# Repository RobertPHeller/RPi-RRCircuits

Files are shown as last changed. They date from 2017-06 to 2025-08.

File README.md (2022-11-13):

# RPi-RRCircuits

This is a collection of Model Railroad open hardware and open source projects,
using LCC, OpenMRN, and OpenMRN-lite, for the following MCUs and SBCs:

Raspberry Pi, generally as HATs for the "B" flavors (RPi2B, RPi3B and RPi4B).
  (Directories with "HAT" at the end are for these boards.)

Beagle boards, including capes for BeagleBone Black and baseboards for
  PocketBeagles.
  (Directories with "CAPE" at the end are for BeagleBone Blacks,
   directories starting with "BBB" are also boards for the BeagleBone Black,
   directories starting with "PB" or "PocketBeagle" are for the PocketBeagles -
   these boards assume male header pins soldered to the bottom of the 
   PocketBeagle that insert into female header sockets on the base board.)

ESP32 (mostly meant for the Lilygo TTGO-T1 board)
  (Directories starting with "ESP32" are for this board.)

There are a few projects for other boards, including MetroMini (an Adafruit 
mini board that is a Arduino UNO clone), Tiva, and STM's Nucleo board.  The 
directory names will include the name of the board.

Directories ending in OpenMRN contain the Raspberry Pi and Beagle board
software for the various boards.  

These projects were created using Kicad 2013.06.11
(https://launchpad.net/kicad) under CentOS 6 and Kicad 4.0.7 under Ubuntu
18.04. Each subdirectory is one project, and contains a schematic and PCB
design or contains a program for one (or more) projects. There is also
software for the boards using OpenMRN (C++ library for OpenLCB/LCC) for these
projects.

There is a README in each project dir.

## Availble Projects:

1. [16DriverOutputCape](https://github.com/RobertPHeller/RPi-RRCircuits/tree/master/16DriverOutputCape)

    > This is a MCP23017 with two octal buffers meant to drive 16 LEDs (such as 
    > signal lamps). No PWM or special effects.  This board is a Cape for a 
    > BeagleBone Black or Green.  Has address jumpers for the MCP23017 and can be 
    > stacked -- up to 8 of these capes for up to 128 LEDS -- each board has power 
    > terminals for the LEDs.

1. [16DriverOutputHAT](https://github.com/RobertPHeller/RPi-RRCircuits/tree/master/16DriverOutputHAT)

    > This is a MCP23017 with two octal buffers meant to drive 16 LEDs (such as 
    > signal lamps). No PWM or special effects.  This board is a HAT for a 
    > Raspberry Pi 2, 3, or 4.  Has address jumpers for the MCP23017 and can be 
    > stacked -- up to 8 of these hats for up to 128 LEDS -- each board has power 
    > terminals for the LEDs.

1. [16DriverOutputOpenMRN](https://github.com/RobertPHeller/RPi-RRCircuits/tree/master/16DriverOutputOpenMRN)

    > The is the OpenMRN (OpenLCB/LCC) program code for the 16DriverOutput HAT or 
    > Cape boards. Can be build on either a BeagleBoard or a Raspberry Pi for 
    > either. 

1. [16LEDDriver23017SMD](https://github.com/RobertPHeller/RPi-RRCircuits/tree/master/16LEDDriver23017SMD)

    > This is a SMD variant of 16DriverOutputHAT.

1. [16PWMLedDriverCape](https://github.com/RobertPHeller/RPi-RRCircuits/tree/master/16PWMLedDriverCape)

    > This is a PCA9685 with two octal buffers meant to drive 16 LEDs (such as 
    > signal lamps).  This board is much like 16DriverOutputHat, but uses a PWM chip 
    > to allow for special effects and allows for brightness adjustment.  Has 
    > address jumpers for the PCA9685 and can be stacked -- up to 64 boards (WOW) 
    > for up to 1024 LEDs (WOW) -- each board has power terminals for the LEDs.

1. [16PWMLedDriverHat](https://github.com/RobertPHeller/RPi-RRCircuits/tree/master/16PWMLedDriverHat)

    > This is a PCA9685 with two octal buffers meant to drive 16 LEDs (such as 
    > signal lamps).  This board is much like 16DriverOutputHat, but uses a PWM chip 
    > to allow for special effects and allows for brightness adjustment.  Has 
    > address jumpers for the PCA9685 and can be stacked -- up to 64 boards (WOW) 
    > for up to 1024 LEDs (WOW) -- each board has power terminals for the LEDs.

1. [16PWMLedDriverOpenMRN](https://github.com/RobertPHeller/RPi-RRCircuits/tree/master/16PWMLedDriverOpenMRN)

    > This is the OpenMRN (OpenLCB/LCC) program for the 16PWMLedDriver* boards (RPi
    > Hat, BBB Cape, and PocketBeagle board). Can be build on either a BeagleBoard 
    > or a Raspberry Pi for either.

1. [16PWMLedDriverPocketBeagle](https://github.com/RobertPHeller/RPi-RRCircuits/tree/master/16PWMLedDriverPocketBeagle)

    > This is a PCA9685 with two octal buffers meant to drive 16 LEDs (such as
    > signal lamps). This board is much like 16DriverOutputCape, but uses a PWM chip
    > to allow for special effects and allows for brightness adjustment. Has address
    > jumpers for the PCA9685, includes a CAN transceiver with LCC network
    > connectors (RJ45s), 5V power supply for the PocketBeagle, and uses LCC power
    > for the LEDS. It uses female headers for the PocketBeagle (presumes male pin
    > headers soldered to the underside of the PocketBeagle).

1. [BBBCommandStation](https://github.com/RobertPHeller/RPi-RRCircuits/tree/master/BBBCommandStation)

    > Early BeagleBone Black LCC/DCC Command Station board set -- two boards, a cape 
    > and a power board.  Does not include RailComm support.

1. [BBBCommandStationOpenMRN](https://github.com/RobertPHeller/RPi-RRCircuits/tree/master/BBBCommandStationOpenMRN)

    > This is the program for the Beagle Board LCC/DCC/Railcom command 
    > station.  It uses OpenMRN to interface with tha LCC/OpenLCB network
    > to implement a LCC/OpenLCB aware command station node that can 
    > operate DCC/Railcom locomotives.  It should work with any of the
    > Beagle Board addon boards I have designed.  It uses the AM335X's
    > PRUs to generate the DCC signals.  It ises the OpenMRN Console
    > class to communicate over a Tcp/Ip channel with a Tcl/Tk coded
    > GUI program to provide a user friendly point-and-click high level
    > user interface.  

1. [BBBHalfSiding](https://github.com/RobertPHeller/RPi-RRCircuits/tree/master/BBBHalfSiding)

    > Early HalfSiding cape for the Beagle Bone Black. A somewhat all-in-one board
    > for the Beagle Bone Black to manage one half of a siding. This something of a
    > "kitchen sink" board and proably awkard in practice. Probably better off
    > stacking several separate special purpose capes.  I mostly did this as a 
    > "thought experiment" to see what this would look like.  Oh, if it used SMD 
    > parts it might be more compact and might be practical as a single board.

1. [ButtonHat](https://github.com/RobertPHeller/RPi-RRCircuits/tree/master/ButtonHat)

    > This is a RPi HAT board to interface up to 12 push buttons with hardware 
    > debouncing (using 74ahc14 Hex Schmitt-Trigger Inverters) to a RPi.  Jumpers 
    > are used to map the buttons to GPIO pins.  This was a simple "thought 
    > experiment" to see if this was possible.

1. [CANHat](https://github.com/RobertPHeller/RPi-RRCircuits/tree/master/CANHat)

    > This is the original CAN Hat, using the MCP2515 CAN IF Chip and a MCP2551 
    > transceiver chip.

1. [CANHat2](https://github.com/RobertPHeller/RPi-RRCircuits/tree/master/CANHat2)

    > This is the second incarnation of the CAN Hat, also using the MCP2515 and 
    > MCP2551 chips.

1. [CANHat3](https://github.com/RobertPHeller/RPi-RRCircuits/tree/master/CANHat3)

    > This is the third incarnation of the CAN Hat, also using the MCP2515 and 
    > MCP2551 chips.

1. [DCCOD_SMD](https://github.com/RobertPHeller/RPi-RRCircuits/tree/master/DCCOD_SMD)

    > Single current sensing occupancy detector, meant for ESP32-16xDCCOD or 
    > simular.  Meant as a thought experiment to see what this would cost, etc.

1. [DCCShield](https://github.com/RobertPHeller/RPi-RRCircuits/tree/master/DCCShield)

    > Simple DCC driver shield for Arduino.

1. [DCCTiva](https://github.com/RobertPHeller/RPi-RRCircuits/tree/master/DCCTiva)

    > Simple DCC Driver board for Tiva.

1. [DualUncouplerHAT](https://github.com/RobertPHeller/RPi-RRCircuits/tree/master/DualUncouplerHAT)

    > This a dual driver for a electromagnetic uncoupler coil.  It features a 
    > pair of 555 type timers (in the form of a 556 dual timer) driving a TIP120 
    > power darlington.  It uses GPIO pins 21 and 22 (BCM 5 and 6, physical pins 
    > 29 and 31).

1. [DualUncouplerHAT1](https://github.com/RobertPHeller/RPi-RRCircuits/tree/master/DualUncouplerHAT1)

    > This is the same as DualUncouplerHAT, except it uses GPIO pins 23 and 24 
    > (BCM 13 and 19, physical pins 33 and 35).

1. [ESP32-16LedDriver](https://github.com/RobertPHeller/RPi-RRCircuits/tree/master/ESP32-16LedDriver)

    > 16 on/off LED Driver board using a MCP23017.

1. [ESP32-16PWMLedDriver](https://github.com/RobertPHeller/RPi-RRCircuits/tree/master/ESP32-16PWMLedDriver)

    > 16 LED PWM driver board using a PCA9685.

1. [ESP32-16xDCCOD](https://github.com/RobertPHeller/RPi-RRCircuits/tree/master/ESP32-16xDCCOD)

    > Backplane for up to 16 DCCOD_SMD's using a ESP32 MCU.  Meant as a thought 
    > experiment to see what this would cost, etc.

1. [ESP32-C3-Booster](https://github.com/RobertPHeller/RPi-RRCircuits/tree/master/ESP32-C3-Booster)

    > ESP32 C3 based DCC Booster.

1. [ESP32-C3-BoosterOpenMRNIDF](https://github.com/RobertPHeller/RPi-RRCircuits/tree/master/ESP32-C3-BoosterOpenMRNIDF)

    > 

1. [ESP32-D0WD-V3-MultiFunctionOpenMRNIDF](https://github.com/RobertPHeller/RPi-RRCircuits/tree/master/ESP32-D0WD-V3-MultiFunctionOpenMRNIDF)

    > 

1. [ESP32-HalfSiding](https://github.com/RobertPHeller/RPi-RRCircuits/tree/master/ESP32-HalfSiding)

    > First draft of a ESP32 HalfSiding node using a MCP23017 on/off signal lamps.

1. [ESP32-MultiFunction](https://github.com/RobertPHeller/RPi-RRCircuits/tree/master/ESP32-MultiFunction)

    > This is a circuit board that supports an ESP32 Dev Kit board or TTGO-T1 board
    > to manage a range of possible interlocking plants or other model railroad
    > situations. It contains four stall motor drivers with point sense, four CT
    > Coil type occupancy detectors, four Schmitt-Trigger inputs (for push buttons),
    > four driver outputs, and 16 PWM LED drivers.

1. [ESP32-PWMHalfSiding](https://github.com/RobertPHeller/RPi-RRCircuits/tree/master/ESP32-PWMHalfSiding)

    > This is a circuit board that supports an ESP32 Dev Kit board or TTGO-T1 board 
    > to manage one half (one end) of a siding.  This board can also be used to 
    > manage two bi-directional single track ABS blocks or one bi-directional dual 
    > track ABS block.  There are other trackwork cases this board can handle as 
    > well.  

1. [ESP32-PWMHalfSidingSMD-T7](https://github.com/RobertPHeller/RPi-RRCircuits/tree/master/ESP32-PWMHalfSidingSMD-T7)

    > This is a circuit board that supports an ESP32 Dev Kit board or TTGO-T1 board 
    > to manage one half (one end) of a siding.  This board can also be used to 
    > manage two bi-directional single track ABS blocks or one bi-directional dual 
    > track ABS block.  There are other trackwork cases this board can handle as 
    > well.  

1. [ESP32-PWMHalfSidingSMD](https://github.com/RobertPHeller/RPi-RRCircuits/tree/master/ESP32-PWMHalfSidingSMD)

    > This is a circuit board that supports an ESP32 Dev Kit board or TTGO-T1 board 
    > to manage one half (one end) of a siding.  This board can also be used to 
    > manage two bi-directional single track ABS blocks or one bi-directional dual 
    > track ABS block.  There are other trackwork cases this board can handle as 
    > well.  

1. [ESP32-S3-MultiFunction](https://github.com/RobertPHeller/RPi-RRCircuits/tree/master/ESP32-S3-MultiFunction)

    > This is a LCC node circuit board that is based around an Espressif ESP32-S3FN8
    > MCU to manage and operate a collection of model railroad sensors and
    > actuators. 

1. [ESP32-S3-MultiFunctionOpenMRNIDF](https://github.com/RobertPHeller/RPi-RRCircuits/tree/master/ESP32-S3-MultiFunctionOpenMRNIDF)

    > 

1. [ESP32_mini_KiCad_Library](https://github.com/RobertPHeller/RPi-RRCircuits/tree/master/ESP32_mini_KiCad_Library)

    > KiCad symbol and footprint for the ESP32 Mini, the ESP32 clone of the Wemos D1 mini with more pins and more power!
    > There is some info on the boards [here](https://www.reddit.com/r/esp8266/comments/a93raj/wemos_ttgo_mini_d1_esp32/). It seems to be a Wemos clone, but is def. not made by them. I really like the boards for the small size and cheap price while giving me the power of an ESP32 and much more IO compared to the Wemos D1 mini.

1. [ESP32ABSBoard](https://github.com/RobertPHeller/RPi-RRCircuits/tree/master/ESP32ABSBoard)

    > ESP32 ABS (Automatic Block Signal) board.  Very simple board: one block 
    > detector, 8 LED drivers.

1. [ESP32BaseBoard](https://github.com/RobertPHeller/RPi-RRCircuits/tree/master/ESP32BaseBoard)

    > ESP32 Base board.  Base starting point for a ESP32 node.

1. [ESP32MRNSketches](https://github.com/RobertPHeller/RPi-RRCircuits/tree/master/ESP32MRNSketches)

    > ESP32 Arduino / OpenMRNLite sketches for the ESP32 boards.

1. [ESP32QuadOCDect](https://github.com/RobertPHeller/RPi-RRCircuits/tree/master/ESP32QuadOCDect)

    > ESP32 Quad Occupancy Detector node.

1. [ESP32QuadSMCSense](https://github.com/RobertPHeller/RPi-RRCircuits/tree/master/ESP32QuadSMCSense)

    > ESP32 Quad Stall Motor w/ sense node.

1. [LCCCANCape](https://github.com/RobertPHeller/RPi-RRCircuits/tree/master/LCCCANCape)

    > LCC/CAN Transceiver Cape for the Beagle Bone.

1. [LEDDriverHat](https://github.com/RobertPHeller/RPi-RRCircuits/tree/master/LEDDriverHat)

    > Eight LED drivers.  Jumpers to select GPIO pins.

1. [MCP23017Hat](https://github.com/RobertPHeller/RPi-RRCircuits/tree/master/MCP23017Hat)

    > This is a 16 pin I2C port expander using a MCP230017.

1. [OpenMRNIDF](https://github.com/RobertPHeller/RPi-RRCircuits/tree/master/OpenMRNIDF)

    > This is an exported version of the OpenMRN library for the ESP32 which is
    > usable as an ESP-IDF component.

1. [PBCommandStation](https://github.com/RobertPHeller/RPi-RRCircuits/tree/master/PBCommandStation)

    > Original through hole version of the Pocket Beagle LCC/DCC Command Station.
    > This design is depreciated -- see PocketBeagleCommandStation and 
    > PocketBeagleCommandStation_SMD for a current design.

1. [PocketBeagleCommandStation](https://github.com/RobertPHeller/RPi-RRCircuits/tree/master/PocketBeagleCommandStation)

    > Through hole version of the PocketBeagle LCC/DCC Command Station. This is a
    > DCC command station that is a LCC node. It implements the OpenLCB train
    > protocol node over LCC and converts that to DCC commands. It includes a
    > booster and puts the DCC signal on the LCC bus (pins 4 and 5). It implements a
    > programming track and implements Railcom. The Command Station uses a
    > PocketBeagle as the processing element and uses the PRUs (Programmable
    > Realtime Units) to generate the DCC signal. (See
    > [PocketBeagleCommandStation_SMD](https://github.com/RobertPHeller/RPi-RRCircuits/tree/master/PocketBeagleCommandStation_SMD)
    > for a SMD version.)

1. [PocketBeagleCommandStation_SMD](https://github.com/RobertPHeller/RPi-RRCircuits/tree/master/PocketBeagleCommandStation_SMD)

    > SMD version of the PocketBeagle LCC/DCC Command Station.  This is a
    > DCC command station that is a LCC node. It implements the OpenLCB train
    > protocol node over LCC and converts that to DCC commands. It includes a
    > booster and puts the DCC signal on the LCC bus (pins 4 and 5). It implements a
    > programming track and implements Railcom. The Command Station uses a
    > PocketBeagle as the processing element and uses the PRUs (Programmable
    > Realtime Units) to generate the DCC signal. (See
    > [PocketBeagleCommandStation](https://github.com/RobertPHeller/RPi-RRCircuits/tree/master/PocketBeagleCommandStation)
    > for a through hole version.)

1. [PocketBeagleMultifuntion](https://github.com/RobertPHeller/RPi-RRCircuits/tree/master/PocketBeagleMultifuntion)

    > This is a circuit board that supports a PocketBeagle board to manage a range
    > of possible interlocking plants or other model railroad situations. It
    > contains four stall motor drivers with point sense, four CT Coil type
    > occupancy detectors, four Schmitt-Trigger inputs (for push buttons), four
    > driver outputs, 8 GPIO pins in a 5x2 header, and 16 PWM LED drivers. 

1. [PocketBeagleMultifuntionOpenMRN](https://github.com/RobertPHeller/RPi-RRCircuits/tree/master/PocketBeagleMultifuntionOpenMRN)

    > OpenMRN program for the PocketBeagleMultifuntion board.

1. [PocketBeagleQuadOCDect](https://github.com/RobertPHeller/RPi-RRCircuits/tree/master/PocketBeagleQuadOCDect)

    > PocketBeagle Quad Occupancy Detector.

1. [PocketBeagleQuadSMCSense](https://github.com/RobertPHeller/RPi-RRCircuits/tree/master/PocketBeagleQuadSMCSense)

    > PocketBeagle Quad Stall Motor w/ Sense.

1. [QuadOCDectCape](https://github.com/RobertPHeller/RPi-RRCircuits/tree/master/QuadOCDectCape)

    > Quad Occupancy detector Cape (for a Beagle Bone).

1. [QuadOCDectHat](https://github.com/RobertPHeller/RPi-RRCircuits/tree/master/QuadOCDectHat)

    > Quad Occupancy detector Hat for Raspberry Pi.

1. [QuadOCDectOpenMRN](https://github.com/RobertPHeller/RPi-RRCircuits/tree/master/QuadOCDectOpenMRN)

    > OpenMRN (LCC / OpenLCB) program for Quad Occupancy Detector boards for Linux
    > SBCs.

1. [QuadSMC](https://github.com/RobertPHeller/RPi-RRCircuits/tree/master/QuadSMC)

    > This is a generic quad verison of SMCSenseHAT.

1. [QuadSMCSenseCape](https://github.com/RobertPHeller/RPi-RRCircuits/tree/master/QuadSMCSenseCape)

    > Quad Stall Motor w/ Sense Cape for a Beagle Bone.

1. [QuadSMCSenseHat](https://github.com/RobertPHeller/RPi-RRCircuits/tree/master/QuadSMCSenseHat)

    > Quad Stall Motor w/ Sense Hat for a Raspberry Pi.

1. [QuadSMCSenseOpenMRN](https://github.com/RobertPHeller/RPi-RRCircuits/tree/master/QuadSMCSenseOpenMRN)

    > OpenMRN (LCC / OpenLCB) program for Linux SBC with QuadSMCSense addon boards.

1. [QuadUncoupler](https://github.com/RobertPHeller/RPi-RRCircuits/tree/master/QuadUncoupler)

    > This is a generic qad version of DualUncouplerHAT.

1. [SignalHAT](https://github.com/RobertPHeller/RPi-RRCircuits/tree/master/SignalHAT)

    > This is a hat containing a MAX7221 driven off level shifted SPI.  It can 
    > drive up to 8 common-cathode signals of up to 8 LEDs each.

1. [SMCSenseHAT](https://github.com/RobertPHeller/RPi-RRCircuits/tree/master/SMCSenseHAT)

    > This is a dual stall motor driver and point sense circuit.  The stall 
    > motor driver uses a MPQ3725A transistor to allow driving either multiple 
    > Tortoises in parallel (eg for a crossover) or newer Switchmaster or 
    > Torquemaster which draw more current than the LM324 can handle.  Also 
    > included is a point sense circuit built from a RS Flip Flop made from 
    > 2-input NAND gates.  The point sense circuit expects to be connected to a 
    > single pole double throw switch, either a built in one in the Tortoise or 
    > an external one attached to the points themselves.  Uses GPIO 0, 1, 2, and 
    > 3.

1. [SMCSenseHAT1](https://github.com/RobertPHeller/RPi-RRCircuits/tree/master/SMCSenseHAT1)

    > This is the same as SMCSenseHAT, except uses GPIO 4, 5, 6, and 7.

1. [TivaMultiFunctionBoard](https://github.com/RobertPHeller/RPi-RRCircuits/tree/master/TivaMultiFunctionBoard)

    > This is a circuit board that supports a Tiva LaunchPad MCU to manage a range
    > of possible interlocking plants or other model railroad situations. It
    > contains four stall motor drivers with point sense, four CT Coil type
    > occupancy detectors, four Schmitt-Trigger inputs (for push buttons), four
    > driver outputs, 8 GPIO pins in a 5x2 header, and 16 PWM LED drivers. 

1. [UniversalLCCNodeBreakout](https://github.com/RobertPHeller/RPi-RRCircuits/tree/master/UniversalLCCNodeBreakout)

    > This is a "breakout board" for use in breadboarding LCC nodes, typically using breadboard friendly MCU Dev Boards.  This board contains a 5V power supply taking from the LCC network.  It also contains a CAN transceiver and contains a pair of RJ45 connectors.  There is CAN termination and a place for a socket to access pins 4 and 5 ("Alt" pins) on the LCC network bus.

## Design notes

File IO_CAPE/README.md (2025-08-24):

# Simple I/O cape.

Two 2x5 shrouded headers:

## Header J1: 

- Pin 1: GPIO 115 (yellow)
- Pin 2: GPIO 49  (green)
- Pin 3: GPIO 112 (grey)
- Pin 4: GPIO 117 (white)
- Pin 5: Ground (black)
- Pin 6: +3.3V  (pink)
- Pin 7: GPIO 47 (orange)
- Pin 8: GPIO 45 (ochre)
- Pin 9: GPIO 46 (cyan)
- Pin 10: GPIO 44 (brown)

## Header J2:

- Pin 1: GPIO 50 (EHRPWM1A) (yellow)
- Pin 2: GPIO 60 (green)
- Pin 3: GPIO 51 (EHRPWM1B) (grey)
- Pin 4: GPIO 48 (white)
- Pin 5: Ground (black)
- Pin 6: +3.3V  (pink)
- Pin 7: GPIO 69 (orange)
- Pin 8: GPIO 66 (ochre)
- Pin 9: GPIO 68 (cyan)
- Pin 10: GPIO 67 (brown)

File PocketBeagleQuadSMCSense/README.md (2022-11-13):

# PocketBeagleQuadSMCSense

PocketBeagle Quad Stall Motor w/ Sense.

* [Order this board from The Country Robot](https://www.thecountryrobot.com/product/quad-stall-motor-control-and-sense-for-pocket-beagle-bare-circuit-board-w-doc/)
* [Order this board from PCBWay](https://www.pcbway.com/project/shareproject/Pocket_Beagle_Quad_StallMotor_w_Sense_base_board__includes_LCC_CAN_and_power_supply.html)

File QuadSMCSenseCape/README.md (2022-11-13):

# QuadSMCSenseCape

Quad Stall Motor w/ Sense Cape for a Beagle Bone.

* [Order this board from The Country Robot](https://www.thecountryrobot.com/product/quad-stall-motor-control-and-sense-cape-for-beagle-bare-circuit-board-w-doc/)
* [Order this board from PCBWay](https://www.pcbway.com/project/shareproject/Quad_Stall_motor_with_point_sense_cape.html)

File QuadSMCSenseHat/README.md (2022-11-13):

# QuadSMCSenseHat

Quad Stall Motor w/ Sense Hat for a Raspberry Pi.

* [Order this board from The Country Robot](https://www.thecountryrobot.com/product/quad-stall-motor-control-and-sense-hat-for-rpi-bare-circuit-board-w-doc/)
* [Order this board from PCBWay](https://www.pcbway.com/project/shareproject/Quad_Stall_Motor_Controller_w__point_Sense__hat_.html)

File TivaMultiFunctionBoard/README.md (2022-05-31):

# TivaMultiFunctionBoard

This is a circuit board that supports a Tiva LaunchPad MCU to manage a range
of possible interlocking plants or other model railroad situations. It
contains four stall motor drivers with point sense, four CT Coil type
occupancy detectors, four Schmitt-Trigger inputs (for push buttons), four
driver outputs, 8 GPIO pins in a 5x2 header, and 16 PWM LED drivers. 
                                                  
The board contains these I/O sections:

- Four occupancy detectors.  These are current transformer based for DCC.
- Four stall-motor with point sense.
- Four Schmitt-Trigger inputs, typically for facia push buttons.
- Four driver outputs, typically for facia lamps (LEDs).
- Eight GPIO pins brought out to a 5x2 header.
- Sixteen PWM Led drivers.  These are meant to light lamps in signal heads. 

This board uses 24 GPIO pins and one I2C channel:

- **PD7** OD1
- **PF4** OD2
- **PA5** OD3
- **PB2** OD4
- **PC5** Motor1
- **PC6** Motor2
- **PC7** Motor3
- **PD6** Motor4
- **PF2** Points1
- **PF3** Points2
- **PB3** Points3
- **PC4** Points4
- **PD0** LED1
- **PD1** LED2
- **PD2** LED3
- **PD3** LED4
- **PE1** Button1
- **PE2** Button2
- **PE3** Button3
- **PF1** Button4
- **PE0** GPIO8
- **PF0** GPIO7
- **PB4** GPIO6
- **PB7** GPIO5
- **PB6** GPIO4
- **PA4** GPIO3
- **PA3** GPIO2
- **PA2** GPIO1
- **I2C1 Address 0x40** A PCA9685 16-channel, 12-bit PWM LED Controller

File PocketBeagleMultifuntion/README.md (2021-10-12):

# PocketBeagleMultifuntion

This is a circuit board that supports a PocketBeagle board to manage a range
of possible interlocking plants or other model railroad situations. It
contains four stall motor drivers with point sense, four CT Coil type
occupancy detectors, four Schmitt-Trigger inputs (for push buttons), four
driver outputs, 8 GPIO pins in a 5x2 header, and 16 PWM LED drivers. 
                                                  
The board contains these I/O sections:

- Four occupancy detectors.  These are current transformer based for DCC.
- Four stall-motor with point sense.
- Four Schmitt-Trigger inputs, typically for facia push buttons.
- Four driver outputs, typically for facia lamps (LEDs).
- Eight GPIO pins brought out to a 5x2 header.
- Sixteen PWM Led drivers.  These are meant to light lamps in signal heads. 

This board uses 24 GPIO pins and one I2C channel:

- **GPIO7** Occupancy Detector 1.
- **GPIO19** Occupancy Detector 2.
- **GPIO20** Occupancy Detector 3.
- **GPIO23** Occupancy Detector 4.
- **GPIO26** Motor Select 1: select the position of stall motor 1.
- **GPIO27** Motor Select 1: select the position of stall motor 2.
- **GPIO45** Motor Select 1: select the position of stall motor 3.
- **GPIO46** Motor Select 1: select the position of stall motor 4.
- **GPIO47** Point Sense 1: return the state of the points for stall motor 1.
- **GPIO48** Point Sense 1: return the state of the points for stall motor 2.
- **GPIO50** Point Sense 1: return the state of the points for stall motor 3.
- **GPIO52** Point Sense 1: return the state of the points for stall motor 4.
- **GPIO57** Schmitt trigger input 1.
- **GPIO58** Schmitt trigger input 2.
- **GPIO59** Schmitt trigger input 3.
- **GPIO60** Schmitt trigger input 4.
- **GPIO64** Driver (LED) 1.
- **GPIO65** Driver (LED) 2.
- **GPIO86** Driver (LED) 3.
- **GPIO87** Driver (LED) 4.
- **GPIO110** GPIO Line 1.
- **GPIO111** GPIO Line 2.
- **GPIO112** GPIO Line 3.
- **GPIO113** GPIO Line 4.
- **GPIO114** GPIO Line 5.
- **GPIO115** GPIO Line 6.
- **GPIO116** GPIO Line 7.
- **GPIO117** GPIO Line 8.
- **I2C1 Address 0x40** A PCA9685 16-channel, 12-bit PWM LED Controller

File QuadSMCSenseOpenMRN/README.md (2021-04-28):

# QuadSMCSenseOpenMRN

OpenMRN (LCC / OpenLCB) program for Linux SBC with QuadSMCSense addon boards.

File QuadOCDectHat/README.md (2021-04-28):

# QuadOCDectHat

Quad Occupancy detector Hat for Raspberry Pi.

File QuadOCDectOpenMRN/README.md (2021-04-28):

# QuadOCDectOpenMRN

OpenMRN (LCC / OpenLCB) program for Quad Occupancy Detector boards for Linux
SBCs.

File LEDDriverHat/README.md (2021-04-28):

# LEDDriverHat

Eight LED drivers.  Jumpers to select GPIO pins.

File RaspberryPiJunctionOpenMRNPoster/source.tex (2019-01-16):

%%%%%%%%%%%%%%%%%%%%%%%%%%%%%%%%%%%%%%%%%%%%%%%%%%%%%%%%%%%%%%%%%%%%%%%%%%%%%
%
%  System        : 
%  Module        : 
%  Object Name   : $RCSfile$
%  Revision      : $Revision$
%  Date          : $Date$
%  Author        : $Author$
%  Created By    : Robert Heller
%  Created       : Sat Jul 15 10:35:16 2017
%  Last Modified : <190116.1243>
%
%  Description 
%
%  Notes
%
%  History
% 
%%%%%%%%%%%%%%%%%%%%%%%%%%%%%%%%%%%%%%%%%%%%%%%%%%%%%%%%%%%%%%%%%%%%%%%%%%%%%
%
%    Copyright (C) 2017  Robert Heller D/B/A Deepwoods Software
%			51 Locke Hill Road
%			Wendell, MA 01379-9728
%
%    This program is free software; you can redistribute it and/or modify
%    it under the terms of the GNU General Public License as published by
%    the Free Software Foundation; either version 2 of the License, or
%    (at your option) any later version.
%
%    This program is distributed in the hope that it will be useful,
%    but WITHOUT ANY WARRANTY; without even the implied warranty of
%    MERCHANTABILITY or FITNESS FOR A PARTICULAR PURPOSE.  See the
%    GNU General Public License for more details.
%
%    You should have received a copy of the GNU General Public License
%    along with this program; if not, write to the Free Software
%    Foundation, Inc., 675 Mass Ave, Cambridge, MA 02139, USA.
%
% 
%
%%%%%%%%%%%%%%%%%%%%%%%%%%%%%%%%%%%%%%%%%%%%%%%%%%%%%%%%%%%%%%%%%%%%%%%%%%%%%

% $Header: /cvsroot/latex-beamer/latex-beamer/solutions/conference-talks/conference-ornate-20min.en.tex,v 1.6 2004/10/07 20:53:08 tantau Exp $

%\documentclass[ignorenonframetext]{beamer}
%\documentclass[letterpaper]{article} \usepackage{beamerarticle}

% This file is a solution template for:

% - Talk at a conference/colloquium.
% - Talk length is about 20min.
% - Style is ornate.

% Copyright 2004 by Till Tantau <tantau@users.sourceforge.net>.
%
% In principle, this file can be redistributed and/or modified under
% the terms of the GNU Public License, version 2.
%
% However, this file is supposed to be a template to be modified
% for your own needs. For this reason, if you use this file as a
% template and not specifically distribute it as part of a another
% package/program, I grant the extra permission to freely copy and
% modify this file as you see fit and even to delete this copyright
% notice. 

\mode<presentation>
{
  \usetheme{Warsaw}
  \pgfdeclareimage[height=0.5cm]{deepwoods-software}{largeHeader}
  \logo{\pgfuseimage{deepwoods-software}}
  
  % or ...
}

\mode<article>{
  \usepackage{fullpage}
}

\usepackage[english]{babel}
% or whatever

\usepackage[latin1]{inputenc}
% or whatever

\usepackage{times}
\usepackage[T1]{fontenc}
% Or whatever. Note that the encoding and the font should match. If T1
% does not look nice, try deleting the line with the fontenc.
\usepackage{graphicx}

\title{Raspberry Pi Junction}

%\subtitle
%{Include Only If Paper Has a Subtitle}

\author{Robert Heller \\ \texttt{heller@deepsoft.com}}

\institute{Deepwoods Software}

\date{Winter, 2019}

%\subject{LCC CTC Panels}
% This is only inserted into the PDF information catalog. Can be left
% out. 

% If you have a file called "university-logo-filename.xxx", where xxx
% is a graphic format that can be processed by latex or pdflatex,
% resp., then you can add a logo as follows:

% \pgfdeclareimage[height=0.5cm]{university-logo}{university-logo-filename}
% \logo{\pgfuseimage{university-logo}}

% Delete this, if you do not want the table of contents to pop up at
% the beginning of each subsection:
%\AtBeginSubsection[]
%{
%  \begin{frame}<beamer>
%    \frametitle{Outline}
%    \tableofcontents[pausesections]
%  \end{frame}
%}

% If you wish to uncover everything in a step-wise fashion, uncomment
% the following command: 

%\beamerdefaultoverlayspecification{<+->}

\begin{document}

\begin{frame}
  \titlepage
\end{frame}

%\begin{frame}
%  \frametitle{Outline}
%  \tableofcontents
%  % You might wish to add the option [pausesections]
%\end{frame}

% Structuring a talk is a difficult task and the following structure
% may not be suitable. Here are some rules that apply for this
% solution: 

% - Exactly two or three sections (other than the summary).
% - At *most* three subsections per section.
% - Talk about 30s to 2min per frame. So there should be between about
%   15 and 30 frames, all told.

% - A conference audience is likely to know very little of what you
%   are going to talk about. So *simplify*!
% - In a 20min talk, getting the main ideas across is hard
%   enough. Leave out details, even if it means being less precise than
%   you think necessary.
% - If you omit details that are vital to the proof/implementation,
%   just say so once. Everybody will be happy with that.

\section{What it is}

This is Raspberry Pi Junction, a simple interlocking off the main line at Mile 
Post 314 that goes past the Mad Hatter Pie Shop.

The junction itself and the adjacent blocks are controlled by a Raspberry Pi 
Model 3 B+ (sirtopemhat), which has five HAT (Hardware Attached on Top) boards.

The HAT boards interface to the layout control elements on the layout. The
layout control elements include one Circuitron Tortoise stall-motor switch
machine, a Circuits4Tracks Quad Occupancy Detector, and six color light
signals.  Also the lighting of the Mad Hatter Pie Shop can be controlled by 
the Raspberry Pi.

\begin{frame}
   \frametitle{What it is}
   \begin{itemize}
   \item Raspberry Pi Junction is a simple spur off the main line at Mile Post 
   314 that goes past the Mad Hatter Pie Shop. 
   \item It and the adjacent blocks are controlled by a Raspberry Pi Model 3 
   B+ (sirtopemhat), which has five HAT (Hardware Attached on Top) boards.
   \item The HAT boards interface to the layout control elements on the 
   layout.
   \end{itemize}
\end{frame} 

\section{The basic layout}

\begin{frame}
   \frametitle{The basic layout}
   
\end{frame}

\section{The HATs}

Each of the HATs provide the hardware to interface the Pi to the control
elements on the layout. This is done using the GPIO pins on the Pi's 40-pin
GPIO header.  

\begin{frame}
   \frametitle{The HAT boards}
   \begin{description}
   \item[RTC Hat] This is just a DS1307 Real Time Clock module, used to keep 
   time when the Pi is shutdown.
   \item[SMCSenseHAT] This HAT controls the Circuitron Tortoise stall-motor 
   switch machine and sense its position.
   \item[QuadSSSQuadIn] This HAT provides the inputs for the Circuits4Tracks 
   Quad Occupancy Detector and also controls the structure light for the Mad 
   Hatter Pie Shop.
   \item[MCP23017Hat] There are two of these boards and they control the 
   lighting of the signals.
   \end{description}
\end{frame}

\subsection{SMCSenseHAT}

The SMCSenseHAT board uses GPIO pins to control and sense two Circuitron
Tortoise (or similar) stall-motor switch machines. Two GPIO pins drive the
stall-motors (one for each stall-motor) and two GPIO pins return the point
state for the stall-motors (one for each stall-motor). 

\begin{frame}
    \frametitle{The SMCSenseHAT board}
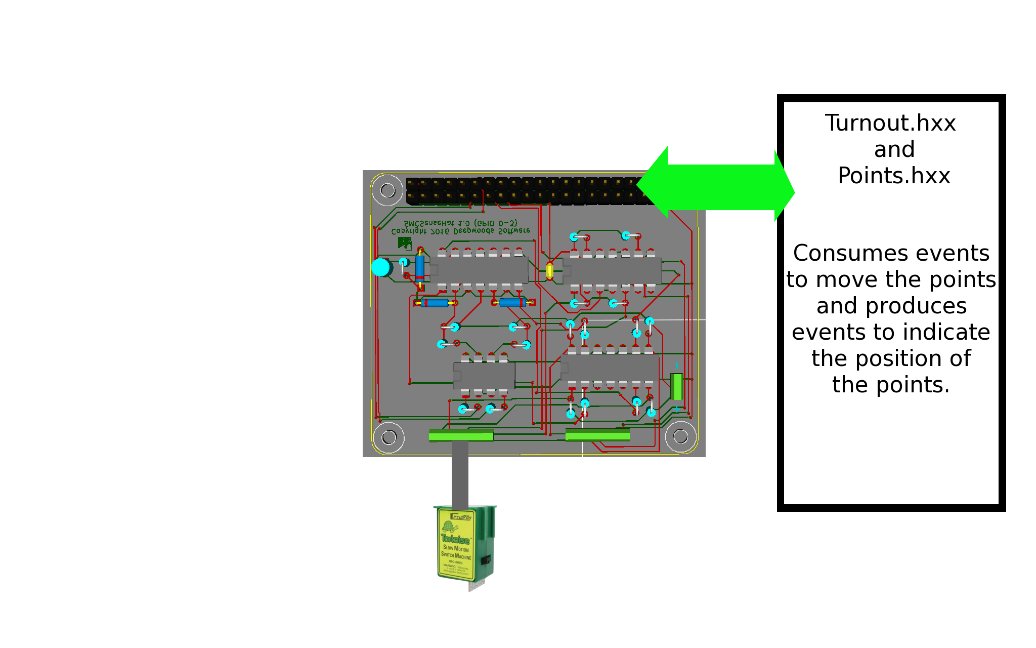
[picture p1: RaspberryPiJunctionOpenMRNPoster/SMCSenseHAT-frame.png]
    
\end{frame}

\subsection{QuadSSSQuadIn}

The QuadSSSQuadIn uses a MCP23008 I2C I/O expander chip to implement four 5V 
Logic inputs and four SSR (Solid State Relay) outputs.  The four inputs are 
connected to the Circuits4Tracks Quad Occupancy Detector's outputs and one of 
the SSR outputs controls the lighting of the Mad Hatter Pie Shop.

\begin{frame}
    \frametitle{The QuadSSSQuadIn board}
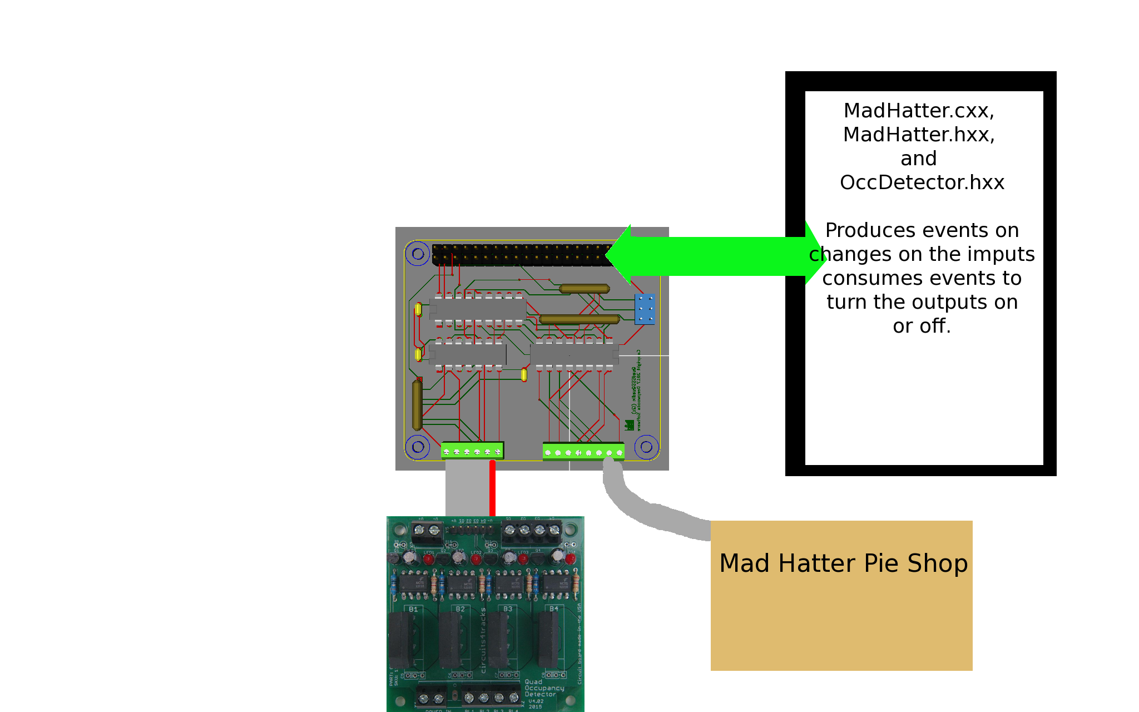
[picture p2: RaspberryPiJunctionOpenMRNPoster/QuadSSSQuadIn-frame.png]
    
\end{frame}

\subsection{MCP23017Hat}

The MCP23017Hat uses a MCP23017 I2C I/O expander chip to implement 16 3.3V 
GPIO pins, in two banks of 8.  There are two of these HATs and they are used 
to drive the 22 LEDs in the 6 signals.  There are three octal (8) LED driver 
boards to actually drive the LEDs.  

\begin{frame}
   \frametitle{The MCP23017Hat board}
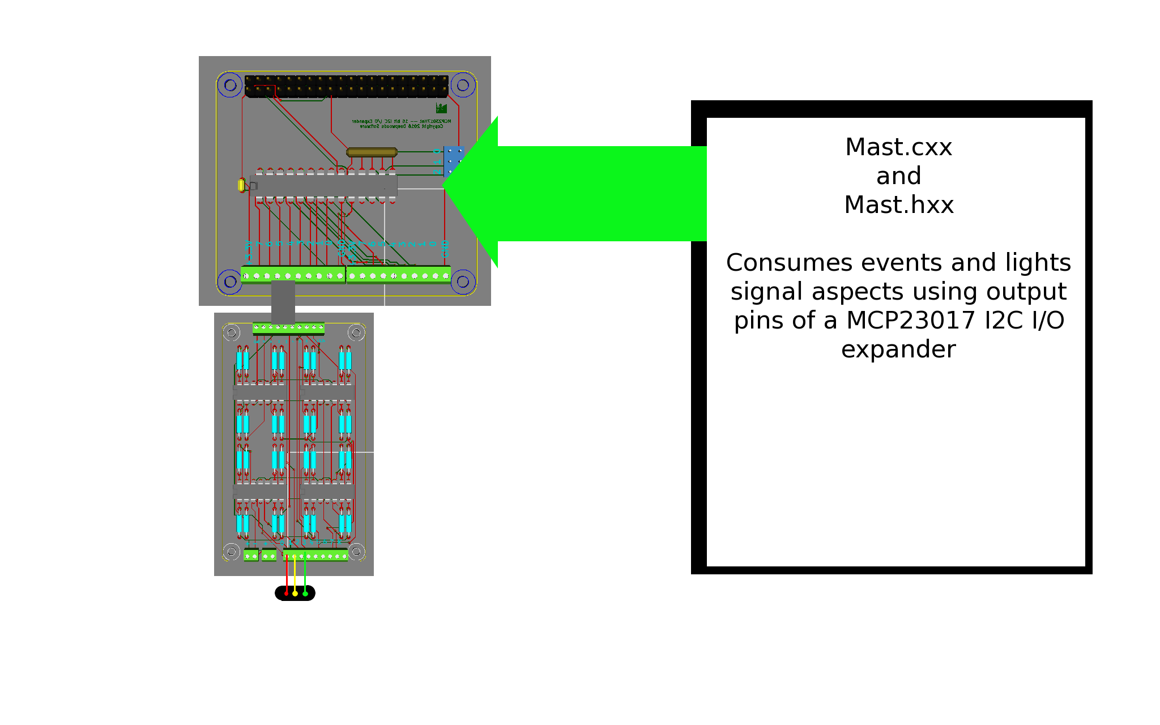
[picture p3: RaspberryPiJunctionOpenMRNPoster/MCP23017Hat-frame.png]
   
\end{frame}

\section{The LCC/OpenLCB network}

On the software side, the Raspberry Pi implements a ``virtual'' LCC/OpenLCB
``network''. The Model Railroad System from Deepwoods Software includes daemon
programs that interface to the HATs and to provide a virtual network for them
to communicate over. This includes a Tcp/Ip ``hub'' daemon and a program,
Dispatcher, that can be used to to create a CTC (Dispatcher) panel program.
The OpenMRN node daemon interfaces to the HATs and another program (that is
also a LCC node) that implements a CTC (Dispatcher) panel. Both of the nodes
communite with each other through the ``hub'' daemon by passing LCC Event
Report messages to each other. 

\begin{frame}
    \frametitle{The LCC/OpenLCB network}
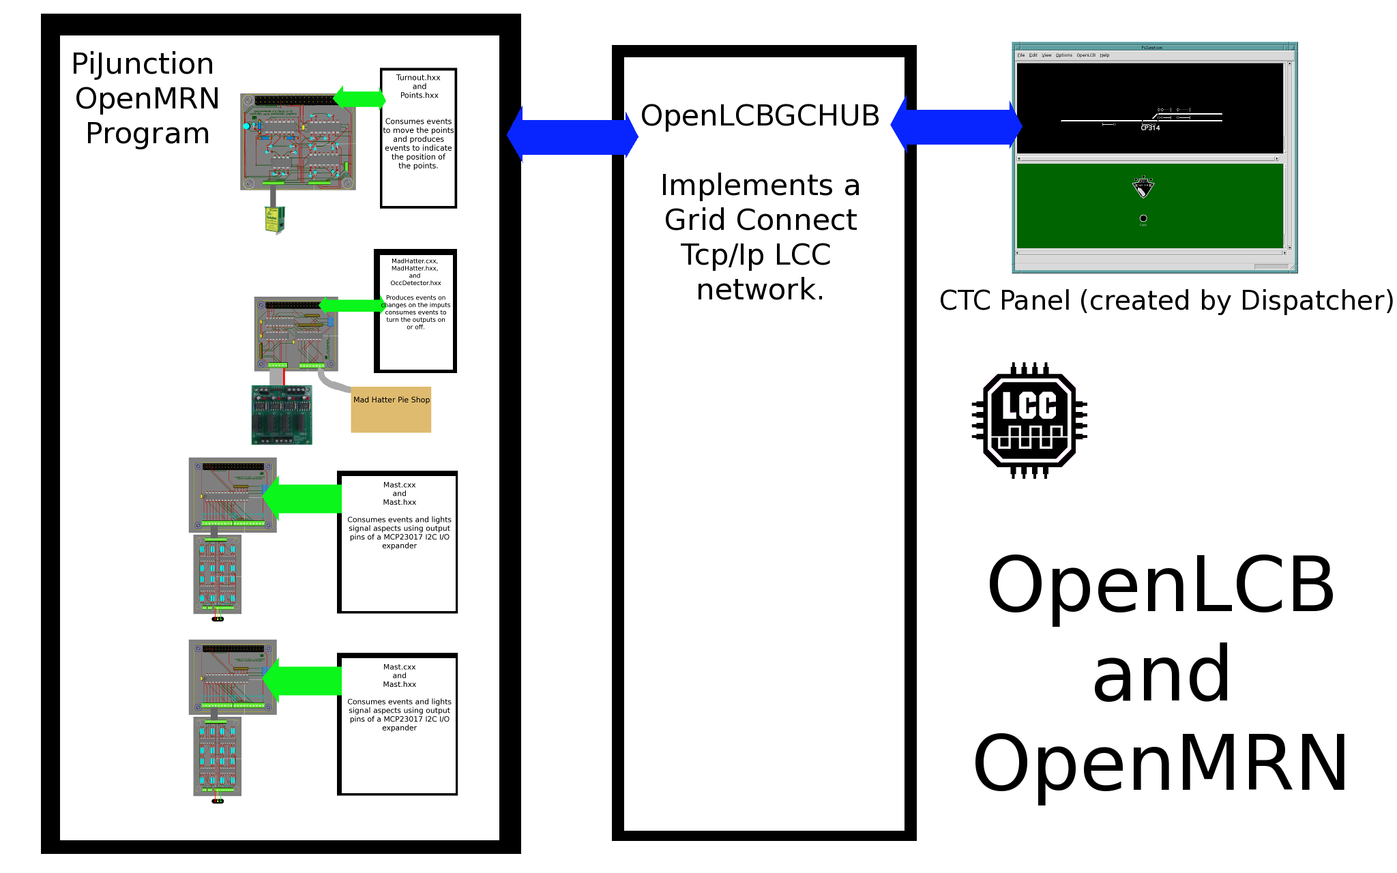
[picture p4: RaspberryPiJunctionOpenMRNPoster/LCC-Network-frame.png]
    
\end{frame}

\section{Traction control -- Driving the loco}

The locomotive is powered by DCC using a Lenz command station / booster.  I 
use a Pi Engineering Rail Driver in place of a DCC throtle.

The Rail Driver is a USB HID device and I use the Model Railrail System 
raildriverd daemon to drive it, using the Raildriver Support library and use 
the XPressNet library to talk to the Lenz command station / booster unit.

\begin{frame}
    \frametitle{Traction control}
    
\end{frame}

\end{document}

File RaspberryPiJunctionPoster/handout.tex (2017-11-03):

%%%%%%%%%%%%%%%%%%%%%%%%%%%%%%%%%%%%%%%%%%%%%%%%%%%%%%%%%%%%%%%%%%%%%%%%%%%%%
%
%  System        : 
%  Module        : 
%  Object Name   : $RCSfile$
%  Revision      : $Revision$
%  Date          : $Date$
%  Author        : $Author$
%  Created By    : Robert Heller
%  Created       : Sat Jul 15 10:35:16 2017
%  Last Modified : <170730.1748>
%
%  Description 
%
%  Notes
%
%  History
% 
%%%%%%%%%%%%%%%%%%%%%%%%%%%%%%%%%%%%%%%%%%%%%%%%%%%%%%%%%%%%%%%%%%%%%%%%%%%%%
%
%    Copyright (C) 2017  Robert Heller D/B/A Deepwoods Software
%			51 Locke Hill Road
%			Wendell, MA 01379-9728
%
%    This program is free software; you can redistribute it and/or modify
%    it under the terms of the GNU General Public License as published by
%    the Free Software Foundation; either version 2 of the License, or
%    (at your option) any later version.
%
%    This program is distributed in the hope that it will be useful,
%    but WITHOUT ANY WARRANTY; without even the implied warranty of
%    MERCHANTABILITY or FITNESS FOR A PARTICULAR PURPOSE.  See the
%    GNU General Public License for more details.
%
%    You should have received a copy of the GNU General Public License
%    along with this program; if not, write to the Free Software
%    Foundation, Inc., 675 Mass Ave, Cambridge, MA 02139, USA.
%
% 
%
%%%%%%%%%%%%%%%%%%%%%%%%%%%%%%%%%%%%%%%%%%%%%%%%%%%%%%%%%%%%%%%%%%%%%%%%%%%%%

% $Header: /cvsroot/latex-beamer/latex-beamer/solutions/conference-talks/conference-ornate-20min.en.tex,v 1.6 2004/10/07 20:53:08 tantau Exp $

%\documentclass[ignorenonframetext]{beamer}
\documentclass[letterpaper]{article} \usepackage{beamerarticle}

% This file is a solution template for:

% - Talk at a conference/colloquium.
% - Talk length is about 20min.
% - Style is ornate.

% Copyright 2004 by Till Tantau <tantau@users.sourceforge.net>.
%
% In principle, this file can be redistributed and/or modified under
% the terms of the GNU Public License, version 2.
%
% However, this file is supposed to be a template to be modified
% for your own needs. For this reason, if you use this file as a
% template and not specifically distribute it as part of a another
% package/program, I grant the extra permission to freely copy and
% modify this file as you see fit and even to delete this copyright
% notice. 

\mode<presentation>
{
  \usetheme{Warsaw}
  \pgfdeclareimage[height=0.5cm]{deepwoods-software}{largeHeader}
  \logo{\pgfuseimage{deepwoods-software}}
  
  % or ...
}

\mode<article>{
  \usepackage{fullpage}
}

\usepackage[english]{babel}
% or whatever

\usepackage[latin1]{inputenc}
% or whatever

\usepackage{times}
\usepackage[T1]{fontenc}
% Or whatever. Note that the encoding and the font should match. If T1
% does not look nice, try deleting the line with the fontenc.
\usepackage{graphicx}

\title{Raspberry Pi Junction}

%\subtitle
%{Include Only If Paper Has a Subtitle}

\author{Robert Heller \\ \texttt{heller@deepsoft.com}}

\institute{Deepwoods Software}

\date{Summer, 2017}

%\subject{LCC CTC Panels}
% This is only inserted into the PDF information catalog. Can be left
% out. 

% If you have a file called "university-logo-filename.xxx", where xxx
% is a graphic format that can be processed by latex or pdflatex,
% resp., then you can add a logo as follows:

% \pgfdeclareimage[height=0.5cm]{university-logo}{university-logo-filename}
% \logo{\pgfuseimage{university-logo}}

% Delete this, if you do not want the table of contents to pop up at
% the beginning of each subsection:
%\AtBeginSubsection[]
%{
%  \begin{frame}<beamer>
%    \frametitle{Outline}
%    \tableofcontents[pausesections]
%  \end{frame}
%}

% If you wish to uncover everything in a step-wise fashion, uncomment
% the following command: 

%\beamerdefaultoverlayspecification{<+->}

\begin{document}

\begin{frame}
  \titlepage
\end{frame}

%\begin{frame}
%  \frametitle{Outline}
%  \tableofcontents
%  % You might wish to add the option [pausesections]
%\end{frame}

% Structuring a talk is a difficult task and the following structure
% may not be suitable. Here are some rules that apply for this
% solution: 

% - Exactly two or three sections (other than the summary).
% - At *most* three subsections per section.
% - Talk about 30s to 2min per frame. So there should be between about
%   15 and 30 frames, all told.

% - A conference audience is likely to know very little of what you
%   are going to talk about. So *simplify*!
% - In a 20min talk, getting the main ideas across is hard
%   enough. Leave out details, even if it means being less precise than
%   you think necessary.
% - If you omit details that are vital to the proof/implementation,
%   just say so once. Everybody will be happy with that.

\section{What it is}

This is Raspberry Pi Junction, a simple interlocking off the main line at Mile 
Post 314 that goes past the Mad Hatter Pie Shop.

The junction itself and the adjacent blocks are controlled by a Raspberry Pi 
Model 3 B+ (sirtopemhat), which has five HAT (Hardware Attached on Top) boards.

The HAT boards interface to the layout control elements on the layout. The
layout control elements include one Circuitron Tortoise stall-motor switch
machine, a Circuits4Tracks Quad Occupancy Detector, and six color light
signals.  Also the lighting of the Mad Hatter Pie Shop can be controlled by 
the Raspberry Pi.

\begin{frame}
   \frametitle{What it is}
   \begin{itemize}
   \item Raspberry Pi Junction is a simple spur off the main line at Mile Post 
   314 that goes past the Mad Hatter Pie Shop. 
   \item It and the adjacent blocks are controlled by a Raspberry Pi Model 3 
   B+ (sirtopemhat), which has five HAT (Hardware Attached on Top) boards.
   \item The HAT boards interface to the layout control elements on the 
   layout.
   \end{itemize}
\end{frame} 

\section{The basic layout}

\begin{frame}
   \frametitle{The basic layout}
   
\end{frame}

\section{The HATs}

Each of the HATs provide the hardware to interface the Pi to the control
elements on the layout. This is done using the GPIO pins on the Pi's 40-pin
GPIO header.  

\begin{frame}
   \frametitle{The HAT boards}
   \begin{description}
   \item[RTC Hat] This is just a DS1307 Real Time Clock module, used to keep 
   time when the Pi is shutdown.
   \item[SMCSenseHAT] This HAT controls the Circuitron Tortoise stall-motor 
   switch machine and sense its position.
   \item[QuadSSSQuadIn] This HAT provides the inputs for the Circuits4Tracks 
   Quad Occupancy Detector and also controls the structure light for the Mad 
   Hatter Pie Shop.
   \item[MCP23017Hat] There are two of these boards and they control the 
   lighting of the signals.
   \end{description}
\end{frame}

\subsection{SMCSenseHAT}

The SMCSenseHAT board uses GPIO pins to control and sense two Circuitron
Tortoise (or similar) stall-motor switch machines. Two GPIO pins drive the
stall-motors (one for each stall-motor) and two GPIO pins return the point
state for the stall-motors (one for each stall-motor). The OpenLCB\_PiGPIO
program implements a LCC/OpenLCB node that interfaces this HAT to the
LCC/OpenLCB network, consuming events to activate the stall-motor(s), and
produce events to indicate the point position.

\begin{frame}
    \frametitle{The SMCSenseHAT board}
    
\end{frame}

\subsection{QuadSSSQuadIn}

The QuadSSSQuadIn uses a MCP23008 I2C I/O expander chip to implement four 5V 
Logic inputs and four SSR (Solid State Relay) outputs.  The four inputs are 
connected to the Circuits4Tracks Quad Occupancy Detector's outputs and one of 
the SSR outputs controls the lighting of the Mad Hatter Pie Shop.  The 
OpenLCB\_PiMCP23008 program implements a LCC/OpenLCB node that interfaces this 
HAT to the LCC/OpenLCB network, producing events for block occupancy and 
consuming events to turn the Mad Hatter Pie Shop's light on and off.

\begin{frame}
    \frametitle{The QuadSSSQuadIn board}
    
\end{frame}

\subsection{MCP23017Hat}

The MCP23017Hat uses a MCP23017 I2C I/O expander chip to implement 16 3.3V 
GPIO pins, in two banks of 8.  There are two of these HATs and they are used 
to drive the 22 LEDs in the 6 signals.  There are three octal (8) LED driver 
boards to actually drive the LEDs.  There are two processes running the 
OpenLCM\_PiMCP23017\_signal program, creating two LCC nodes to handle all of 
the signals.

\begin{frame}
   \frametitle{The MCP23017Hat board}
   
\end{frame}

\section{The LCC/OpenLCB network}

On the software side, the Raspberry Pi implements a ``virtual'' LCC/OpenLCB
``network''. The Model Railroad System from Deepwoods Software includes daemon
programs that interface to the HATs and to provide a virtual network for them
to communicate over. This includes a Tcp/Ip ``hub'' daemon, and a set of
OpenLCB ``node'' daemons, along with a program, Dispatcher, that can be used
to to create a CTC (Dispatcher) panel program. Each of the node daemons
interfaces to one HAT, plus a pair of additional node daemons, one to
implement the ``logic'' of the layout and one to implement a CTC (Dispatcher)
panel. All of the nodes communite with each other through the ``hub'' daemon
by passing LCC Event Report messages to each other. 

\begin{frame}
    \frametitle{The LCC/OpenLCB network}
    
\end{frame}

\section{Traction control -- Driving the loco}

The locomotive is powered by DCC using a Lenz command station / booster.  I 
use a Pi Engineering Rail Driver in place of a DCC throtle.

The Rail Driver is a USB HID device and I use the Model Railrail System 
raildriverd daemon to drive it, using the Raildriver Support library and use 
the XPressNet library to talk to the Lenz command station / booster unit.

\begin{frame}
    \frametitle{Traction control}
    
\end{frame}

\end{document}

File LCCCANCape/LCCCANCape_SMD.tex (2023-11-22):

%%%%%%%%%%%%%%%%%%%%%%%%%%%%%%%%%%%%%%%%%%%%%%%%%%%%%%%%%%%%%%%%%%%%%%%%%%%%%
%
%  System        : 
%  Module        : 
%  Object Name   : $RCSfile$
%  Revision      : $Revision$
%  Date          : $Date$
%  Author        : $Author$
%  Created By    : Robert Heller
%  Created       : Wed Nov 22 12:24:39 2023
%  Last Modified : <231122.1521>
%
%  Description 
%
%  Notes
%
%  History
% 
%%%%%%%%%%%%%%%%%%%%%%%%%%%%%%%%%%%%%%%%%%%%%%%%%%%%%%%%%%%%%%%%%%%%%%%%%%%%%
%
%    Copyright (C) 2023  Robert Heller D/B/A Deepwoods Software
%			51 Locke Hill Road
%			Wendell, MA 01379-9728
%
%    This program is free software; you can redistribute it and/or modify
%    it under the terms of the GNU General Public License as published by
%    the Free Software Foundation; either version 2 of the License, or
%    (at your option) any later version.
%
%    This program is distributed in the hope that it will be useful,
%    but WITHOUT ANY WARRANTY; without even the implied warranty of
%    MERCHANTABILITY or FITNESS FOR A PARTICULAR PURPOSE.  See the
%    GNU General Public License for more details.
%
%    You should have received a copy of the GNU General Public License
%    along with this program; if not, write to the Free Software
%    Foundation, Inc., 675 Mass Ave, Cambridge, MA 02139, USA.
%
% 
%
%%%%%%%%%%%%%%%%%%%%%%%%%%%%%%%%%%%%%%%%%%%%%%%%%%%%%%%%%%%%%%%%%%%%%%%%%%%%%

\documentclass[12pt,twoside]{article}
\usepackage{graphicx}
\usepackage{mathptm}
\usepackage{times}
\usepackage{makeidx}
\usepackage{ifpdf}
\ifpdf
\usepackage[pdftex,
            pagebackref=true,
            colorlinks=true,
            linkcolor=blue,
            unicode
           ]{hyperref}
\else
\usepackage[ps2pdf,
            pagebackref=true,
            colorlinks=true,
            linkcolor=blue,
            unicode
           ]{hyperref}
\usepackage{pspicture}
\fi
\usepackage{url}
\pagestyle{headings}
\makeindex
\emergencystretch=50pt
\setcounter{tocdepth}{3}
\setcounter{secnumdepth}{3}
\title{LCCCANCape: LCC CAN Tranceiver Cape (SMD version)}
\author{Robert Heller \\ The Country Robot \\ Wendell, MA, USA}
\date{\today}
\begin{document}
\maketitle

\section{GPIO Pins Used and stacking restrictions.}

This board uses two pins on header P9: 24 and 26 in pin mux mode2, which makes 
pin 24 Can1 RX, and pin 26 Can1 TX.  Only one of these capes can be on any 
Beagle Bone Black.

\section{Circuit Description}

\begin{figure}[hbpt]\begin{centering}%                                         
                               
\caption{Circuit Diagram of the LCCCANCape}                               
\end{centering}\end{figure}                                                    
This circuit contains two sections.  There is the transciever section, which 
includes the transciver itself, the termination block, the two RJ45 jacks, and 
two terminal blocks for injecting and tapping into the power carried in the 
CAT 5 cable.  Power is not used to power the Beagle Bone Black.  The other 
section is the Cape EErom circuit.  The Cape EEProm contains         
information about the cape and the name and version of the overlay that needs  
to be loaded by uBoot.  

\clearpage

\section{Assembly Notes}
\begin{figure}[hbpt]\begin{centering}%
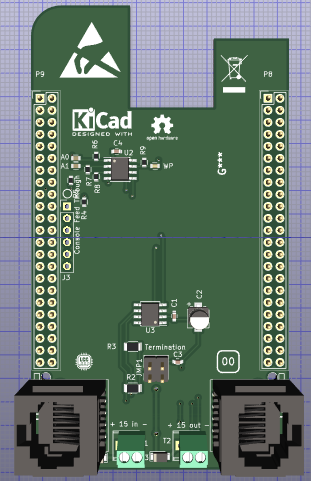
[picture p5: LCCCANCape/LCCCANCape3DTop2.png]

\caption{3D top view of the LCCCANCape}
\end{centering}\end{figure} 

All of the parts are included. The Beagle Bone Header pins are mounted on the
bottom of the board (soldered on the top). You might want to replace the
Beagle Bone Header pins with stacking versions if you plan on stacking
additional capes (but note: the RJ45 connectors will interfere with standard
capes). 

\subsection{Solder bridges}
\label{sec:SolderBridges}

\begin{figure}[hbpt]\begin{centering}%
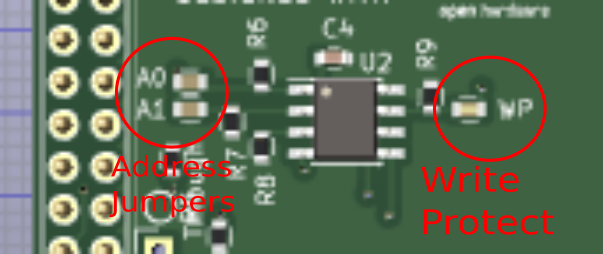
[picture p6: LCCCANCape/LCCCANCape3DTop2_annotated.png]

\caption{Solder bridge locations}
\end{centering}\end{figure}

There are three solder bridges, two for addressing the ID PROM and one to
write protect the PROM.

\subsubsection{ID PROM addressing}

\begin{table}[htp]
\begin{centering}\begin{tabular}{|l|l|p{2in}|}
\hline
A0&A1&ROM/Cape Address\\
\hline
Bridged&Bridged&0x54 (Cape 0)\\
\hline
Unbridged&Bridged&0x55 (Cape 1)\\
\hline
Bridged&Unbridged&0x56 (Cape 2)\\
\hline
Unbridged&Unbridged&0x57 (Cape 3) This is the default.\\
\hline
\hline
\end{tabular}
\caption{ID PROM/Cape addressing.}
\end{centering}\end{table}

There are two solder bridges to addess the ID ROM/Cape. By default the bridges 
are open and thus the ID PROM is at 0x57 (Cape 3).

There is also a PROM Write protect jumper.  This jumper is bridged by default, 
which allows writing to the ID PROM.  Once you have written the ID content to 
the PROM, you can use a small knife to cut the trace shorting the jumper to 
write protect the PROM.

\subsection{ID PROM programming}

The ID PROM  should be programmed for proper operation.  The ID PROM is read 
during booting and will cause and device tree overlay to be loaded.  The device 
tree overlay will set things up to use the CAN interface.  Download the EEPROM 
binary from 
\url{https://www.thecountryrobot.com/wp-content/uploads/2023/11/LCCCANCAPE_CapeROM.zip} \\
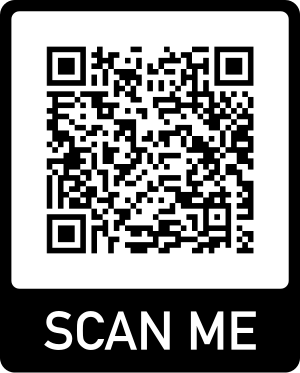
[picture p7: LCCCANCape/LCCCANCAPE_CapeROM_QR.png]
.\\
This zip file contains the file \texttt{CapeROMSpec.bin}, which can be copyied 
to the EEPROM with these commands:

\begin{verbatim}
# Assumes the default address of 0x57.  If you have bridged the address 
# jumpers, change the address to match.
dd if=CapeROMSpec.bin of=/sys/bus/i2c/devices/2-0057/eeprom
dd if=/sys/bus/i2c/devices/2-0057/eeprom of=/tmp/eeprom.bin
diff -q CapeROMSpec.bin /tmp/eeprom.bin
\end{verbatim}

If there are no differences reported by diff, you can go ahead and cut the 
write protect jumper.

\section{Setting up the CAN socket device}

Add this text to \texttt{/etc/network/interfaces}:

\begin{verbatim}
auto can1
iface can1 inet manual
    pre-up /sbin/ip link set can1 type can bitrate 125000
    up /sbin/ifconfig can1 up
    down /sbin/ifconfig can1 down
\end{verbatim}

Then reboot the Beagle bone.

You should then see CAN1:

\begin{verbatim}
% ifconfig can1
can1: flags=193<UP,RUNNING,NOARP>  mtu 16
        unspec 00-00-00-00-00-00-00-00-00-00-00-00-00-00-00-00  txqueuelen 10  
(UNSPEC)
        RX packets 0  bytes 0 (0.0 B)
        RX errors 0  dropped 0  overruns 0  frame 0
        TX packets 0  bytes 0 (0.0 B)
        TX errors 0  dropped 0 overruns 0  carrier 0  collisions 0
        device interrupt 43  
\end{verbatim}

\section{Usage}

Any OpenMRN program (\url{https://github.com/bakerstu/openmrn}) natively built
on your Beagle bone can now use the LCC CAN IF on your Beagle bone. This
includes the hub program under applications -- this program can route LCC
traffic between the LCC CAN network and the Tcp/Ip network using the Beagle
bone's Ethernet. It is also possible to create your own OpenMRN node programs
using the Beagle bone's GPIO lines.

\end{document}

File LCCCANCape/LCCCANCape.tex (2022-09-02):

%%%%%%%%%%%%%%%%%%%%%%%%%%%%%%%%%%%%%%%%%%%%%%%%%%%%%%%%%%%%%%%%%%%%%%%%%%%%%
%
%  System        : 
%  Module        : 
%  Object Name   : $RCSfile$
%  Revision      : $Revision$
%  Date          : $Date$
%  Author        : $Author$
%  Created By    : Robert Heller
%  Created       : Mon Jul 15 17:34:14 2019
%  Last Modified : <220902.0854>
%
%  Description 
%
%  Notes
%
%  History
% 
%%%%%%%%%%%%%%%%%%%%%%%%%%%%%%%%%%%%%%%%%%%%%%%%%%%%%%%%%%%%%%%%%%%%%%%%%%%%%
%
%    Copyright (C) 2019  Robert Heller D/B/A Deepwoods Software
%			51 Locke Hill Road
%			Wendell, MA 01379-9728
%
%    This program is free software; you can redistribute it and/or modify
%    it under the terms of the GNU General Public License as published by
%    the Free Software Foundation; either version 2 of the License, or
%    (at your option) any later version.
%
%    This program is distributed in the hope that it will be useful,
%    but WITHOUT ANY WARRANTY; without even the implied warranty of
%    MERCHANTABILITY or FITNESS FOR A PARTICULAR PURPOSE.  See the
%    GNU General Public License for more details.
%
%    You should have received a copy of the GNU General Public License
%    along with this program; if not, write to the Free Software
%    Foundation, Inc., 675 Mass Ave, Cambridge, MA 02139, USA.
%
% 
%
%%%%%%%%%%%%%%%%%%%%%%%%%%%%%%%%%%%%%%%%%%%%%%%%%%%%%%%%%%%%%%%%%%%%%%%%%%%%%

\chapter{LCCCANCape: LCC CAN Tranceiver Cape}

\section{GPIO Pins Used and stacking restrictions.}

This board uses two pins on header P9: 24 and 26 in pin mux mode2, which makes 
pin 24 Can1 RX, and pin 26 Can1 TX.  Only one of these capes can be on any 
Beagle Bone Black.

\section{Circuit Description}

\begin{figure}[hbpt]\begin{centering}%                                         
                               
\caption{Circuit Diagram of the LCCCANCape}                               
\end{centering}\end{figure}                                                    
This circuit contains two sectins.  There is the transciever section, which 
includes the transciver itself, the termination block, the two RJ45 jacks, and 
two terminal blocks for injecting and tapping into the power carried in the 
CAT 5 cable.  Power is not used to power the Beagle Bone Black.  The other 
section is the Cape EErom circuit.  The Cape EEProm contains         
information about the cape and the name and version of the overlay that needs  
to be loaded by uBoot.  

\clearpage

\section{Parts List}

\begin{table}[htp]
\begin{centering}\begin{tabular}{|l|l|p{1in}|l|}
\hline
Value&Quantity&References&Mouser Part Number \\
\hline
.1 uf&1&C8&581-SR201C104KARTR1 \\
\hline
WP 1 0&1&P2&649-67996-406HLF \\
\hline
5.6K Ohms&2&R3 R4&603-CFR-25JR-525K6 \\
\hline
4.75K Ohms&3&R5 R6 R7&603-CFR-25JR-524K7 \\
\hline
10K Ohms&1&R8&603-CFR-25JR-5210K \\
\hline
CAT24C256W&1&U9&698-CAT24C256WI-GT3 \\
\hline
.1 uf&1&C1&21RZ310-RC \\
\hline
15 uf 63V&1&C2&710-860080773002 \\
\hline
47 nf&1&C3&75-1C10Z5U473M050B \\
\hline
SB240E&2&D1 D2&625-SB240-E3 \\
\hline
RJ45&2&J1 J2&710-615008144221 \\
\hline
Termination&1&JP1&649-67997-404HLF \\
\hline
60 Ohms&2&R1 R2&71-RN60C60R0B/R \\
\hline
+ 15 in -;+ 15 out -&2&T1 T2&651-1725656 \\
\hline
TCAN332DR&1&U1&595-TCAN332DR \\
\hline
SN65HVD233-HT&1&U2&595-SN65HVD233SJD \\
\hline
BeagleBone\_Black\_Header&2&''P8 P9''&200-ESQ12314GD \\
\hline
\end{tabular}
\caption{Parts list for LCCCANCape board.}
\end{centering}\end{table}\footnote{Mouser Project links: 
\url{http://www.mouser.com/ProjectManager/ProjectDetail.aspx?AccessID=ae58a2d985},
\url{http://www.mouser.com/ProjectManager/ProjectDetail.aspx?AccessID=522a1259b2}.}

The only parts that might be substituted are P8 and P9 (the Beagle Bone Black
Headers). The parts listed are for the stacking headers for the Beagle Bone
Black Headers. Feel free to select a non-stacking header for the Beagle Bone
Black Headers.

\section{Circuit Board Layout}

\begin{figure}[hbpt]\begin{centering}%
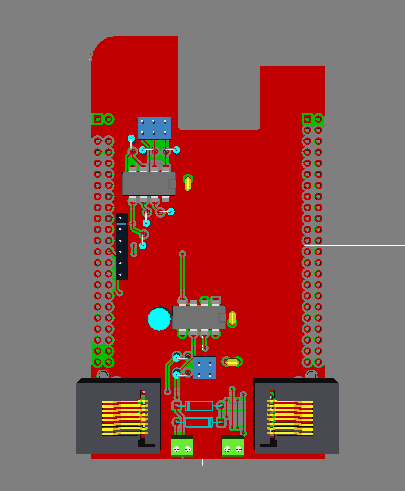
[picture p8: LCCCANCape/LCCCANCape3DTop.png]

\caption{3D rendering of the LCCCANCape board}
\end{centering}\end{figure}
\begin{figure}[hbpt]\begin{centering}%
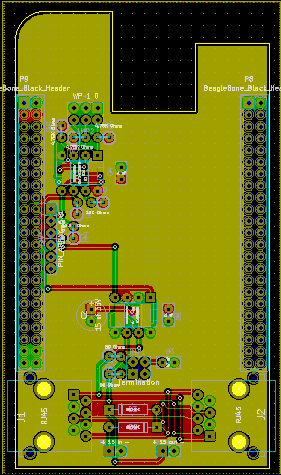
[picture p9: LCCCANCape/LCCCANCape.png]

\caption{Fabrication image of the LCCCANCape board}
\end{centering}\end{figure}
Board assembly is straight forward. You need to be careful orienting the ICs
and the electrolytic capacitor.

\section{Downloadables and Software Support}

Full design information is available on GitHub here:
\url{https://github.com/RobertPHeller/RPi-RRCircuits/tree/master/LCCCANCape}.

This board is supported by both the Model Railroad System 
(\url{https://github.com/RobertPHeller/ModelRRSystem}) and the OpenMRN 
(\url{https://github.com/bakerstu/openmrn}).

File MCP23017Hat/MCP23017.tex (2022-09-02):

%%%%%%%%%%%%%%%%%%%%%%%%%%%%%%%%%%%%%%%%%%%%%%%%%%%%%%%%%%%%%%%%%%%%%%%%%%%%%
%
%  System        : 
%  Module        : 
%  Object Name   : $RCSfile$
%  Revision      : $Revision$
%  Date          : $Date$
%  Author        : $Author$
%  Created By    : Robert Heller
%  Created       : Wed May 31 20:09:46 2017
%  Last Modified : <220902.0856>
%
%  Description 
%
%  Notes
%
%  History
% 
%%%%%%%%%%%%%%%%%%%%%%%%%%%%%%%%%%%%%%%%%%%%%%%%%%%%%%%%%%%%%%%%%%%%%%%%%%%%%
%
%    Copyright (C) 2017  Robert Heller D/B/A Deepwoods Software
%			51 Locke Hill Road
%			Wendell, MA 01379-9728
%
%    This program is free software; you can redistribute it and/or modify
%    it under the terms of the GNU General Public License as published by
%    the Free Software Foundation; either version 2 of the License, or
%    (at your option) any later version.
%
%    This program is distributed in the hope that it will be useful,
%    but WITHOUT ANY WARRANTY; without even the implied warranty of
%    MERCHANTABILITY or FITNESS FOR A PARTICULAR PURPOSE.  See the
%    GNU General Public License for more details.
%
%    You should have received a copy of the GNU General Public License
%    along with this program; if not, write to the Free Software
%    Foundation, Inc., 675 Mass Ave, Cambridge, MA 02139, USA.
%
% 
%
%%%%%%%%%%%%%%%%%%%%%%%%%%%%%%%%%%%%%%%%%%%%%%%%%%%%%%%%%%%%%%%%%%%%%%%%%%%%%

\chapter{MCP23017Hat: 16 bit GPIO expander HAT}

This is a circuit board to for an add-on board for a Raspberry Pi B+ that will 
add 16 3V GPIO pins, using a MCP23017 I2C I/O expander. There is a jumper 
header to set one of eight addresses for the MCP23017 chip.  This allows using 
more than one of this board or any other board featuring a MCP23008 or 
MCP23016 or MCP23017 chip (up to eight total). 

The circuit board uses a 40pin header socket to connect to the 40pin header on 
the  Raspberry Pi B+ and can use a  stack-through  header to allow  additional 
boards to be stacked on top of it.                                             
 
\section{Circuit Description}          

\begin{figure}[hbpt]\begin{centering}%

\caption{Circuit Diagram of the MCP23017}
\end{centering}\end{figure}
This circuit uses a MCP23017 to expand the Raspberry Pis I/O to 16 additional 
I/O pins. The 16 3V logic pins are simply brought out to screw terminals, 
along with the 3V and ground connections (useful for logic reference).

\section{Parts List}

\begin{table}[htp]
\begin{centering}\begin{tabular}{|l|l|p{1in}|l|p{.5in}|}
\hline
Value&Qty&Refs&Mouser Part Number&Adafruit Part Number\\
\hline
.1 uf&1&C1&21RZ310-RC&\\
\hline
RPi GPIO&1&J0&855-M20-6102045&2223\\
\hline
Address Jumper&1&J1&517-929836-02-03&\\
\hline
10K Ohms&1&RR1&652-4605X-1LF-10K&\\
\hline
GP0;GP1&2&T1 T2&651-1725737 or 2x 651-1725685&\\
\hline
MCP23017&1&U1&579-MCP23017-E/SP&\\
\hline
\end{tabular}
\caption{Parts list for MCP23017 boards.}
\end{centering}\end{table}\footnote{Mouser Project link: 
\url{http://www.mouser.com/ProjectManager/ProjectDetail.aspx?AccessID=25df06786a}.}

The only parts that might be substituted are J0 (the RPi GPIO Header), and T1
and T2 (the I/O terminals). The parts listed are for the stacking headers for 
the RPi GPIO Header, and screw terminals for the I/O terminals.  Feel free to 
select a non-stacking header for the RPi GPIO Header and to select either pin 
arrays or spring terminals for the T1 and T2.                   

\section{Circuit Board Layout}

\begin{figure}[hbpt]\begin{centering}%
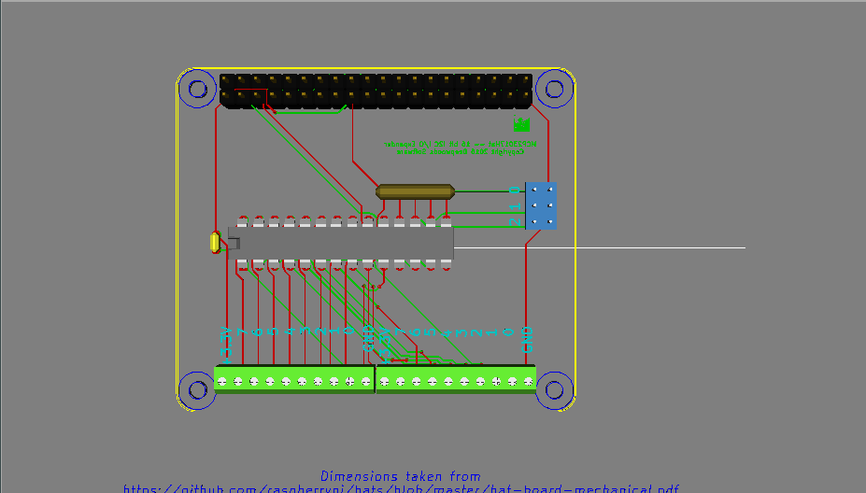
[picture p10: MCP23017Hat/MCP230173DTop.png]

\caption{3D rendering of the MCP23017 board}
\end{centering}\end{figure}
\begin{figure}[hbpt]\begin{centering}%
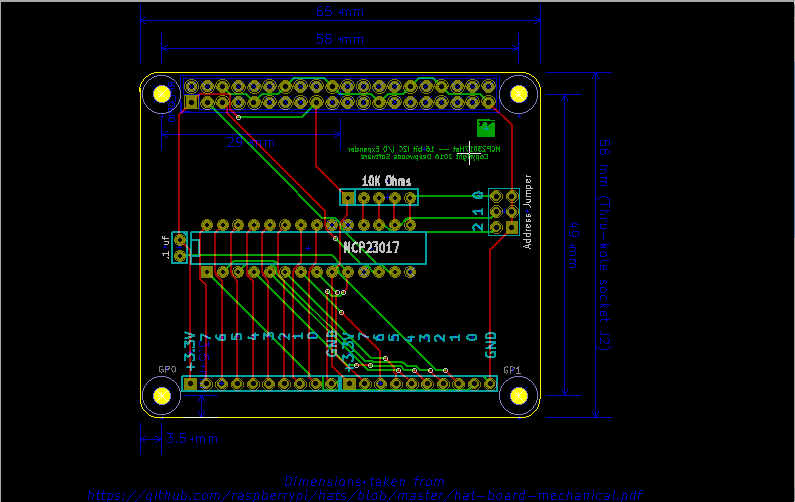
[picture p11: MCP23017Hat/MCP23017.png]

\caption{Fabrication image of the MCP23017 board}
\end{centering}\end{figure}
Board assembly is straight forward. You need to be careful orienting the IC.
Also the SIP resistor array needs to be carefully oriented -- the dot marks
pin 1, which is indicated on the board with a square pad. 

\section{Downloadables and Software Support}

Full design information is available on GitHub here:
\url{https://github.com/RobertPHeller/RPi-RRCircuits/tree/master/MCP23017Hat}.

This board is supported by the Model Railroad System\footnote{Available as a 
free download from Deepwoods Software at this web address: 
\url{http://www.deepsoft.com/home/products/modelrailroadsystem/}.}
\texttt{OpenLCB\_PiMCP23017} and \texttt{OpenLCB\_PiMCP23017\_signal} daemons.
A basic XML file for it is included in its GitHub folder.

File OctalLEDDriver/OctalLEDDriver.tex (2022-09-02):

%%%%%%%%%%%%%%%%%%%%%%%%%%%%%%%%%%%%%%%%%%%%%%%%%%%%%%%%%%%%%%%%%%%%%%%%%%%%%
%
%  System        : 
%  Module        : 
%  Object Name   : $RCSfile$
%  Revision      : $Revision$
%  Date          : $Date$
%  Author        : $Author$
%  Created By    : Robert Heller
%  Created       : Fri Nov 3 11:46:41 2017
%  Last Modified : <220902.0855>
%
%  Description 
%
%  Notes
%
%  History
% 
%%%%%%%%%%%%%%%%%%%%%%%%%%%%%%%%%%%%%%%%%%%%%%%%%%%%%%%%%%%%%%%%%%%%%%%%%%%%%
%
%    Copyright (C) 2017  Robert Heller D/B/A Deepwoods Software
%			51 Locke Hill Road
%			Wendell, MA 01379-9728
%
%    This program is free software; you can redistribute it and/or modify
%    it under the terms of the GNU General Public License as published by
%    the Free Software Foundation; either version 2 of the License, or
%    (at your option) any later version.
%
%    This program is distributed in the hope that it will be useful,
%    but WITHOUT ANY WARRANTY; without even the implied warranty of
%    MERCHANTABILITY or FITNESS FOR A PARTICULAR PURPOSE.  See the
%    GNU General Public License for more details.
%
%    You should have received a copy of the GNU General Public License
%    along with this program; if not, write to the Free Software
%    Foundation, Inc., 675 Mass Ave, Cambridge, MA 02139, USA.
%
% 
%
%%%%%%%%%%%%%%%%%%%%%%%%%%%%%%%%%%%%%%%%%%%%%%%%%%%%%%%%%%%%%%%%%%%%%%%%%%%%%

\chapter{OctalLEDDriver: Octal LED (Common Cathode) driver board.}

This is a standalone board that takes eight 3V GPIO pins (such as from a MCP23017 
or MCP23008 HAT board or just from eight of a Raspberry Pi's GPIO pins and buffers 
them to drive up to eight LEDs from a 5V supply.  It is specificly designed for 
common cathode signals.  It has a ten position screw terminal at one end, for 
GND, GPIO 0 through 7, and +3V (it does not actually use the +3V connection, 
but includes it to match the terminals on a MCP23017 or MCP23008 HAT board and 
thus can support the use of ten conductor cable or pin header connectors, 
etc.).  At the other end it is two sets of +5V and ground terminals (to allow 
for daisy chaining the +5V supply bus), and nine position screw terminal for 
LEDs 0 though 7 and the common cathode (K), which is ground.

\section{Circuit Description}

\begin{figure}[hbpt]\begin{centering}%

\caption{Circuit Diagram of the OctalLEDDriver}
\end{centering}\end{figure}
The circuit is just eight driver circuits, each featuring a NPN and a PNP
transistor, that level shift and buffer the 3V logic to 20 milliamp, 5V LED
drive circuits. The circuits include a current limiting series resistor, so
there is no need to include external resistors on your LEDs. The circuit
assumes 2V LEDs (typical of standard red, green, and yellow LEDs).

\section{Parts List}

\begin{table}[htp]
\begin{centering}\begin{tabular}{|l|l|p{1in}|l|}
\hline
Value&Quantity&References&Mouser Part Number\\
\hline
MPQ6002&4&Q1 Q2 Q3 Q4&610-MPQ6002\\
\hline
15K Ohms&8&R1 R5 R9 R13 R17 R21 R25 R29&603-CFR-25JR-5215K\\
\hline
10K Ohms&8&R2 R6 R10 R14 R18 R22 R26 R30&603-CFR-25JR-5210K\\
\hline
2K Ohms&8&R3 R7 R11 R15 R19 R23 R27 R31&603-CFR-25JR-522K\\
\hline
150 Ohms&8&R4 R8 R12 R16 R20 R24 R28 R32&588-OK1515E-R52\\
\hline
GPIO (3.3V)&1&T1&651-1725737 or 2x 651-1725685 \\
\hline
LED Power (5V)&2&T2 T4&651-1725656\\
\hline
LEDs (Common Cathode)&1&T3&651-1725724\\
\hline
\end{tabular}
\caption{Parts list for OctalLEDDriver boards.}
\end{centering}\end{table}\footnote{Mouser Project link: 
\url{http://www.mouser.com/ProjectManager/ProjectDetail.aspx?AccessID=f337ca3247}.}

The only parts that might be substituted are the screw terminal boards. Feel 
free to select either pin arrays or spring terminals for the terminals.

\section{Circuit Board Layout}

\begin{figure}[hbpt]\begin{centering}%
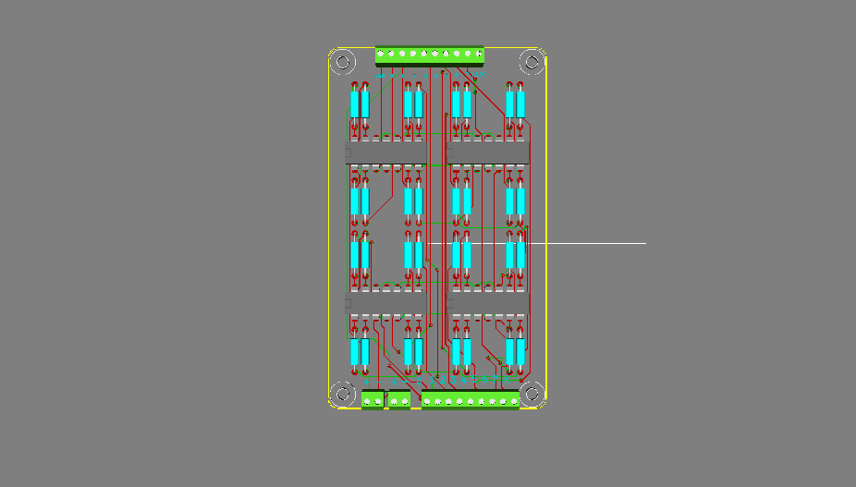
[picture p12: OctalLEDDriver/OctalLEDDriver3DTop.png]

\caption{3D rendering of the OctalLEDDriver board}
\end{centering}\end{figure}
\begin{figure}[hbpt]\begin{centering}%
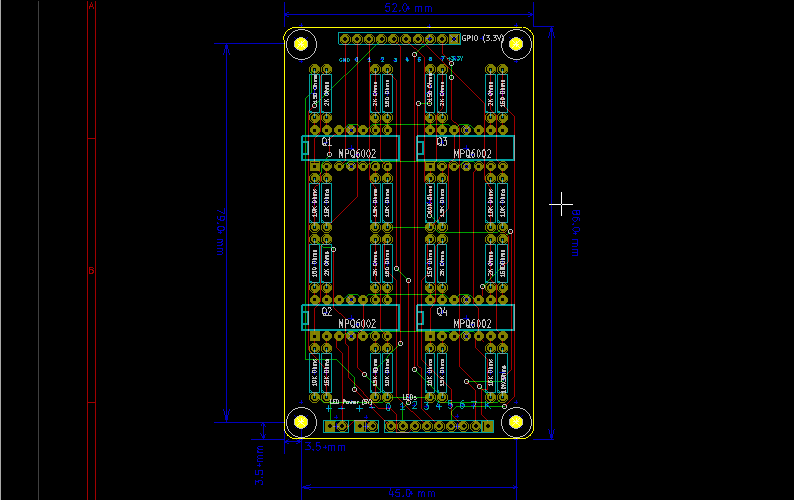
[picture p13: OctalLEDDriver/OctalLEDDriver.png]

\caption{Fabrication image of the OctalLEDDriver board}
\end{centering}\end{figure}
Board assembly is straight forward. You need to be careful orienting the quad 
transistors. 

\section{Downloadables}

Full design information is available on GitHub here:
\url{https://github.com/RobertPHeller/RPi-RRCircuits/tree/master/OctalLEDDriver}.

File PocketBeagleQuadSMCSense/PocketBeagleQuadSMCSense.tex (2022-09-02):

%%%%%%%%%%%%%%%%%%%%%%%%%%%%%%%%%%%%%%%%%%%%%%%%%%%%%%%%%%%%%%%%%%%%%%%%%%%%%
%
%  System        : 
%  Module        : 
%  Object Name   : $RCSfile$
%  Revision      : $Revision$
%  Date          : $Date$
%  Author        : $Author$
%  Created By    : Robert Heller
%  Created       : Mon Nov 25 10:01:47 2019
%  Last Modified : <220902.0856>
%
%  Description 
%
%  Notes
%
%  History
% 
%%%%%%%%%%%%%%%%%%%%%%%%%%%%%%%%%%%%%%%%%%%%%%%%%%%%%%%%%%%%%%%%%%%%%%%%%%%%%
%
%    Copyright (C) 2019  Robert Heller D/B/A Deepwoods Software
%			51 Locke Hill Road
%			Wendell, MA 01379-9728
%
%    This program is free software; you can redistribute it and/or modify
%    it under the terms of the GNU General Public License as published by
%    the Free Software Foundation; either version 2 of the License, or
%    (at your option) any later version.
%
%    This program is distributed in the hope that it will be useful,
%    but WITHOUT ANY WARRANTY; without even the implied warranty of
%    MERCHANTABILITY or FITNESS FOR A PARTICULAR PURPOSE.  See the
%    GNU General Public License for more details.
%
%    You should have received a copy of the GNU General Public License
%    along with this program; if not, write to the Free Software
%    Foundation, Inc., 675 Mass Ave, Cambridge, MA 02139, USA.
%
% 
%
%%%%%%%%%%%%%%%%%%%%%%%%%%%%%%%%%%%%%%%%%%%%%%%%%%%%%%%%%%%%%%%%%%%%%%%%%%%%%

\chapter{PocketBeagleQuadSMCSense: Quad Motor Control and Sense base board for the Pocket Beagle}

This is a circuit board that supports a Pocket Beagle controlling four 
stall-motor turnout motors for a model railroad. It also has sense logic to 
return the state of the turnouts, using one pole of the DPDT contacts in the 
stall-motor (typical of Tortoise stall-motors). This circuit board provides 
connections to a LCC CAN network via RJ45 connectors, the ability to inject 
and extract 12V power from the LCC CAN network, and a 5V power supply from the 
LCC CAN network 12V power bus.

\section{GPIO Pins Used.}

This board uses eight GPIO pins:

\begin{description}
\item[GPIO20: P1-20] Motor Select 1: select the position of stall motor 
1. 
\item[GPIO23: P2-3] Motor Select 2: select the position of stall motor 
2. 
\item[GPIO45: P2-33] Point Sense 1: return the state of the points for 
stall motor 1. 
\item[GPIO46: P2-22] Point Sense 2: return the state of the points for 
stall motor 2. 
\item[GPIO26: P1-34] Motor Select 3: select the position of stall motor 
3. 
\item[GPIO27: P2-19] Motor Select 4: select the position of stall motor 
4. 
\item[GPIO47: P2-18] Point Sense 3: return the state of the points for 
stall motor 3. 
\item[GPIO44: P2-24] Point Sense 4: return the state of the points for 
stall motor 4. 
\end{description}

Each of the motor drive circuits is through a TC4428, which can drive up to
1.5A, which is way more needed to drive typical stall motor. It is enough to
drive a pair of stall motors, wired in parallel as would be the case for a
cross over. 

\section{Circuit Description}

\begin{figure}[hbpt]\begin{centering}%

\caption{Circuit Diagram of the PocketBeagleQuadSMCSense, page 1 (Pocket 
Beagle and CAN Transceiver)}
\end{centering}\end{figure}
\begin{figure}[hbpt]\begin{centering}%

\caption{Circuit Diagram of the PocketBeagleQuadSMCSense, page 2 (Power Supply)}
\end{centering}\end{figure}
\begin{figure}[hbpt]\begin{centering}%

\caption{Circuit Diagram of the PocketBeagleQuadSMCSense, page 3 (Driver and Sense)}
\end{centering}\end{figure}
This circuit contains two sections.  There is an output section that contains 
four TC4428 chips.  Each chip has a non-inverting and an inverting driver. The 
inputs of both drivers are connected to one of the motor GPIO pins.  The 
output are wired to the terminal block for a one of the motors. For any given 
logic state of the motor control output, one of the drivers is ``on'' and the 
other is ``off'', thus one motor terminal is ground and one is raised to the 
12V supply.  This means alternative states of the logic line will drive the 
stall motor in alternative directions.

The other section is a quartet of flip-flop debounce circuits, one for each
of two SPDT switch contacts that report the position of the turnout points.
The output of these flip-flops goes to a quartet of GPIO input pins.

Also on the board is a CAN Transceiver and power supply for the Pocket Beagle.

\section{Parts List}

\begin{table}[htp]
\begin{centering}\begin{tabular}{|l|l|p{1in}|l|p{.5in}|}
\hline
Value&Quantity&References&Mouser Part Number \\
\hline
.1 uf&2&C1 C2&581-SR201C104KARTR1 \\
\hline
10 uf 35V&1&C3&667-ECA-1HM100I \\
\hline
RPi\_GPIO&1&J0&855-M20-6102045 \\
\hline
10K Ohms&1&RR1&652-4609X-1LF-10K \\
\hline
Motor 1;Motor 2;Motor 3;Motor 4&4&T1 T2 T3 T4&651-1725685 \\
\hline
+ 12V -&1&T5&651-1725656 \\
\hline
TC4428&4&U1 U2 U3 U4&579-TC4428VPA \\
\hline
74HCT00&2&U5 U6&595-SN74AHC00N \\
\hline
.1 uf&1&C1&21RZ310-RC\\
\hline
15 uf 63V&1&C2&710-860080773002\\
\hline
47 nf&1&C3&75-1C10Z5U473M050B\\
\hline
SB240E&2&D1 D2&625-SB240-E3\\
\hline
RJ45&2&J1 J2&710-615008144221\\
\hline
Termination&1&JP1&649-67997-404HLF\\
\hline
60 Ohms&2&R1 R2&71-RN60C60R0B/R\\
\hline
+ 15 in -;+ 15 out -&2&T1 T2&651-1725656\\
\hline
TCAN332DR&1&U1&595-TCAN332DR\\
\hline
SN65HVD233-HT&1&U2&595-SN65HVD233SJD\\
\hline
220 uf 25V&1&C4&140-REA221M1EBK0811P\\
\hline
22 uf 100V&1&C5&140-REA220M2ABK0811P\\
\hline
SB160-E3/54&1&D3&625-SB160-E3\\
\hline
330 uh&1&L1&PE-52627NL\\
\hline
LM2574N-5.0&1&U3&926-LM2574N-5.0/NOPB\\
\hline
\end{tabular}
\caption{Parts list for PocketBeagleQuadSMCSense board.}
\end{centering}\end{table}\footnote{Mouser Project link: 
\url{http://www.mouser.com/ProjectManager/ProjectDetail.aspx?AccessID=330542c522},
\url{http://www.mouser.com/ProjectManager/ProjectDetail.aspx?AccessID=82b1e6b259}, and
\url{http://www.mouser.com/ProjectManager/ProjectDetail.aspx?AccessID=ae58a2d985}.}

The only parts that might be substituted are T1 though T4 (the Motor
terminals) and T5 (the 12 to 16 Volts terminals). The parts listed are for
screw terminals for the Motor terminals and the motor power terminals. Feel
free to select either pin arrays or spring terminals for the T1, T2, T3, T4
and T5.  You only need one CAN transciever.  One of the parts is a through 
hole version (which is much more expensive) and the other is SMD.  The SMD 
part can be hand soldered.  I used male headers on the Pocket Beagle (on the 
bottom) and female headers on the base board.

\section{Circuit Board Layout}

\begin{figure}[hbpt]\begin{centering}%
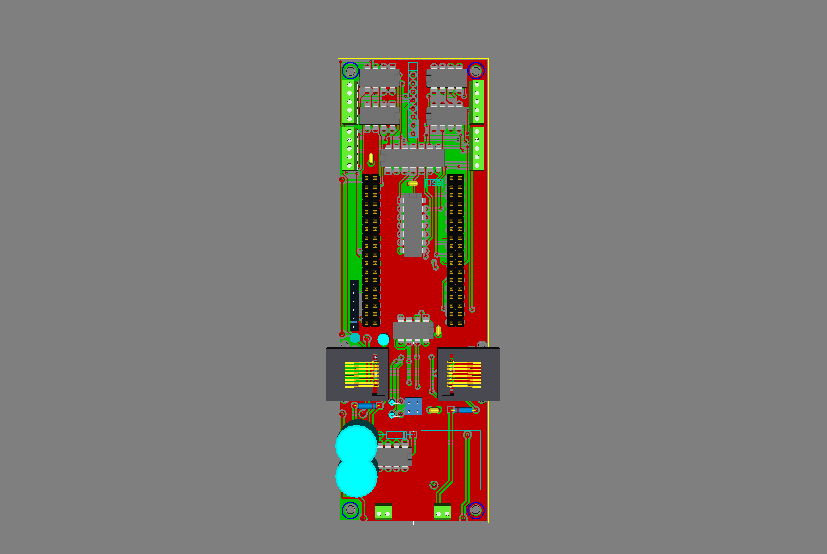
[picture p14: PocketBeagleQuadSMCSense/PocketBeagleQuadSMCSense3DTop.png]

\caption{3D rendering of the PocketBeagleQuadSMCSense board}
\end{centering}\end{figure}
\begin{figure}[hbpt]\begin{centering}%
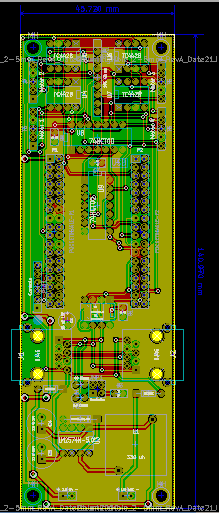
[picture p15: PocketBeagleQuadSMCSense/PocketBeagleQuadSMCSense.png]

\caption{Fabrication image of the PocketBeagleQuadSMCSense board}
\end{centering}\end{figure}
Board assembly is straight forward. You need to be careful orienting the ICs
and the electrolytic capacitor.

Bare circuit boards can be ordered from PCBWay here: 
\url{https://www.pcbway.com/project/shareproject/Pocket\_Beagle\_Quad\_StallMotor\_w\_Sense\_base\_board\_\_includes\_LCC\_CAN\_and\_power\_supply.html}.

\section{Downloadables and Software Support}

Full design information is available on GitHub here:
\url{https://github.com/RobertPHeller/RPi-RRCircuits/tree/master/PocketBeagleQuadSMCSense}.

An OpenMRN program that supports this board is available here:
\url{https://github.com/RobertPHeller/RPi-RRCircuits/tree/master/QuadSMCSenseOpenMRN}.

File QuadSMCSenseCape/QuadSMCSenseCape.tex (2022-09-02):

%%%%%%%%%%%%%%%%%%%%%%%%%%%%%%%%%%%%%%%%%%%%%%%%%%%%%%%%%%%%%%%%%%%%%%%%%%%%%
%
%  System        : 
%  Module        : 
%  Object Name   : $RCSfile$
%  Revision      : $Revision$
%  Date          : $Date$
%  Author        : $Author$
%  Created By    : Robert Heller
%  Created       : Mon Jul 15 17:33:37 2019
%  Last Modified : <220902.0857>
%
%  Description 
%
%  Notes
%
%  History
% 
%%%%%%%%%%%%%%%%%%%%%%%%%%%%%%%%%%%%%%%%%%%%%%%%%%%%%%%%%%%%%%%%%%%%%%%%%%%%%
%
%    Copyright (C) 2019  Robert Heller D/B/A Deepwoods Software
%			51 Locke Hill Road
%			Wendell, MA 01379-9728
%
%    This program is free software; you can redistribute it and/or modify
%    it under the terms of the GNU General Public License as published by
%    the Free Software Foundation; either version 2 of the License, or
%    (at your option) any later version.
%
%    This program is distributed in the hope that it will be useful,
%    but WITHOUT ANY WARRANTY; without even the implied warranty of
%    MERCHANTABILITY or FITNESS FOR A PARTICULAR PURPOSE.  See the
%    GNU General Public License for more details.
%
%    You should have received a copy of the GNU General Public License
%    along with this program; if not, write to the Free Software
%    Foundation, Inc., 675 Mass Ave, Cambridge, MA 02139, USA.
%
% 
%
%%%%%%%%%%%%%%%%%%%%%%%%%%%%%%%%%%%%%%%%%%%%%%%%%%%%%%%%%%%%%%%%%%%%%%%%%%%%%

\chapter{QuadSMCSenseCape: Quad Motor Control and Sense Cape}

This is a circuit board to for an add-on board for a Beagle Bone Black that
will control four stall-motor turnout motors for a model railroad. It also has
sense logic to return the state of the turnouts, using one pole of the DPDT
contacts in the stall-motor (typical of Tortoise stall-motors).

The circuit board uses a pair of 46 pin header sockets to connect to the 46pin
headers on the Beagle Bone Black and can use a stack-through header to allow
additional boards to be stacked on top of it.

\section{GPIO Pins Used and stacking restrictions.}

This board uses eight GPIO pins:

\begin{description}
\item[GPIO 0.07, P9-42] Motor Select 1: select the position of stall motor 
1. 
\item[GPIO 1.6, P8-3] Motor Select 2: select the position of stall motor 
2. 
\item[GPIO 1.28, P9-12] Point Sense 1: return the state of the points for 
stall motor 1. 
\item[GPIO 1.7, P8-4] Point Sense 2: return the state of the points for 
stall motor 2. 
\item[GPIO 1.16, P9-15] Motor Select 3: select the position of stall motor 
3. 
\item[GPIO 1.17, P9-23] Motor Select 4: select the position of stall motor 
4. 
\item[GPIO 3.21, P9-25] Point Sense 3: return the state of the points for 
stall motor 3. 
\item[GPIO 3.19, P9-27] Point Sense 4: return the state of the points for 
stall motor 4. 
\end{description}

Each of the motor drive circuits is through a TC4428, which can drive up to
1.5A, which is way more needed to drive typical stall motor. It is enough to
drive a pair of stall motors, wired in parallel as would be the case for a
cross over. 

Because this board is hardwired to use eight specific GPIO pins it is not 
possible to use two or more of these boards on given Raspberry Pi.

\section{Circuit Description}

\begin{figure}[hbpt]\begin{centering}%

\caption{Circuit Diagram of the QuadSMCSenseCape, Sheet 1}
\end{centering}\end{figure}
\begin{figure}[hbpt]\begin{centering}%

\caption{Circuit Diagram of the QuadSMCSenseCape, Sheet 2}
\end{centering}\end{figure}
This circuit contains three sections.  There is an output section that contains 
four TC4428 chips.  Each chip has a non-inverting and an inverting driver. The 
inputs of both drivers are connected to one of the motor GPIO pins.  The 
output are wired to the terminal block for a one of the motors. For any given 
logic state of the motor control output, one of the drivers is ``on'' and the 
other is ``off'', thus one motor terminal is ground and one is raised to the 
12V supply.  This means alternative states of the logic line will drive the 
stall motor in alternative directions.

The second section is a quartet of flip-flop debounce circuits, one for each
of two SPDT switch contacts that report the position of the turnout points.
The output of these flip-flops goes to a quartet of GPIO input pins.

The third section is the Cape EEProm circuit.  The Cape EEProm contains 
information about the cape and the name and version of the overlay that needs 
to be loaded by uBoot.

\section{Parts List}

\begin{table}[htp]
\begin{centering}\begin{tabular}{|l|l|p{1in}|l|}
\hline
Value&Quantity&References&Mouser Part Number \\
\hline
10 uf 35V&1&''C1''&667-ECA-1HM100I \\
\hline
.1 uf&3&''C2 C3 C8''&581-SR201C104KARTR1 \\
\hline
WP 1 0&1&''P2''&649-67996-406HLF \\
\hline
BeagleBone\_Black\_Header&2&''P8 P9''&200-ESQ12314GD \\
\hline
4.75K Ohms&3&''R5 R6 R7''&603-CFR-25JR-524K7 \\
\hline 
5.6K Ohms&2&''R3 R4''&603-CFR-25JR-525K6 \\
\hline
10K Ohms&1&''R8''&603-CFR-25JR-5210K \\
\hline
10K Ohms&1&''RR1''&652-4609X-1LF-10K \\
\hline
Motor 1;Motor 2;Motor 3;Motor 4&4&T1 T2 T3 T4&651-1725685 \\
\hline
+ 12V -&1&''T5''&651-1725656 \\
\hline
TC4428&4&''U1 U2 U3 U4''&579-TC4428VPA \\
\hline
74HCT00&2&''U5 U6''&595-SN74AHC00N \\
\hline
CAT24C256W&1&''U9''&698-CAT24C256WI-GT3 \\
\hline
\end{tabular}
\caption{Parts list for QuadSMCSenseCape board.}
\end{centering}\end{table}\footnote{Mouser Project links: 
\url{http://www.mouser.com/ProjectManager/ProjectDetail.aspx?AccessID=330542c522},
\url{http://www.mouser.com/ProjectManager/ProjectDetail.aspx?AccessID=522a1259b2}.}

The only parts that might be substituted are P8 and P9 (the Beagle Bone Black
Headers), and T1 though T4 (the Motor terminals) and T5 (the 12 to 16 Volts
terminals). The parts listed are for the stacking headers for the Beagle Bone
Black Headers, and screw terminals for the Motor terminals and the motor power
terminals. Feel free to select a non-stacking header for the Beagle Bone Black
Headers and to select either pin arrays or spring terminals for the T1, T2,
T3, T4 and T5.

\section{Circuit Board Layout}

\begin{figure}[hbpt]\begin{centering}%
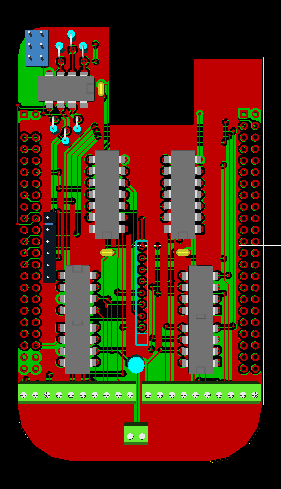
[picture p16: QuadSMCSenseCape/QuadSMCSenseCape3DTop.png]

\caption{3D rendering of the QuadSMCSenseCape board}
\end{centering}\end{figure}
\begin{figure}[hbpt]\begin{centering}%
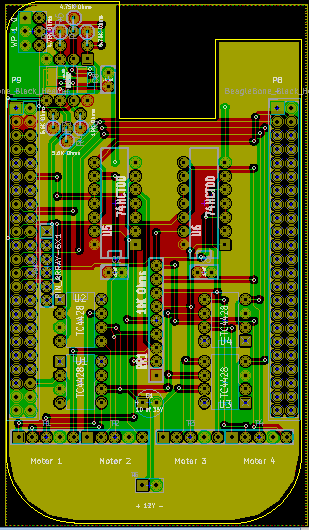
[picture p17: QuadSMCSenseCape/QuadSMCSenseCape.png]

\caption{Fabrication image of the QuadSMCSenseCape board}
\end{centering}\end{figure}
Board assembly is straight forward. You need to be careful orienting the ICs
and the electrolytic capacitor.

Bare circuit boards can be ordered from PCBWay here: 
\url{https://www.pcbway.com/project/shareproject/Quad_Stall_motor_with_point_sense_cape.html}.

\section{Downloadables and Software Support}

Full design information is available on GitHub here:
\url{https://github.com/RobertPHeller/RPi-RRCircuits/tree/master/QuadSMCSenseCape}.

An OpenMRN program that supports this board is available here:
\url{https://github.com/RobertPHeller/RPi-RRCircuits/tree/master/QuadSMCSenseOpenMRN}.

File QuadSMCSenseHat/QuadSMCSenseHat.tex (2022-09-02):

%%%%%%%%%%%%%%%%%%%%%%%%%%%%%%%%%%%%%%%%%%%%%%%%%%%%%%%%%%%%%%%%%%%%%%%%%%%%%
%
%  System        : 
%  Module        : 
%  Object Name   : $RCSfile$
%  Revision      : $Revision$
%  Date          : $Date$
%  Author        : $Author$
%  Created By    : Robert Heller
%  Created       : Mon Jul 15 17:33:37 2019
%  Last Modified : <220902.0858>
%
%  Description 
%
%  Notes
%
%  History
% 
%%%%%%%%%%%%%%%%%%%%%%%%%%%%%%%%%%%%%%%%%%%%%%%%%%%%%%%%%%%%%%%%%%%%%%%%%%%%%
%
%    Copyright (C) 2019  Robert Heller D/B/A Deepwoods Software
%			51 Locke Hill Road
%			Wendell, MA 01379-9728
%
%    This program is free software; you can redistribute it and/or modify
%    it under the terms of the GNU General Public License as published by
%    the Free Software Foundation; either version 2 of the License, or
%    (at your option) any later version.
%
%    This program is distributed in the hope that it will be useful,
%    but WITHOUT ANY WARRANTY; without even the implied warranty of
%    MERCHANTABILITY or FITNESS FOR A PARTICULAR PURPOSE.  See the
%    GNU General Public License for more details.
%
%    You should have received a copy of the GNU General Public License
%    along with this program; if not, write to the Free Software
%    Foundation, Inc., 675 Mass Ave, Cambridge, MA 02139, USA.
%
% 
%
%%%%%%%%%%%%%%%%%%%%%%%%%%%%%%%%%%%%%%%%%%%%%%%%%%%%%%%%%%%%%%%%%%%%%%%%%%%%%

\chapter{QuadSMCSenseHat: Quad Motor Control and Sense HAT}

This is a circuit board to for an add-on board for a Raspberry Pi B+ that will
control four stall-motor turnout motors for a model railroad. It also has
sense logic to return the state of the turnouts, using one pole of the DPDT
contacts in the stall-motor (typical of Tortoise stall-motors).

The circuit board uses a 40pin header socket to connect to the 40pin header on
the  Raspberry Pi B+ and can use a  stack-through  header to allow  additional
boards to be stacked on top of it.

\section{GPIO Pins Used and stacking restrictions.}

This board uses eight GPIO pins:

\begin{description}
\item[WiringPi 0, BCM 17] Motor Select 1: select the position of stall motor 
1. 
\item[WiringPi 1, BCM 18] Motor Select 2: select the position of stall motor 
2. 
\item[WiringPi 2, BCM 27] Point Sense 1: return the state of the points for 
stall motor 1. 
\item[WiringPi 3, BCM 22] Point Sense 2: return the state of the points for 
stall motor 2. 
\item[WiringPi 4, BCM 23] Motor Select 3: select the position of stall motor 
3. 
\item[WiringPi 5, BCM 24] Motor Select 4: select the position of stall motor 
4. 
\item[WiringPi 6, BCM 25] Point Sense 3: return the state of the points for 
stall motor 3. 
\item[WiringPi 7, BCM 4] Point Sense 4: return the state of the points for 
stall motor 4. 
\end{description}

Each of the motor drive circuits is through a TC4428, which can drive up to
1.5A, which is way more needed to drive typical stall motor. It is enough to
drive a pair of stall motors, wired in parallel as would be the case for a
cross over. 

Because this board is hardwired to use eight specific GPIO pins it is not 
possible to use two or more of these boards on given Raspberry Pi.

\section{Circuit Description}

\begin{figure}[hbpt]\begin{centering}%

\caption{Circuit Diagram of the QuadSMCSenseHat}
\end{centering}\end{figure}
This circuit contains two sections.  There is an output section that contains 
four TC4428 chips.  Each chip has a non-inverting and an inverting driver. The 
inputs of both drivers are connected to one of the motor GPIO pins.  The 
output are wired to the terminal block for a one of the motors. For any given 
logic state of the motor control output, one of the drivers is ``on'' and the 
other is ``off'', thus one motor terminal is ground and one is raised to the 
12V supply.  This means alternative states of the logic line will drive the 
stall motor in alternative directions.

The other section is a quartet of flip-flop debounce circuits, one for each
of two SPDT switch contacts that report the position of the turnout points.
The output of these flip-flops goes to a quartet of GPIO input pins.

\section{Parts List}

\begin{table}[htp]
\begin{centering}\begin{tabular}{|l|l|p{1in}|l|p{.5in}|}
\hline
Value&Quantity&References&Mouser Part Number&Adafruit Part Number \\
\hline
.1 uf&2&C1 C2&581-SR201C104KARTR1& \\
\hline
10 uf 35V&1&C3&667-ECA-1HM100I& \\
\hline
RPi\_GPIO&1&J0&855-M20-6102045& \\
\hline
10K Ohms&1&RR1&652-4609X-1LF-10K& \\
\hline
Motor 1;Motor 2;Motor 3;Motor 4&4&T1 T2 T3 T4&651-1725685& \\
\hline
+ 12V -&1&T5&651-1725656& \\
\hline
TC4428&4&U1 U2 U3 U4&579-TC4428VPA& \\
\hline
74HCT00&2&U5 U6&595-SN74AHC00N& \\
\hline
\end{tabular}
\caption{Parts list for QuadSMCSenseHat board.}
\end{centering}\end{table}\footnote{Mouser Project link: 
\url{http://www.mouser.com/ProjectManager/ProjectDetail.aspx?AccessID=330542c522}.}

The only parts that might be substituted are J0 (the RPi GPIO Header), and T1 
though T4 (the Motor terminals) and T5 (the 12 to 16 Volts terminals).  The parts 
listed are for the stacking headers for the RPi GPIO Header, and screw 
terminals for the Motor terminals and the motor power terminals.  Feel free to 
select a non-stacking header for the RPi GPIO Header and to select either pin 
arrays or spring terminals for the T1, T2, T3, T4 and T5.

\section{Circuit Board Layout}

\begin{figure}[hbpt]\begin{centering}%
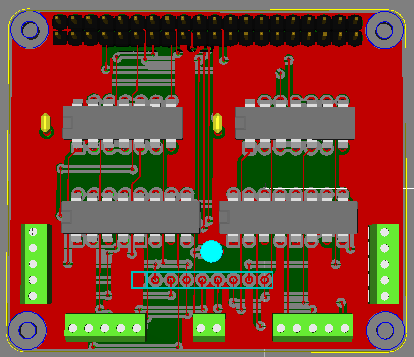
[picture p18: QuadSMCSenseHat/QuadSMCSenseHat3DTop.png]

\caption{3D rendering of the QuadSMCSenseHAT board}
\end{centering}\end{figure}
\begin{figure}[hbpt]\begin{centering}%
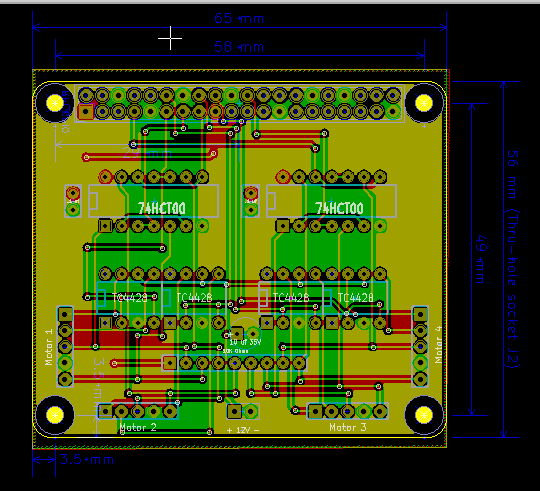
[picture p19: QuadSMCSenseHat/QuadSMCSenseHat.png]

\caption{Fabrication image of the QuadSMCSenseHAT board}
\end{centering}\end{figure}
Board assembly is straight forward. You need to be careful orienting the ICs
and the electrolytic capacitor.

Bare circuit boards can be ordered from PCBWay here: 
\url{https://www.pcbway.com/project/shareproject/Quad_Stall_Motor_Controller_w__point_Sense__hat_.html}.

\section{Downloadables and Software Support}

Full design information is available on GitHub here:
\url{https://github.com/RobertPHeller/RPi-RRCircuits/tree/master/QuadSMCSenseHat}.

An OpenMRN program that supports this board is available here:
\url{https://github.com/RobertPHeller/RPi-RRCircuits/tree/master/QuadSMCSenseOpenMRN}.
This board is also supported by the Model Railroad System\footnote{Available
as a free download from Deepwoods Software at this web address:
\url{http://www.deepsoft.com/home/products/modelrailroadsystem/}.}
\texttt{OpenLCB\_PiGPIO} daemon. A basic XML file for it is included in its
GitHub folder.

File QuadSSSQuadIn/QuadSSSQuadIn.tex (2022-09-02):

%%%%%%%%%%%%%%%%%%%%%%%%%%%%%%%%%%%%%%%%%%%%%%%%%%%%%%%%%%%%%%%%%%%%%%%%%%%%%
%
%  System        : 
%  Module        : 
%  Object Name   : $RCSfile$
%  Revision      : $Revision$
%  Date          : $Date$
%  Author        : $Author$
%  Created By    : Robert Heller
%  Created       : Wed May 31 20:07:09 2017
%  Last Modified : <220902.0852>
%
%  Description 
%
%  Notes
%
%  History
% 
%%%%%%%%%%%%%%%%%%%%%%%%%%%%%%%%%%%%%%%%%%%%%%%%%%%%%%%%%%%%%%%%%%%%%%%%%%%%%
%
%    Copyright (C) 2017  Robert Heller D/B/A Deepwoods Software
%			51 Locke Hill Road
%			Wendell, MA 01379-9728
%
%    This program is free software; you can redistribute it and/or modify
%    it under the terms of the GNU General Public License as published by
%    the Free Software Foundation; either version 2 of the License, or
%    (at your option) any later version.
%
%    This program is distributed in the hope that it will be useful,
%    but WITHOUT ANY WARRANTY; without even the implied warranty of
%    MERCHANTABILITY or FITNESS FOR A PARTICULAR PURPOSE.  See the
%    GNU General Public License for more details.
%
%    You should have received a copy of the GNU General Public License
%    along with this program; if not, write to the Free Software
%    Foundation, Inc., 675 Mass Ave, Cambridge, MA 02139, USA.
%
% 
%
%%%%%%%%%%%%%%%%%%%%%%%%%%%%%%%%%%%%%%%%%%%%%%%%%%%%%%%%%%%%%%%%%%%%%%%%%%%%%

\chapter{QuadSSSQuadIn: Quad SSR and Quad 5V Input HAT}

This is a circuit board to for an add-on board for a Raspberry Pi B+ that will
add four 5V logic inputs and four Solid State Relays, using a MCP23008 I2C I/O 
expander.  There is a jumper header to set one of eight addresses for the 
MCP23008 chip.  This allows using more than one of this board or any other 
board featuring a MCP23008 or MCP23016 or MCP23017 chip (up to eight total).

The circuit board uses a 40pin header socket to connect to the 40pin header on
the  Raspberry Pi B+ and can use a  stack-through  header to allow  additional
boards to be stacked on top of it.

\section{Circuit Description}                                                  
 
\begin{figure}[hbpt]\begin{centering}%

\caption{Circuit Diagram of the QuadSSSQuadIn}
\end{centering}\end{figure}
This circuit uses a MCP23008 to expand the Raspberry Pis I/O to 8 additional 
I/O pins.  Four of these pins (0-3) are used to drive a pair of dual 
opto-isolated SSR chip and the remaining 4 (4-7) are driven by a input buffer 
chip that can be driven with 5V logic.  The SSRs can be used to switch 
arbitrary trackside devices, since the output side of the SSRs are rated upto 
+/- 400 volts at up to 0.1 Amp (100ma).  The 5V logic inputs are compatible 
with many sensor boards available (particularly occupancy detector circuits).

\section{Parts List}

\begin{table}[htp]
\begin{centering}\begin{tabular}{|l|l|p{1in}|l|p{.5in}|}
\hline
Value&Qty&Refs&Mouser Part Number&Adafruit Part Number\\
\hline
.1 uf&3&C1 C2 C3&21RZ310-RC&\\
\hline
ASSR-4128&2&IC1 IC2&630-ASSR-4128-002E&\\
\hline
RPi GPIO&1&J0&855-M20-6102045&2223\\
\hline
CONN 3X2&1&J1&517-929836-02-03&\\
\hline
330 Ohms&1&RP1&652-4608X-AP2-331LF&\\
\hline
10K Ohms&2&RR1 RR2&652-4605X-1LF-10K&\\
\hline
CONN 8&1&T1&651-1725711&\\
\hline
CONN 6&1&T2&651-1725698&\\
\hline
MCP23008&1&U1&579-MCP23008-E/P&\\
\hline
74LV125AN&1&U2&595-SN74LV125AN&\\
\hline
\end{tabular}
\caption{Parts list for QuadSSSQuadIn boards.}
\end{centering}\end{table}\footnote{Mouser Project link: 
\url{http://www.mouser.com/ProjectManager/ProjectDetail.aspx?AccessID=97fe7b85dc}.}

The only parts that might be substituted are J0 (the RPi GPIO Header), and T1
and T2 (the I/O terminals). The parts listed are for the stacking headers for 
the RPi GPIO Header, and screw terminals for the I/O terminals.  Feel free to 
select a non-stacking header for the RPi GPIO Header and to select either pin 
arrays or spring terminals for the T1 and T2.                   

\section{Circuit Board Layout}

\begin{figure}[hbpt]\begin{centering}%
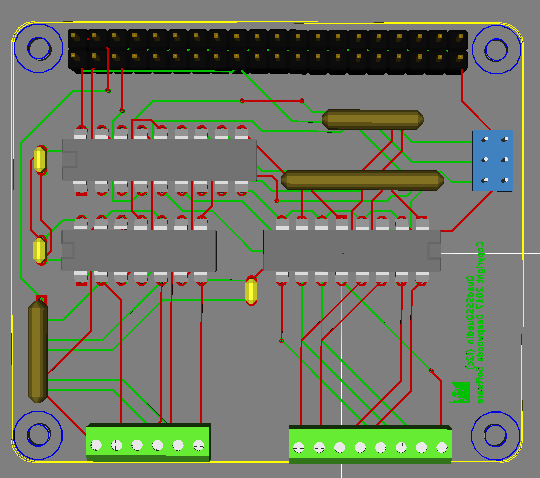
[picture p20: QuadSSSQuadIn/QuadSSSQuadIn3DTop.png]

\caption{3D rendering of the QuadSSSQuadIn board}
\end{centering}\end{figure}
\begin{figure}[hbpt]\begin{centering}%
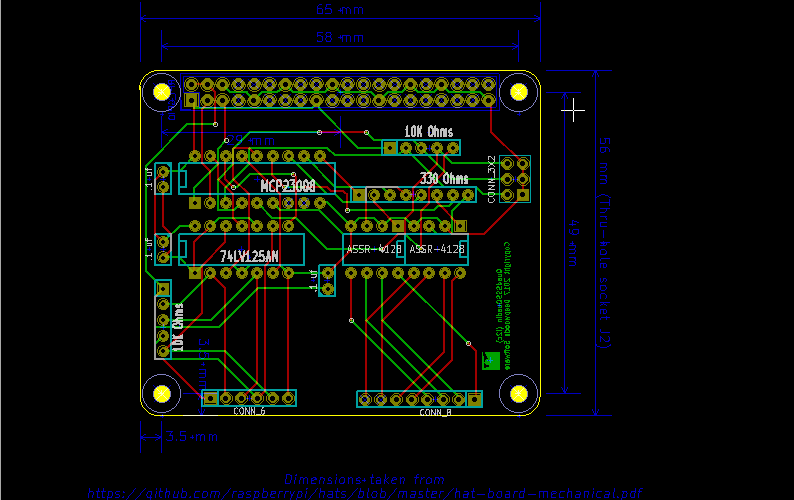
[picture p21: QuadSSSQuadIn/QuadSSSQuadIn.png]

\caption{Fabrication image of the QuadSSSQuadIn board}
\end{centering}\end{figure}
Board assembly is straight forward.  You need to be careful orienting the ICs, 
noting that the SSRs are oppositely oriented from the other ICs.  Also the 
SIP resistor arrays need to be carefully oriented -- the dot marks pin 1, 
which is indicated on the board with a square pad\footnote{The first batch of 
the boards I ordered used the wrong PCB modules for the terminals and the 
holes are too small for the screw terminal pins to go all the way in.  They 
can be ``jammed'' in enough to be soldered. Pin arrays fit a little better, 
but still need some effort to seat.  The next batch I order will not have this 
problem.}. 

\section{Downloadables and Software Support}

Full design information is available on GitHub here:
\url{https://github.com/RobertPHeller/RPi-RRCircuits/tree/master/QuadSSSQuadIn}.

This board is supported by the Model Railroad System\footnote{Available as a 
free download from Deepwoods Software at this web address: 
\url{http://www.deepsoft.com/home/products/modelrailroadsystem/}.}
\texttt{OpenLCB\_PiMCP23008} daemon. A basic XML file for it is included in 
its GitHub folder.

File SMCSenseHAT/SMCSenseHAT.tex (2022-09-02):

%%%%%%%%%%%%%%%%%%%%%%%%%%%%%%%%%%%%%%%%%%%%%%%%%%%%%%%%%%%%%%%%%%%%%%%%%%%%%
%
%  System        : 
%  Module        : 
%  Object Name   : $RCSfile$
%  Revision      : $Revision$
%  Date          : $Date$
%  Author        : $Author$
%  Created By    : Robert Heller
%  Created       : Wed May 31 20:05:00 2017
%  Last Modified : <220902.0851>
%
%  Description 
%
%  Notes
%
%  History
% 
%%%%%%%%%%%%%%%%%%%%%%%%%%%%%%%%%%%%%%%%%%%%%%%%%%%%%%%%%%%%%%%%%%%%%%%%%%%%%
%
%    Copyright (C) 2017  Robert Heller D/B/A Deepwoods Software
%			51 Locke Hill Road
%			Wendell, MA 01379-9728
%
%    This program is free software; you can redistribute it and/or modify
%    it under the terms of the GNU General Public License as published by
%    the Free Software Foundation; either version 2 of the License, or
%    (at your option) any later version.
%
%    This program is distributed in the hope that it will be useful,
%    but WITHOUT ANY WARRANTY; without even the implied warranty of
%    MERCHANTABILITY or FITNESS FOR A PARTICULAR PURPOSE.  See the
%    GNU General Public License for more details.
%
%    You should have received a copy of the GNU General Public License
%    along with this program; if not, write to the Free Software
%    Foundation, Inc., 675 Mass Ave, Cambridge, MA 02139, USA.
%
% 
%
%%%%%%%%%%%%%%%%%%%%%%%%%%%%%%%%%%%%%%%%%%%%%%%%%%%%%%%%%%%%%%%%%%%%%%%%%%%%%

\chapter{SMCSenseHAT: Stall Motor Control and Sense HAT}

This is a circuit board to for an add-on board for a Raspberry Pi B+ that will
control  two  stall-motor  turnout  motors for a model  railroad.  It also has
sense  logic to return the state of the  turnouts,  using one pole of the DPDT
contacts in the stall-motor (typical of Tortoise stall-motors).

The circuit board uses a 40pin header socket to connect to the 40pin header on
the  Raspberry Pi B+ and can use a  stack-through  header to allow  additional
boards to be stacked on top of it.

The circuit board presented in the SMCSenseHAT1 directory is nearly identical 
to this one.  The only difference is the use of a different set of four GPIO 
pins.

\section{GPIO Pins Used and stacking restrictions.}

This board uses four GPIO pins:

\begin{description}
\item[WiringPi 0, BCM 17] Motor Select 1: select the position of stall motor 
1. 
\item[WiringPi 1, BCM 18] Motor Select 2: select the position of stall motor 
2. 
\item[WiringPi 2, BCM 27] Point Sense 1: return the state of the points for 
stall motor 1. 
\item[WiringPi 3, BCM 22] Point Sense 2: return the state of the points for 
stall motor 2. 
\end{description}

Each of the motor drive circuits is through a transistor that can handle 1 amp 
continuous collector current, which is way more needed to drive typical stall 
motor.  It is enough to drive a pair of stall motors, wired in parallel as 
would be the case for a cross over.

Because this board is hardwired to use four specific GPIO pins it is not 
possible to use two or more of these boards on given Raspberry Pi.  But in the 
SMCSenseHAT1 directory is a nearly identical board, that uses a different set 
of four GPIO pins:

\begin{description}
\item[WiringPi 4, BCM 23] Motor Select 1: select the position of stall motor 
1. 
\item[WiringPi 5, BCM 24] Motor Select 2: select the position of stall motor 
2. 
\item[WiringPi 6, BCM 25] Point Sense 1: return the state of the points for 
stall motor 1. 
\item[WiringPi 7, BCM 4] Point Sense 2: return the state of the points for 
stall motor 2. 
\end{description}

It is possible use one each of the SMCSenseHAT and SMCSenseHAT1 boards to 
handle four separate turnouts.  You should only connect at most one of each of 
these boards on a single Raspberry Pi.

\section{Circuit Description}

\begin{figure}[hbpt]\begin{centering}%

\caption{Circuit Diagram of the SMCSenseHAT}
\end{centering}\end{figure}
This circuit contains two sections.  There is an output section that contains 
a dual opto-isolator, a quad op-amp, and a quad driver (NPN) transistor.  An 
opto-isolated GPIO output pin drives one pair of op-amps, which in turn drive 
a pair of driver transistors.  Each GPIO output pin drives its pair of op-amps 
on their opposite plus and minus inputs, thus driving only one or the other of 
this pair of op-amps at a time.  That is the GPIO output pin drives one op-amp 
on when the GPIO output pin is high and drives the other op-amp on when the 
GPIO output pin is low.  On the output side only one of the pair of driver 
transistors is on at a time.  This results in only one or the other of the 
motor drive connections at ground (-) and the other pulled up to 12-16 Volts 
(+).  This causes the stall motor to rotate in one or the other direction, 
moving the turnout points one way or the other.

The other section is a pair of flip-flop debounce circuits, one for each of 
two SPDT switch contacts that report the position of the turnout points.  The 
output of these flip-flops goes to a pair of GPIO input pins.

\section{Parts List}

\begin{table}[htp]
\begin{centering}\begin{tabular}{|l|l|p{1in}|l|p{.5in}|}
\hline
Value&Qty&Refs&Mouser Part Number&Adafruit Part Number \\
\hline
1uf 35V&1&C1&74-199D105X9035A1VE3& \\
\hline
.1 uf&1&C2&21RZ310-RC& \\
\hline
1N4002&2&D1 D2&833-1N4002-TP& \\
\hline
MCT6H&1&IC1&782-MCT6H& \\
\hline
RPi GPIO Header&1&J0&855-M20-6102045&2223 \\
\hline
MPQ3725A&1&Q1&610-MPQ3725A& \\
\hline
100 Ohms&2&R1 R2&603-CFR-25JR-52100R& \\
\hline
470 Ohms&4&R13 R15 R17 R19&279-CFR50J470R& \\
\hline
1K Ohms&7&R3 R4 R5 R12 R14 R16 R18&279-2-1623927-3& \\
\hline
270 Ohms&2&R6 R7&603-CFR-25JR-52-270R& \\
\hline
10K Ohms&4&R8 R9 R10 R11&603-CFR-25JR-5210K& \\
\hline
Motor terminals&2&T1 T2&571-282834-5& \\
\hline
12 to 16 Volts terminals&1&T3&571-282834-2& \\
\hline
74AHCT00&1&U1&595-SN74AHC00N& \\
\hline
LM324N&1&U2&512-LM324N& \\
\hline
1N5229B&1&Z1&512-1N5229BTR& \\
\hline
\end{tabular}
\caption{Parts list for SMCSenseHAT or SMCSenseHAT1 boards.}
\end{centering}\end{table}\footnote{Mouser Project link: 
\url{http://www.mouser.com/ProjectManager/ProjectDetail.aspx?AccessID=259711af97}.}

The only parts that might be substituted are J0 (the RPi GPIO Header), and T1 
and T2 (the Motor terminals) and T3 (the 12 to 16 Volts terminals).  The parts 
listed are for the stacking headers for the RPi GPIO Header, and screw 
terminals for the Motor terminals and the motor power terminals.  Feel free to 
select a non-stacking header for the RPi GPIO Header and to select either pin 
arrays or spring terminals for the T1, T2, and T3.

\section{Circuit Board Layout}

\begin{figure}[hbpt]\begin{centering}%
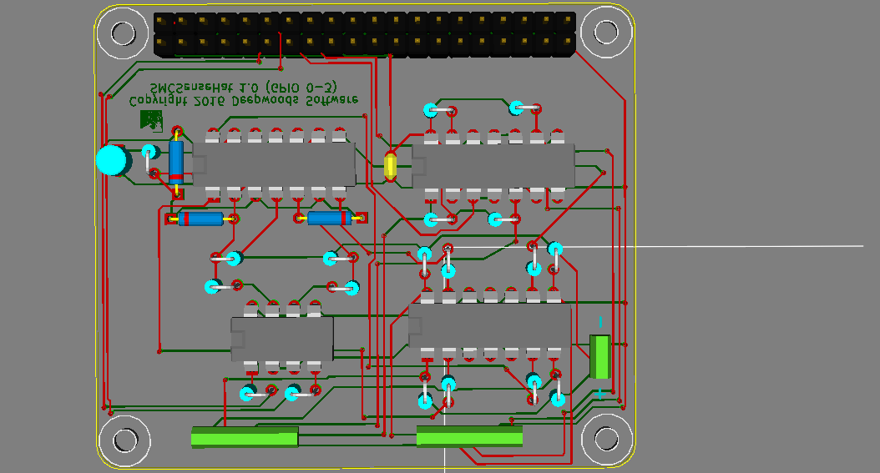
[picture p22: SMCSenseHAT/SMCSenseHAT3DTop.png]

\caption{3D rendering of the SMCSenseHAT board}
\end{centering}\end{figure}
\begin{figure}[hbpt]\begin{centering}%
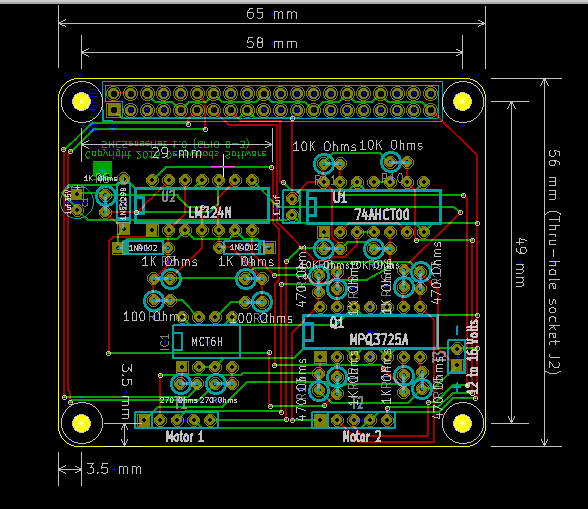
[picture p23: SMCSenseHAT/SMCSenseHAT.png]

\caption{Fabrication image of the SMCSenseHAT board}
\end{centering}\end{figure}
Board assembly is straight forward.  You need to be careful orienting the ICs, 
diodes, and the electrolytic capacitor\footnote{The first batch of the boards 
I ordered used the wrong PCB modules for the terminals and the holes are too 
small for the screw terminal pins to go all the way in.  They can be 
``jammed'' in enough to be soldered. Pin arrays fit a little better, but still 
need some effort to seat.  The next batch I order will not have this 
problem.}. 

\section{Downloadables and Software Support}

Full design information is available on GitHub here: 
\url{https://github.com/RobertPHeller/RPi-RRCircuits/tree/master/SMCSenseHAT} 
and here:
\url{https://github.com/RobertPHeller/RPi-RRCircuits/tree/master/SMCSenseHAT1}.

This board is supported by the Model Railroad System\footnote{Available as a 
free download from Deepwoods Software at this web address: 
\url{http://www.deepsoft.com/home/products/modelrailroadsystem/}.}
\texttt{OpenLCB\_PiGPIO} daemon. A basic XML file for it is included in its
GitHub folder.

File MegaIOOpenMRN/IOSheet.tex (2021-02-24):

%%%%%%%%%%%%%%%%%%%%%%%%%%%%%%%%%%%%%%%%%%%%%%%%%%%%%%%%%%%%%%%%%%%%%%%%%%%%%
%
%  System        : 
%  Module        : 
%  Object Name   : $RCSfile$
%  Revision      : $Revision$
%  Date          : $Date$
%  Author        : $Author$
%  Created By    : Robert Heller
%  Created       : Mon Jan 25 15:28:51 2021
%  Last Modified : <210125.1619>
%
%  Description 
%
%  Notes
%
%  History
% 
%%%%%%%%%%%%%%%%%%%%%%%%%%%%%%%%%%%%%%%%%%%%%%%%%%%%%%%%%%%%%%%%%%%%%%%%%%%%%
%
%    Copyright (C) 2021  Robert Heller D/B/A Deepwoods Software
%			51 Locke Hill Road
%			Wendell, MA 01379-9728
%
%    This program is free software; you can redistribute it and/or modify
%    it under the terms of the GNU General Public License as published by
%    the Free Software Foundation; either version 2 of the License, or
%    (at your option) any later version.
%
%    This program is distributed in the hope that it will be useful,
%    but WITHOUT ANY WARRANTY; without even the implied warranty of
%    MERCHANTABILITY or FITNESS FOR A PARTICULAR PURPOSE.  See the
%    GNU General Public License for more details.
%
%    You should have received a copy of the GNU General Public License
%    along with this program; if not, write to the Free Software
%    Foundation, Inc., 675 Mass Ave, Cambridge, MA 02139, USA.
%
% 
%
%%%%%%%%%%%%%%%%%%%%%%%%%%%%%%%%%%%%%%%%%%%%%%%%%%%%%%%%%%%%%%%%%%%%%%%%%%%%%

\documentclass[12pt,twoside]{article}
\title{Mega I/O -- BufferBoard-2 I/O Sheet}
\author{Robert Heller \\ The Country Robot \\ Wendell, MA, USA}
\date{\today}
\newcommand{\ledgrouptopcommon}[1]{%
\begin{tabular}{|l|p{1in}|p{2in}|}
\hline
\multicolumn{3}{|c|}{#1}\\
\hline
TL&Cable/Color&Function\\
\hline
C&~~~~~~~~~~~&~~~~~~~~~~~~~~~~~\\
\hline
8&~~~~~~~~~~~&~~~~~~~~~~~~~~~~~\\
\hline
7&~~~~~~~~~~~&~~~~~~~~~~~~~~~~~\\
\hline
6&~~~~~~~~~~~&~~~~~~~~~~~~~~~~~\\
\hline
5&~~~~~~~~~~~&~~~~~~~~~~~~~~~~~\\
\hline
4&~~~~~~~~~~~&~~~~~~~~~~~~~~~~~\\
\hline
3&~~~~~~~~~~~&~~~~~~~~~~~~~~~~~\\
\hline
2&~~~~~~~~~~~&~~~~~~~~~~~~~~~~~\\
\hline
1&~~~~~~~~~~~&~~~~~~~~~~~~~~~~~\\
\hline
\end{tabular}}
\newcommand{\ledgroupbottomcommon}[1]{%
\begin{tabular}{|l|p{1in}|p{2in}|}
\hline
\multicolumn{3}{|c|}{#1}\\
\hline
TL&Cable/Color&Function\\
\hline
1&~~~~~~~~~~~&~~~~~~~~~~~~~~~~~\\
\hline
2&~~~~~~~~~~~&~~~~~~~~~~~~~~~~~\\
\hline
3&~~~~~~~~~~~&~~~~~~~~~~~~~~~~~\\
\hline
4&~~~~~~~~~~~&~~~~~~~~~~~~~~~~~\\
\hline
5&~~~~~~~~~~~&~~~~~~~~~~~~~~~~~\\
\hline
6&~~~~~~~~~~~&~~~~~~~~~~~~~~~~~\\
\hline
7&~~~~~~~~~~~&~~~~~~~~~~~~~~~~~\\
\hline
8&~~~~~~~~~~~&~~~~~~~~~~~~~~~~~\\
\hline
C&~~~~~~~~~~~&~~~~~~~~~~~~~~~~~\\
\hline
\end{tabular}}
\newcommand{\inputterms}[1]{%
\begin{tabular}{|l|p{1in}|p{2in}|}
\hline
\multicolumn{3}{|c|}{#1}\\
\hline
TL&Cable/Color&Function\\
\hline                                                                 
8A&~~~~~~~~~~~&~~~~~~~~~~~~~~~~~\\
\hline
8B&~~~~~~~~~~~&~~~~~~~~~~~~~~~~~\\
\hline
7A&~~~~~~~~~~~&~~~~~~~~~~~~~~~~~\\
\hline
7B&~~~~~~~~~~~&~~~~~~~~~~~~~~~~~\\
\hline
6&~~~~~~~~~~~&~~~~~~~~~~~~~~~~~\\
\hline
5&~~~~~~~~~~~&~~~~~~~~~~~~~~~~~\\
\hline
GND&~~~~~~~~~~~&~~~~~~~~~~~~~~~~~\\
\hline
\end{tabular}}
\parskip=15pt
\parindent=0pt
\begin{document}
%\maketitle

\section{Left side, top to bottom}

\ledgrouptopcommon{J3: GPIO 2}

\ledgrouptopcommon{J2: GPIO 1}

\ledgrouptopcommon{J4: GPIO 4}

\ledgrouptopcommon{J5: GPIO 3}

%\clearpage
\section{Right side, top to bottom}

\ledgroupbottomcommon{J8: GPIO 6}

\ledgroupbottomcommon{J7: GPIO 5}

\inputterms{J9: GPIO 7}

\end{document}

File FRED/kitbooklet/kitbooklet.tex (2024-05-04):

%%%%%%%%%%%%%%%%%%%%%%%%%%%%%%%%%%%%%%%%%%%%%%%%%%%%%%%%%%%%%%%%%%%%%%%%%%%%%
%
%  System        : 
%  Module        : 
%  Object Name   : $RCSfile$
%  Revision      : $Revision$
%  Date          : $Date$
%  Author        : $Author$
%  Created By    : Robert Heller
%  Created       : Fri May 3 11:25:06 2024
%  Last Modified : <240503.2324>
%
%  Description 
%
%  Notes
%
%  History
% 
%%%%%%%%%%%%%%%%%%%%%%%%%%%%%%%%%%%%%%%%%%%%%%%%%%%%%%%%%%%%%%%%%%%%%%%%%%%%%
%
%    Copyright (C) 2024  Robert Heller D/B/A Deepwoods Software
%			51 Locke Hill Road
%			Wendell, MA 01379-9728
%
%    This program is free software; you can redistribute it and/or modify
%    it under the terms of the GNU General Public License as published by
%    the Free Software Foundation; either version 2 of the License, or
%    (at your option) any later version.
%
%    This program is distributed in the hope that it will be useful,
%    but WITHOUT ANY WARRANTY; without even the implied warranty of
%    MERCHANTABILITY or FITNESS FOR A PARTICULAR PURPOSE.  See the
%    GNU General Public License for more details.
%
%    You should have received a copy of the GNU General Public License
%    along with this program; if not, write to the Free Software
%    Foundation, Inc., 675 Mass Ave, Cambridge, MA 02139, USA.
%
% 
%
%%%%%%%%%%%%%%%%%%%%%%%%%%%%%%%%%%%%%%%%%%%%%%%%%%%%%%%%%%%%%%%%%%%%%%%%%%%%%

\documentclass[12pt,twoside,letterpaper]{article}
\usepackage{graphicx}
\usepackage{mathptm}
\usepackage{times}
\usepackage{makeidx}
\usepackage{ifpdf}
\usepackage{footmisc}
\ifpdf
\usepackage[pdftex,
            pagebackref=true,
            colorlinks=true,
            linkcolor=blue,
            unicode
           ]{hyperref}
\else
\usepackage[ps2pdf,
            pagebackref=true,
            colorlinks=true,
            linkcolor=blue,
            unicode
           ]{hyperref}
\usepackage{pspicture}
\fi
\usepackage{url}
\pagestyle{headings}
\emergencystretch=50pt
\setcounter{tocdepth}{3}
\setcounter{secnumdepth}{3}
\title{FRED (EOT) flashing board.}
\author{Robert Heller \\ The Country Robot \\ Wendell, MA, USA}
\date{\today}
\begin{document}
\maketitle

This is a circuit board that implements a FRED (Flashing Rear End 
Device)\footnote{Also know as an EOT (End Of Train) device.}. This little 
circuit board rides in the trailing truck of the last freight car of a train 
and flashes a LED mounted on a FRED riding in the trailing coupler of that 
freight car.

\section{Assembly}

\section{Separating the two boards}
\begin{figure}[hbpt]\begin{centering}%
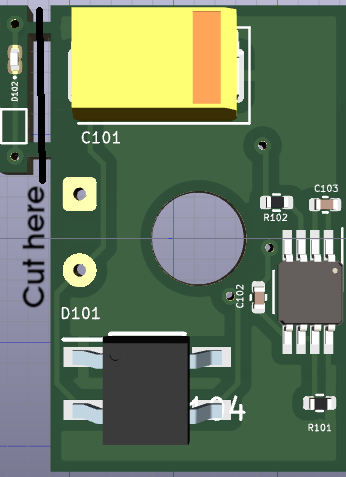
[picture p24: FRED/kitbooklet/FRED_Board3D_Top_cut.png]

\caption{Cutting the boards apart}
\label{fig:boardcut}
\end{centering}\end{figure}
The circuit board is mostly assembled.  It is necessary to solder on two small 
pieces of phosphor bronze that will be the wiper contacts to pick up power 
from the track. The two small pieces of phosphor bronze are soldered onto the 
labeled pad on the back side of the board and then bent into ``V'' shapes. It 
is also necessary to cut the board into two pieces, as shown in 
Figure~\ref{fig:boardcut}. After cutting the boards apart, carefully sand the 
cuts flush.

\section{Installing the power pickup wipers on the main board}

\begin{figure}[hbpt]\begin{centering}%

\caption{Wiper strips soldered on}
\label{fig:FRED_with_wipers_not_bent}
\end{centering}\end{figure}
\begin{figure}[hbpt]\begin{centering}%

\caption{Wiper strips bent}
\label{fig:FRED_with_wipers_bent}
\end{centering}\end{figure}
Next cut two pieces of phosphor bronze sheet, 13.5mm x 16mm and solder them to
the pads on the bottom at the ends of the nain board, with 12.5mm extending
beyond the ends of the board, as shown in
Figure~\ref{fig:FRED_with_wipers_not_bent}. Once soldered, bend the pieces up
(under the board) as shown in Figure~\ref{fig:FRED_with_wipers_bent}.

\section{Installing the LED board on the EOT}

If you model EOT does not have a LED in it you can use the little LED board. 
You can sand down the back of the EOT and drill a hole for the LED on the LED 
board.  Then glue the LED board on the back of the EOT, with the LED in the 
hole.

\section{Wiring}

Solder two fine gauge hookup wires (typically red on plus(+) and black on 
negative(-)) between the EOT's LED (or LED board) and the back side of the 
main board.  The wires need to be long enough to reach from the coupler and 
the truck, with a little extra to allow for truck movement.

\section{Installing on a car}

You need a car with metal wheels and metal axles (which have an insulator on 
one wheel).  Pop one wheelset out and hook one of the wipers on the remaining 
wheelset axle.  Fit the removed wheelset in the other wiper, taking care that 
the insulator is at the opposite side from the wheelset.  Pop the wheelset in 
place.  The board should now be suspended from the wipers hanging on the 
axles. 

\end{document}

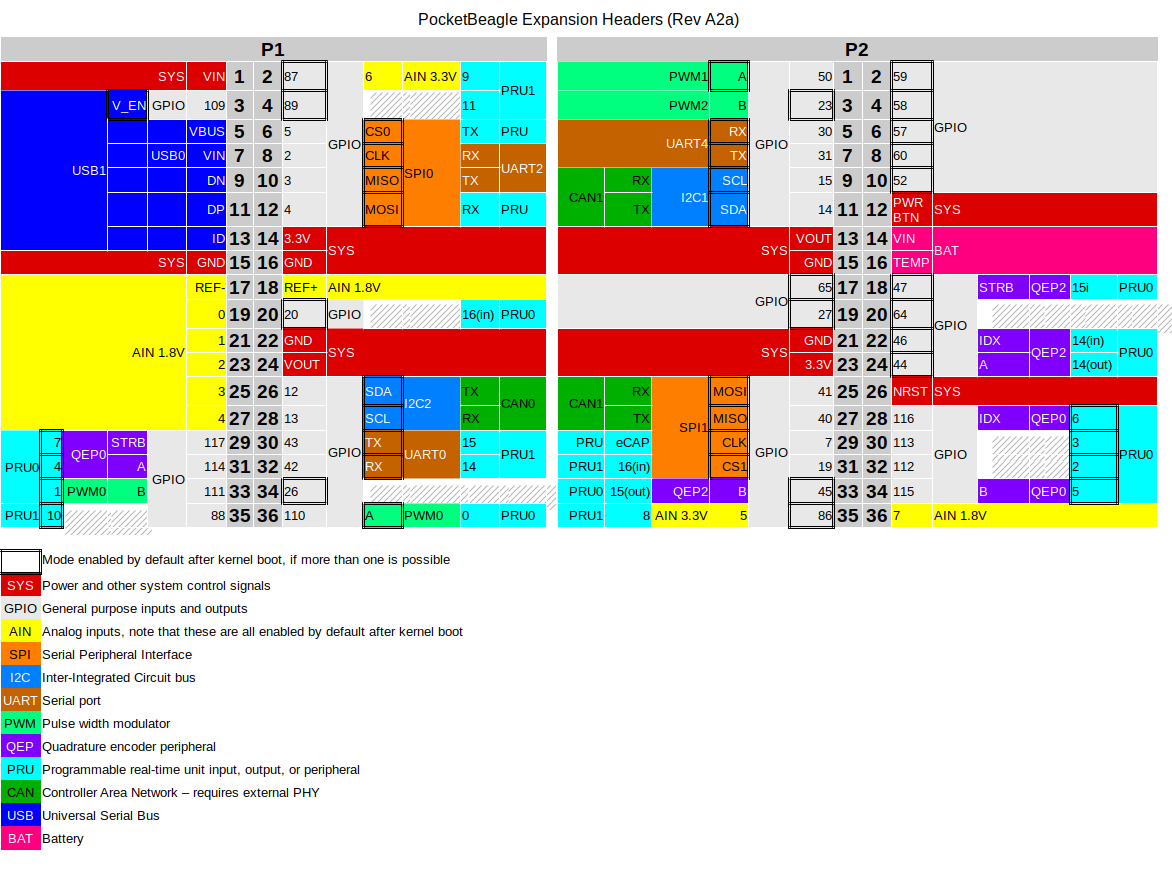
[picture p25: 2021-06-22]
PocketBeagleMultifuntion/PocketBeagle_pinout.png

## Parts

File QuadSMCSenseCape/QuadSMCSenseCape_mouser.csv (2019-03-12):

Value | Quantity | References | Mouser Part Number | Adafruit Part Number
10 uf 35V | 1 | C1 | 667-ECA-1HM100I
.1 uf | 3 | C2 C3 C8 | 581-SR201C104KARTR1
WP 1 0 | 1 | P2 | 649-67996-406HLF
BeagleBone_Black_Header | 2 | P8 P9 | 200-ESQ12314GD
5.6K Ohms | 2 | R3 R4 | 603-CFR-25JR-525K6
4.75K Ohms | 3 | R5 R6 R7 | 603-CFR-25JR-524K7
10K Ohms | 1 | R8 | 603-CFR-25JR-5210K
10K Ohms | 1 | RR1 | 652-4609X-1LF-10K
Motor 1;Motor 2;Motor 3;Motor 4 | 4 | T1 T2 T3 T4 | 651-1725685
+ 12V - | 1 | T5 | 651-1725656
TC4428 | 4 | U1 U2 U3 U4 | 579-TC4428VPA
74HCT00 | 2 | U5 U6 | 595-SN74AHC00N
CAT24C256W | 1 | U9 | 698-CAT24C256WI-GT3

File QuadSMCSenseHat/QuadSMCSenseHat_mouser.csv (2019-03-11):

Value | Quantity | References | Mouser Part Number | Adafruit Part Number
.1 uf | 2 | C1 C2 | 581-SR201C104KARTR1
10 uf 35V | 1 | C3 | 667-ECA-1HM100I
RPi_GPIO | 1 | J0 | 855-M20-6102045
10K Ohms | 1 | RR1 | 652-4609X-1LF-10K
Motor 1;Motor 2;Motor 3;Motor 4 | 4 | T1 T2 T3 T4 | 651-1725685
+ 12V - | 1 | T5 | 651-1725656
TC4428 | 4 | U1 U2 U3 U4 | 579-TC4428VPA
74HCT00 | 2 | U5 U6 | 595-SN74AHC00N

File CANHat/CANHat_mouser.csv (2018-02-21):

Value | Quantity | References | Mouser Part Number | Adafruit Part Number
10 uf | 1 | C1 | 667-ECA-1HM100I
22 pf | 2 | C2 C4 | 594-K220J10C0GF5UH5
.1 uf | 2 | C3 C6 | 21RZ310-RC
15 uf | 1 | C5 | 667-EEA-GA1H150
1N4001 | 1 | D1 | 833-1N4001-TP
RPi_GPIO | 1 | J0 | 855-M20-6102045 | 2223
SPI Select | 1 | J1 | 538-22-28-8034
RJ45 | 2 | J2 J3 | 592-RJ45-8N-S
10K Ohms | 1 | R1 | 603-CFR-25JR-5210K
12V supply | 1 | T1 | 571-1776118-2
MCP2515 | 1 | U1 | 579-MCP2515-I/P
MCP2551 | 1 | U2 | 579-MCP2551-I/P
16 MHz | 1 | X1 | 449-LFXTAL027945BULK

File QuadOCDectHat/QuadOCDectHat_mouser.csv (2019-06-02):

Value | Quantity | References | Mouser Part Number | Adafruit Part Number
BRIDGEX | 4 | D1 D2 D3 D4 | 750-KBL401-G
MCT6H | 4 | IC1 IC2 IC3 IC4 | 782-MCT6H
RPi_GPIO | 1 | J0
10 Ohms | 4 | R1 R3 R5 R7 | CFR-25JR-52-10R
10K Ohms | 4 | R2 R4 R6 R8 | 603-CFR-25JB-52-10K
In Track1 Out;In Track2 Out;In Track3 Out;In Track4 Out | 4 | T1 T2 T3 T4 | 649-220316-H021B01LF

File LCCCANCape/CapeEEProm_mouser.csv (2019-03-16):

Value | Quantity | References | Mouser Part Number | Adafruit Part Number
.1 uf | 1 | C8 | 581-SR201C104KARTR1
WP 1 0 | 1 | P2 | 649-67996-406HLF
5.6K Ohms | 2 | R3 R4 | 603-CFR-25JR-525K6
4.75K Ohms | 3 | R5 R6 R7 | 603-CFR-25JR-524K7
10K Ohms | 1 | R8 | 603-CFR-25JR-5210K
CAT24C256W | 1 | U9 | 698-CAT24C256WI-GT3

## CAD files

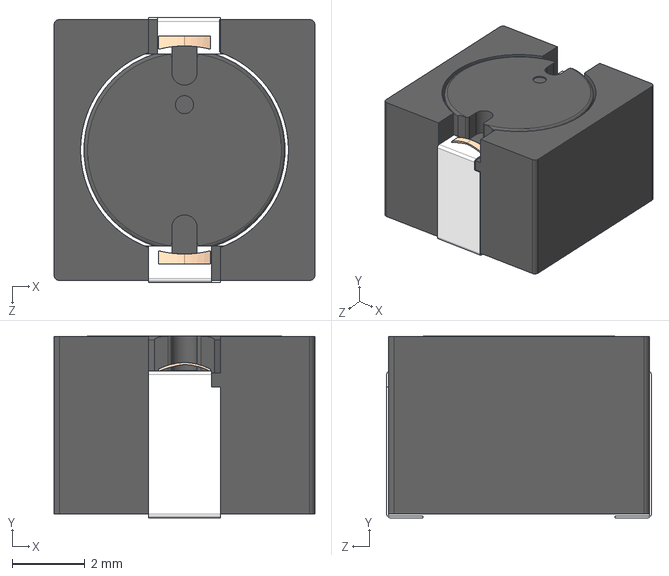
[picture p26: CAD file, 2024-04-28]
STM32F767ZI_LCC_PNET_Router/B1047AS-4R7N=P3.stp
7.20 x 5.01 x 7.30 mm

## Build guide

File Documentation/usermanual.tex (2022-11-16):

%%%%%%%%%%%%%%%%%%%%%%%%%%%%%%%%%%%%%%%%%%%%%%%%%%%%%%%%%%%%%%%%%%%%%%%%%%%%%
%
%  System        : 
%  Module        : 
%  Object Name   : $RCSfile$
%  Revision      : $Revision$
%  Date          : $Date$
%  Author        : $Author$
%  Created By    : Robert Heller
%  Created       : Wed May 31 19:37:01 2017
%  Last Modified : <221116.0903>
%
%  Description 
%
%  Notes
%
%  History
% 
%%%%%%%%%%%%%%%%%%%%%%%%%%%%%%%%%%%%%%%%%%%%%%%%%%%%%%%%%%%%%%%%%%%%%%%%%%%%%
%
%    Copyright (C) 2017  Robert Heller D/B/A Deepwoods Software
%			51 Locke Hill Road
%			Wendell, MA 01379-9728
%
%    This program is free software; you can redistribute it and/or modify
%    it under the terms of the GNU General Public License as published by
%    the Free Software Foundation; either version 2 of the License, or
%    (at your option) any later version.
%
%    This program is distributed in the hope that it will be useful,
%    but WITHOUT ANY WARRANTY; without even the implied warranty of
%    MERCHANTABILITY or FITNESS FOR A PARTICULAR PURPOSE.  See the
%    GNU General Public License for more details.
%
%    You should have received a copy of the GNU General Public License
%    along with this program; if not, write to the Free Software
%    Foundation, Inc., 675 Mass Ave, Cambridge, MA 02139, USA.
%
% 
%
%%%%%%%%%%%%%%%%%%%%%%%%%%%%%%%%%%%%%%%%%%%%%%%%%%%%%%%%%%%%%%%%%%%%%%%%%%%%%

\documentclass[12pt,notitlepage,twoside]{book}
\usepackage{graphicx}
\usepackage{mathptm}
\usepackage{times}
\usepackage{makeidx}
\usepackage{ifpdf}
\usepackage{footmisc}                                                           
\ifpdf
\usepackage[pdftex,
            pagebackref=true,
            colorlinks=true,
            linkcolor=blue,
            unicode
           ]{hyperref}
\else
\usepackage[ps2pdf,
            pagebackref=true,
            colorlinks=true,
            linkcolor=blue,
            unicode
           ]{hyperref}
\usepackage{pspicture}
\fi
\usepackage{url}
\pagestyle{headings}
\makeindex
\emergencystretch=50pt
\setcounter{tocdepth}{3}
\setcounter{secnumdepth}{3}
\includeonly{LCCCANCape,ESP32-PWMHalfSidingSMD,ESP32-S3-MultiFunction,PocketBeagleCommandStation}
\begin{document}
\title{Railroad Circuits for the Raspberry Pi, Beagle Bone Black, Pocket Beagle, and ESP32}
\author{Robert Heller \\ The Country Robot \\ Wendell, MA, USA}
\date{\today}
\begin{titlepage}

\maketitle

\clearpage

This documentation was prepared with \LaTeX.

\vspace{.25in}

{\small Copyright \copyright 2017-2019 by Robert Heller D/B/A The Country Robot}
\vspace{.25in}

All rights reserved.  Permission is granted to copy this document in
electronic form only, so long as it is with the software it
documents. 

\vspace{.125in}

The author, Robert Heller, may be contacted electronically (E-Mail) via
\url{mailto:heller@thecountryrobot.com}.

\vspace{.25in}

The Country Robot's web site URL: \url{http://www.thecountryrobot.com/}.

\thispagestyle{empty}
\setcounter{page}{0}
\clearpage

\end{titlepage}

\pagenumbering{roman}
\tableofcontents
\listoffigures
\listoftables
\cleardoublepage
\chapter*{Preface}
\addcontentsline{toc}{chapter}{Preface}

This booklet describes a collection of circuit boards I designed to make use 
of Raspberry Pi GPIO pins to be used in the control of a model railroad 
layout.  I am not formally trained as an electronics engineer, but these 
circuits are fairly simple and are readily cribbed from the data sheets of the 
various microchips used.  If someone who is a trained electronics engineer 
finds something wrong, I would of course like to hear about it.

\cleardoublepage
\pagenumbering{arabic}
\chapter{General Information}

Many of these boards are add on boards for a Raspberry Pi ``B'' model, 
one with a 40-pin header and have the mechanical form factor of a Raspberry Pi 
``HAT''.  Since none of them have an eeprom on them, they are technically not 
actual ``HATs''.  These boards can be ``stacked'', with some limitations, as 
indicated in their respective chapters, mainly because some of these boards 
are hard wired to use specific GPIO pins.  It is therefore possible to use 
``stacking'' (or ``stack through'') headers, headers that are both female 
sockets and male pins.  The end user has a choice of headers to use: standard 
female only headers, long female only headers, standard ``stacking'' headers 
or long/tall ``stacking'' headers.  In the chapters for each board in the 
parts list section, I list the various header options, with part numbers and 
suppliers.  Other boards are stackable ``Capes'' for the Beagle Bone Black. 
Again, since many of these boards are stackable, ``stacking'' (or ``stack 
through'') headers can be used.  Still other boards are for the Pocket Beagle 
and the ESP32 devkit board.  These latter are not meant to be stackable and 
for these, the add on board goes \textit{under} the processor board.  Unlike 
the Raspberry Pi and Beagle Bone Black, these smaller boards have no mounting 
holes, but the ``add on'' boards do.  Also for these smaller boards the add 
on boards provide power to the processor board.

Another place where the end user has choices is in the terminal blocks.  With 
some exceptions (mostly for higher power cases), all of the terminal blocks 
are specified as .1'' (2.54mm) pitch screw terminals.  It is possible to 
substitute other .1'' (2.54mm) pitch connections, including vertical or right 
angle pin arrays or even spring terminals.  This will depend on what sort of 
interconnection technology the end user would prefer.  In the parts list will 
be the various alternative options.

All of the boards use mostly through-hole parts and should be fairly easy to
hand solder with a basic good quality soldering iron. All of the components
are standard and readily available from various suppliers (like Mouser or
Digi-Key).

Most of the boards have mounting holes.  The mounting holes on the HAT-like 
boards align over the mounting holes in the Raspberry Pi.  Using standard 
height headers allows about 3/8'' between boards and using tall headers allows 
1/2'' between boards.  It is probably a good idea to use spacer hardware to 
secure the boards.  Male/female 4-40 threaded hex spacers work quite well, 
although the boards are designed to use M2.5 hardware (Adafruit sells M2.5 
male/female threaded hex spacers in pairs).

\include{SMCSenseHAT}
\include{QuadSSSQuadIn}
\include{MCP23017}
\include{OctalLEDDriver}
\include{LCCCANCape}
\include{QuadSMCSenseHat}
\include{QuadSMCSenseCape}
\include{PocketBeagleQuadSMCSense}
\include{ESP32QuadSMCSense}
\include{ESP32-PWMHalfSiding}
\include{ESP32-PWMHalfSidingSMD}
\include{ESP32-S3-MultiFunction}
\include{PocketBeagleCommandStation}
\cleardoublepage
%\bibliography{MRR}
%\bibliographystyle{plain}
\cleardoublepage
\printindex
\end{document}

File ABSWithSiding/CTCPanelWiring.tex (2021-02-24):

%%%%%%%%%%%%%%%%%%%%%%%%%%%%%%%%%%%%%%%%%%%%%%%%%%%%%%%%%%%%%%%%%%%%%%%%%%%%%
%
%  System        : 
%  Module        : 
%  Object Name   : $RCSfile$
%  Revision      : $Revision$
%  Date          : $Date$
%  Author        : $Author$
%  Created By    : Robert Heller
%  Created       : Mon Jan 25 15:28:51 2021
%  Last Modified : <210224.0945>
%
%  Description 
%
%  Notes
%
%  History
% 
%%%%%%%%%%%%%%%%%%%%%%%%%%%%%%%%%%%%%%%%%%%%%%%%%%%%%%%%%%%%%%%%%%%%%%%%%%%%%
%
%    Copyright (C) 2021  Robert Heller D/B/A Deepwoods Software
%			51 Locke Hill Road
%			Wendell, MA 01379-9728
%
%    This program is free software; you can redistribute it and/or modify
%    it under the terms of the GNU General Public License as published by
%    the Free Software Foundation; either version 2 of the License, or
%    (at your option) any later version.
%
%    This program is distributed in the hope that it will be useful,
%    but WITHOUT ANY WARRANTY; without even the implied warranty of
%    MERCHANTABILITY or FITNESS FOR A PARTICULAR PURPOSE.  See the
%    GNU General Public License for more details.
%
%    You should have received a copy of the GNU General Public License
%    along with this program; if not, write to the Free Software
%    Foundation, Inc., 675 Mass Ave, Cambridge, MA 02139, USA.
%
% 
%
%%%%%%%%%%%%%%%%%%%%%%%%%%%%%%%%%%%%%%%%%%%%%%%%%%%%%%%%%%%%%%%%%%%%%%%%%%%%%

\documentclass[12pt,twoside]{article}
\title{Mega I/O -- BufferBoard-2 I/O Sheet}
\author{Robert Heller \\ The Country Robot \\ Wendell, MA, USA}
\date{\today}
\newcommand{\ledgrouptopcommon}[1]{%
\begin{tabular}{|l|p{1in}|p{2in}|}
\hline
\multicolumn{3}{|c|}{#1}\\
\hline
TL&Cable/Color&Function\\
\hline
C&~~~~~~~~~~~&~~~~~~~~~~~~~~~~~\\
\hline
8&~~~~~~~~~~~&~~~~~~~~~~~~~~~~~\\
\hline
7&~~~~~~~~~~~&~~~~~~~~~~~~~~~~~\\
\hline
6&~~~~~~~~~~~&~~~~~~~~~~~~~~~~~\\
\hline
5&~~~~~~~~~~~&~~~~~~~~~~~~~~~~~\\
\hline
4&~~~~~~~~~~~&~~~~~~~~~~~~~~~~~\\
\hline
3&~~~~~~~~~~~&~~~~~~~~~~~~~~~~~\\
\hline
2&~~~~~~~~~~~&~~~~~~~~~~~~~~~~~\\
\hline
1&~~~~~~~~~~~&~~~~~~~~~~~~~~~~~\\
\hline
\end{tabular}}
\newcommand{\ledgroupbottomcommon}[1]{%
\begin{tabular}{|l|p{1in}|p{2in}|}
\hline
\multicolumn{3}{|c|}{#1}\\
\hline
TL&Cable/Color&Function\\
\hline
1&~~~~~~~~~~~&~~~~~~~~~~~~~~~~~\\
\hline
2&~~~~~~~~~~~&~~~~~~~~~~~~~~~~~\\
\hline
3&~~~~~~~~~~~&~~~~~~~~~~~~~~~~~\\
\hline
4&~~~~~~~~~~~&~~~~~~~~~~~~~~~~~\\
\hline
5&~~~~~~~~~~~&~~~~~~~~~~~~~~~~~\\
\hline
6&~~~~~~~~~~~&~~~~~~~~~~~~~~~~~\\
\hline
7&~~~~~~~~~~~&~~~~~~~~~~~~~~~~~\\
\hline
8&~~~~~~~~~~~&~~~~~~~~~~~~~~~~~\\
\hline
C&~~~~~~~~~~~&~~~~~~~~~~~~~~~~~\\
\hline
\end{tabular}}
\newcommand{\inputterms}[1]{%
\begin{tabular}{|l|p{1in}|p{2in}|}
\hline
\multicolumn{3}{|c|}{#1}\\
\hline
TL&Cable/Color&Function\\
\hline                                                                 
8A&~~~~~~~~~~~&~~~~~~~~~~~~~~~~~\\
\hline
8B&~~~~~~~~~~~&~~~~~~~~~~~~~~~~~\\
\hline
7A&~~~~~~~~~~~&~~~~~~~~~~~~~~~~~\\
\hline
7B&~~~~~~~~~~~&~~~~~~~~~~~~~~~~~\\
\hline
6&~~~~~~~~~~~&~~~~~~~~~~~~~~~~~\\
\hline
5&~~~~~~~~~~~&~~~~~~~~~~~~~~~~~\\
\hline
GND&~~~~~~~~~~~&~~~~~~~~~~~~~~~~~\\
\hline
\end{tabular}}
\parskip=15pt
\parindent=0pt
\begin{document}
%\maketitle

\section{Left side, top to bottom}

%%\ledgrouptopcommon{J3: GPIO 2}
\begin{tabular}{|l|p{1in}|p{2in}|}
\hline
\multicolumn{3}{|c|}{J3: GPIO 2: OCC, blue lanterns}\\
\hline
TL&Cable/Color&Function\\
\hline
C&Red&--------------\\
\hline
8&Orange&Blue Lanterns\\
\hline
7&Yellow&CP2 OS OCC\\
\hline
6&Green&Block3 OCC\\
\hline
5&Blue&Block 2 OCC\\
\hline
4&Violet&Block 1 OCC\\
\hline
3&Gray&CP1 OS OCC\\
\hline
2&White&Main OCC\\
\hline
1&Black&Siding OCC\\
\hline
\end{tabular}

%%\ledgrouptopcommon{J2: GPIO 1}
\begin{tabular}{|l|p{1in}|p{2in}|}
\hline
\multicolumn{3}{|c|}{J2: GPIO 1: CP2MW (Points), CP2EM (Frog Main)}\\
\hline
TL&Cable/Color&Function\\
\hline
C&Brown/Brown&-------------\\
\hline
8&Red&Lower Red (CP2MW)\\
\hline
7&Orange&Lower Yellow\\
\hline
6&Yellow&Upper Red\\
\hline
5&Green&Upper Yellow\\
\hline
4&Blue&Upper Green\\
\hline
3&Red&Red (CP2EM)\\
\hline
2&Orange&Yellow\\
\hline
1&Yellow&Green\\
\hline
\end{tabular}

%%\ledgrouptopcommon{J4: GPIO 4}
\begin{tabular}{|l|p{1in}|p{2in}|}
\hline
\multicolumn{3}{|c|}{J4: GPIO 4: CP1ME (Points), CP1MW (Frog Main)}\\
\hline
TL&Cable/Color&Function\\
\hline
C&Brown / Brown&-------------\\
\hline
8&Red&Lower Red (CP1ME)\\
\hline
7&Orange&Lower Yellow\\
\hline
6&Yellow&Upper Red\\
\hline
5&Green&Upper Yellow\\
\hline
4&Blue&Upper Green\\
\hline
3&Red&Red (CP1MW)\\
\hline
2&Orange&Yellow\\
\hline
1&Yellow&Green\\
\hline
\end{tabular}

%%\ledgrouptopcommon{J5: GPIO 3}
\begin{tabular}{|l|p{1in}|p{2in}|}
\hline
\multicolumn{3}{|c|}{J5: GPIO 3: CP1SW, CP2SE, CP1 Switch Plate}\\
\hline
TL&Cable/Color&Function\\
\hline
C&Brown / Blue / Green&------------\\
\hline
8&Red&Red CP1SW (Frog Siding)\\
\hline
7&Orange&Yellow\\
\hline
6&Yellow&Green\\
\hline
5&Green&Red CP2SE (Frog Siding)\\
\hline
4&Yellow&Yellow\\
\hline
3&Orange&Green\\
\hline
2&Violet&Green (Normal) CP1 SWP\\
\hline
1&Blue&Yellow (Reverse)\\
\hline
\end{tabular}

%\clearpage
\section{Right side, top to bottom}

%%\ledgroupbottomcommon{J8: GPIO 6}
\begin{tabular}{|l|p{1in}|p{2in}|}
\hline
\multicolumn{3}{|c|}{J8: GPIO 6: CP2 SWP, 2W, 3E}\\
\hline
TL&Cable/Color&Function\\
\hline
1&Yellow&Yellow (Reverse) CP2 SWP\\
\hline
2&Green&Green (Normal)\\
\hline
3&Green&Green 2W\\
\hline
4&Blue&Yellow\\
\hline
5&Violet&Red\\
\hline
6&Yellow&Green 3E\\
\hline
7&Orange&Yellow\\
\hline
8&Red&Red\\
\hline
C&Brown / Gray / Blue&------------\\
\hline
\end{tabular}

%%\ledgroupbottomcommon{J7: GPIO 5}
\begin{tabular}{|l|p{1in}|p{2in}|}
\hline
\multicolumn{3}{|c|}{J7: GPIO 5: 1W, 2E}\\
\hline
TL&Cable/Color&Function\\
\hline
1&White&Green 1W\\
\hline
2&Black&Yellow\\
\hline
3&Brown&Red\\
\hline
4&Blue&Green 2E\\
\hline
5&Green&Yellow\\
\hline
6&Yellow&Red\\
\hline
7&NC&~~~~~~~~~~~~~~~~~\\
\hline
8&NC&~~~~~~~~~~~~~~~~~\\
\hline
C&Orange / Red&------------\\
\hline
\end{tabular}

%%\inputterms{J9: GPIO 7}
\begin{tabular}{|l|p{1in}|p{2in}|}
\hline
\multicolumn{3}{|c|}{J9: GPIO 7: CP1 SWP, CP2 SWP, CP1 Code, CP2 Code}\\
\hline
TL&Cable/Color&Function\\
\hline                                                                 
8A&Orange&Normal CP1 SWP\\
\hline
8B&Red&Reverse\\
\hline
7A&Brown&Normal CP2 SWP\\
\hline
7B&Red&Reverse\\
\hline
6&Yellow&Code CP1\\
\hline
5&Orange&Code CP2\\
\hline
GND&Brown / Black&-----------\\
\hline
\end{tabular}

\end{document}

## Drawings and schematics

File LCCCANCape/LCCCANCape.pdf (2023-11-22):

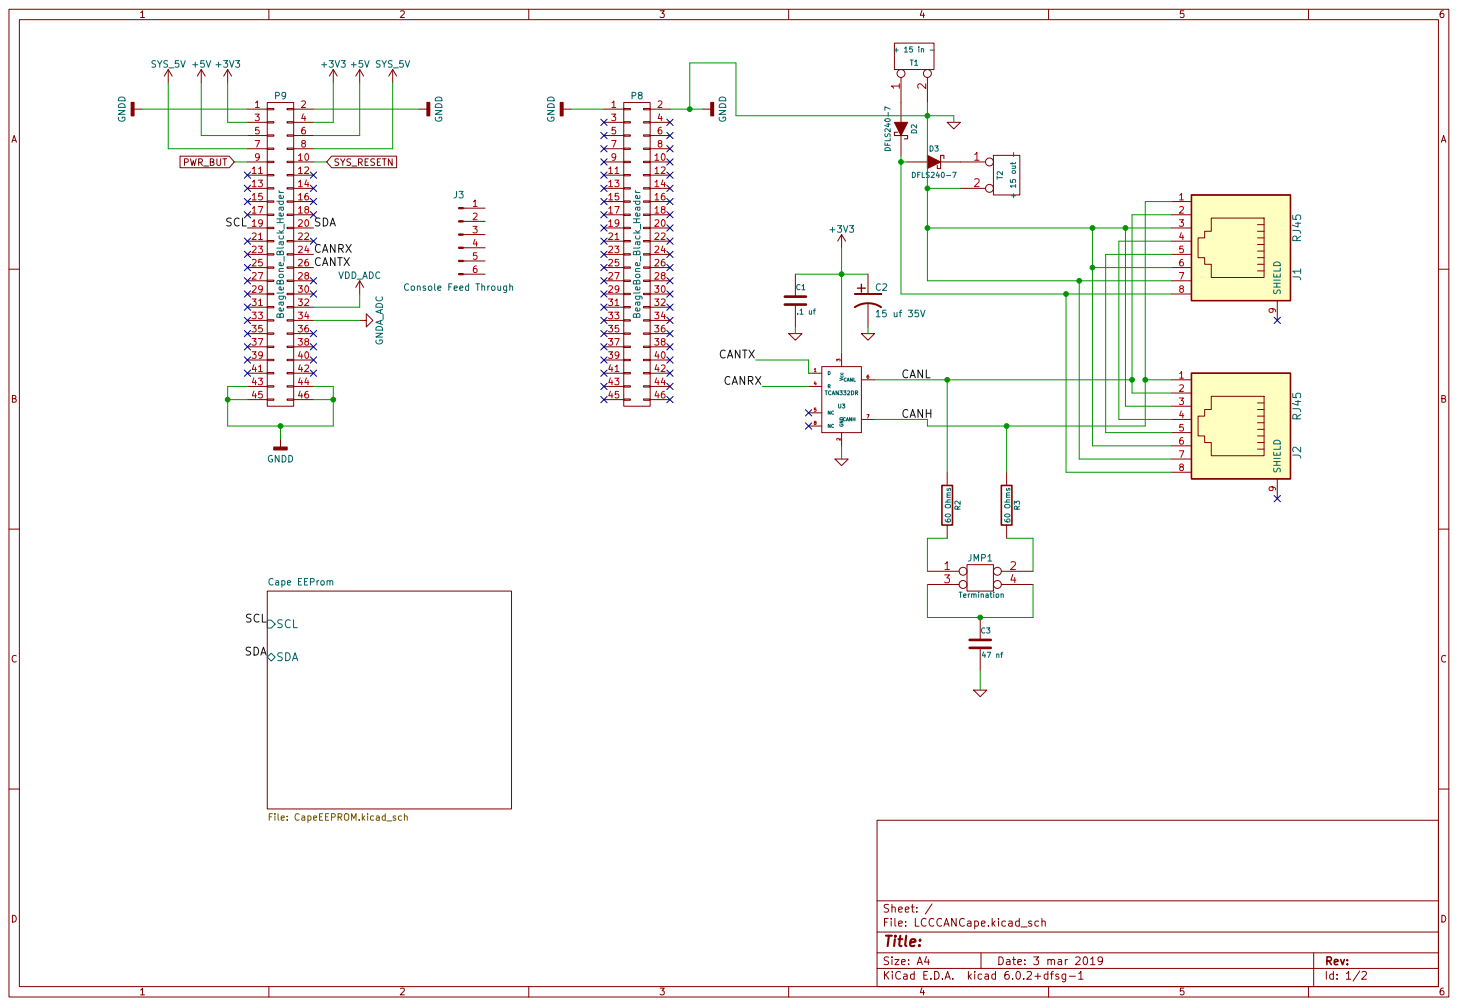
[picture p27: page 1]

SCL
File: LCCCANCape.kicad_sch Sheet: / SCL

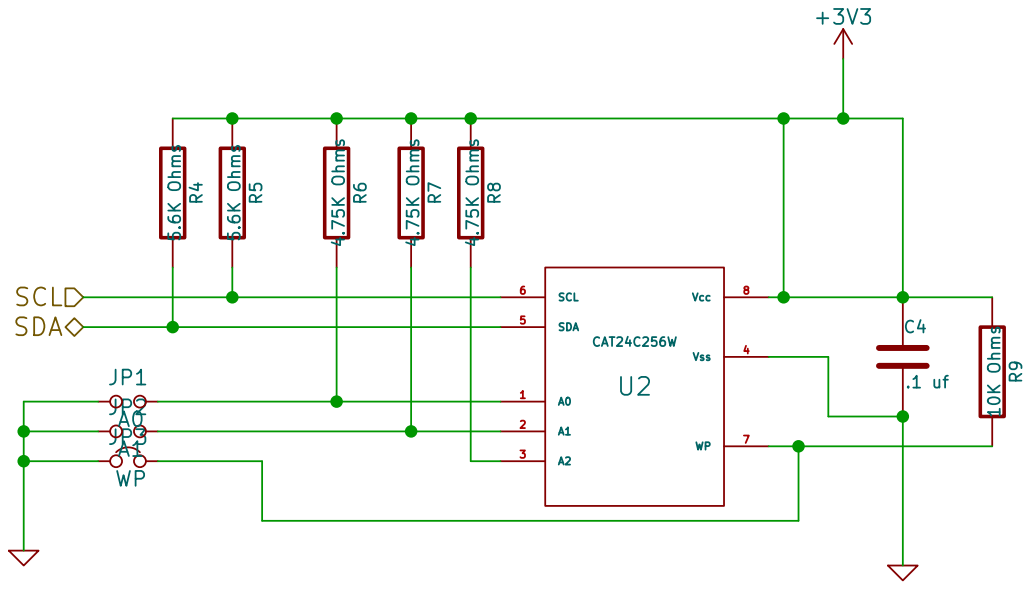
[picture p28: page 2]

Sheet: /Cape EEProm/ R4 5.6K Ohms

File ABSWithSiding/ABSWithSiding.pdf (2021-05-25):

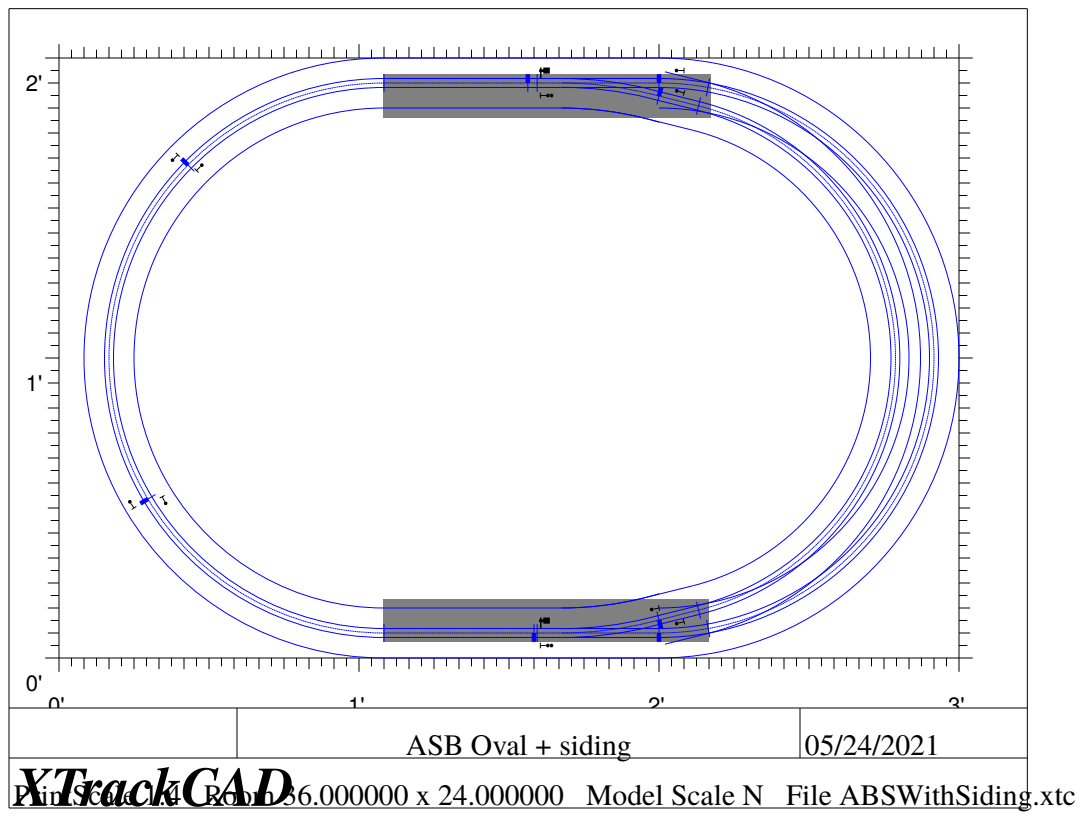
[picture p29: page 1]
ASB Oval + siding

XTrackCAD
PrintScale 1:4 Room 36.000000 x 24.000000 Model Scale N File ABSWithSiding.xtc

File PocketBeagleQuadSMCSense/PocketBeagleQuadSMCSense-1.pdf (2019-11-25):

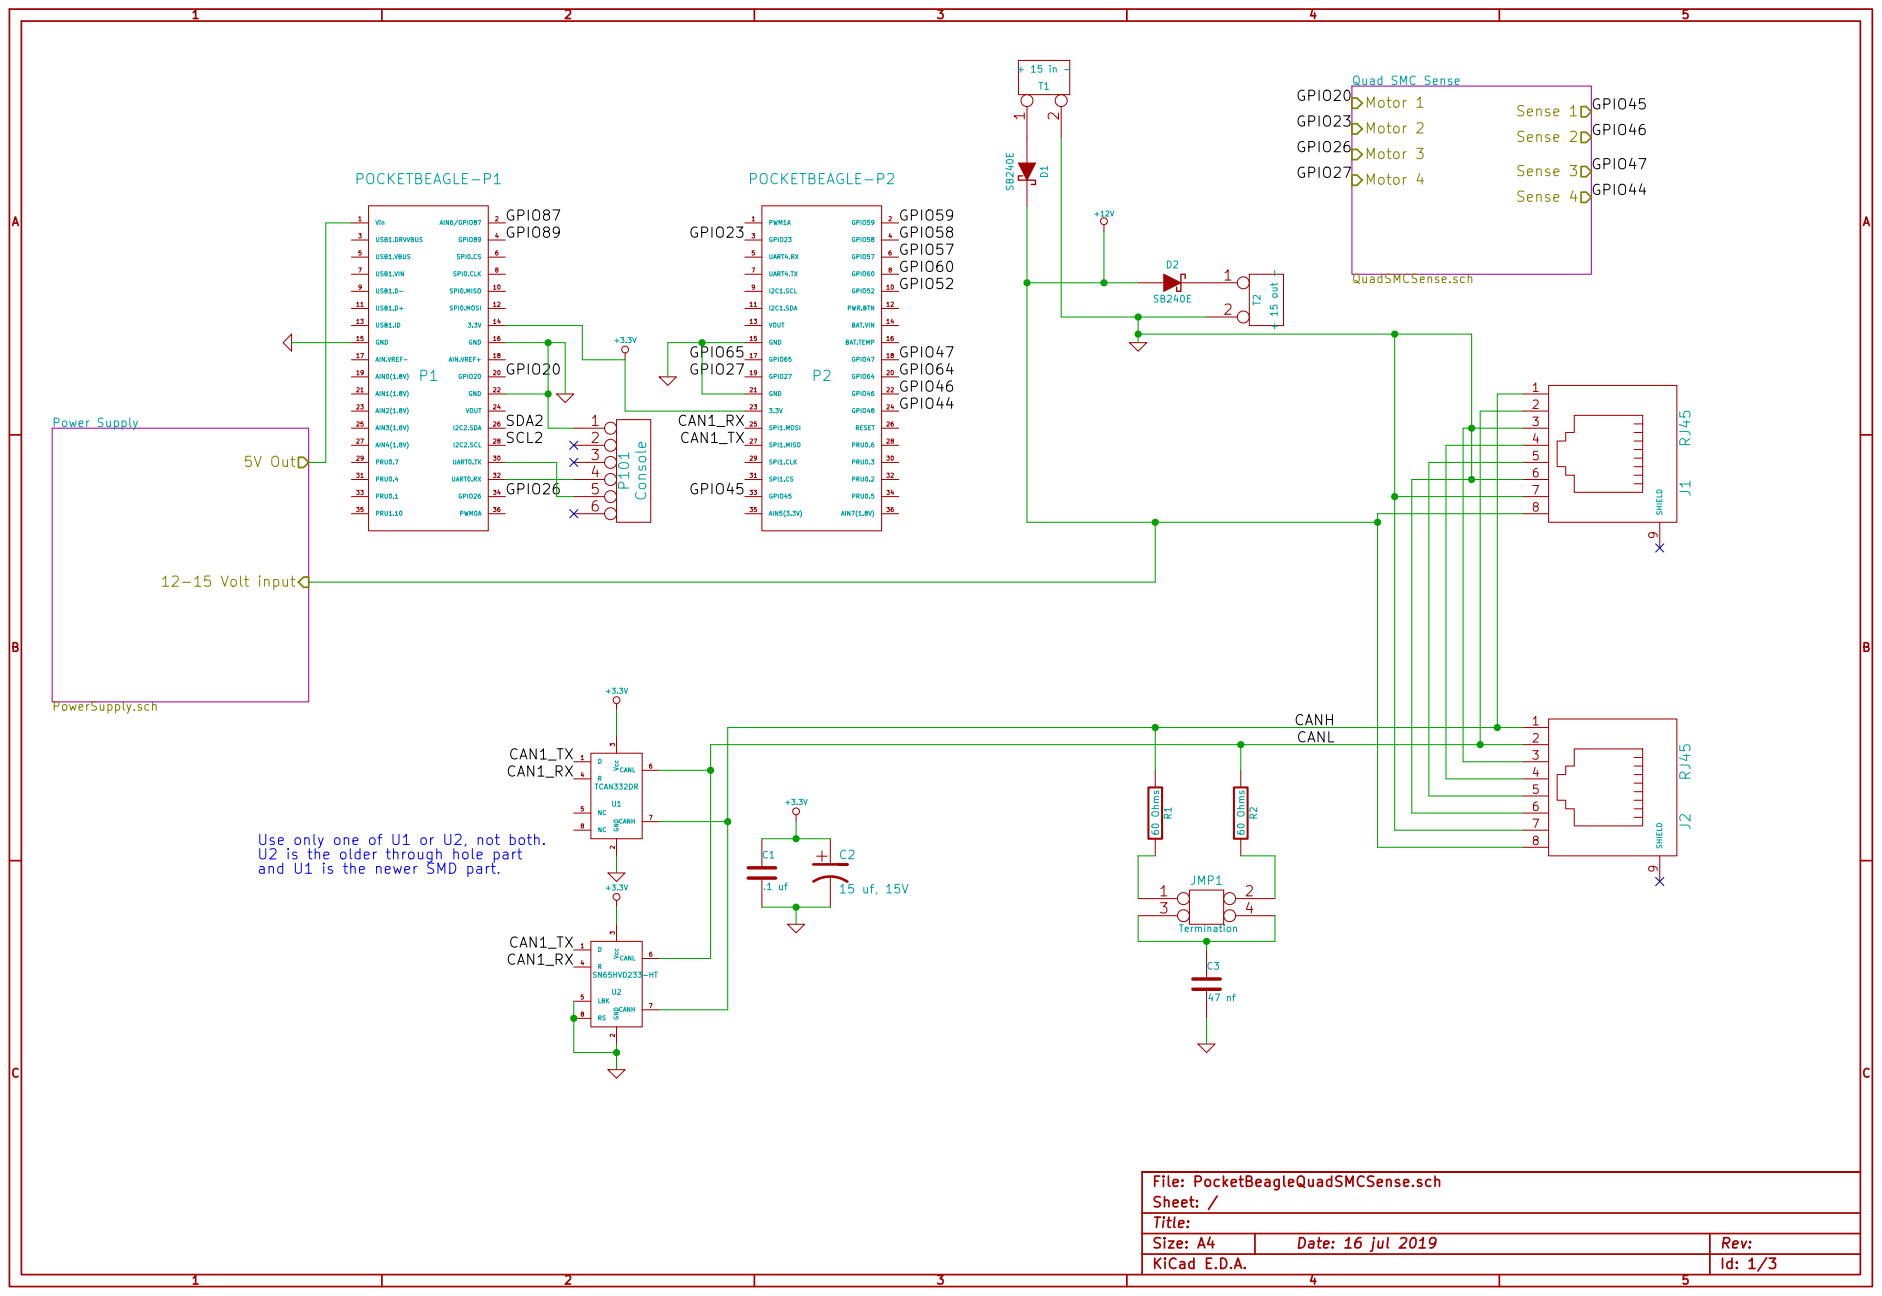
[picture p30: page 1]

CANL | 2

47 nf Use only one of U1 or U2, not both.
U2 is the older through hole part
and U1 is the newer SMD part.

Id: 1/3 Title: File: PocketBeagleQuadSMCSense.sch
Sheet: /

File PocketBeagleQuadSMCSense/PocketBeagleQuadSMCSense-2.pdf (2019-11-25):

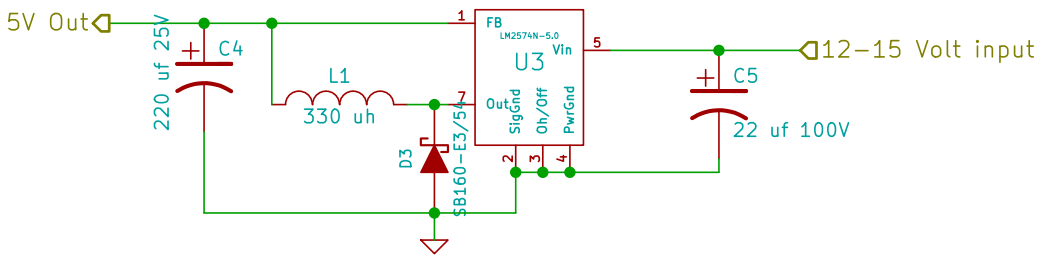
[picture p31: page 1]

Id: 2/3 Title: File: PowerSupply.sch
Sheet: /Power Supply/

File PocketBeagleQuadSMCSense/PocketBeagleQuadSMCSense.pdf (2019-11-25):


CANL | 2

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

Id: 1/3 Title: File: PocketBeagleQuadSMCSense.sch
Sheet: /


Id: 2/3 Title: File: PowerSupply.sch
Sheet: /Power Supply/

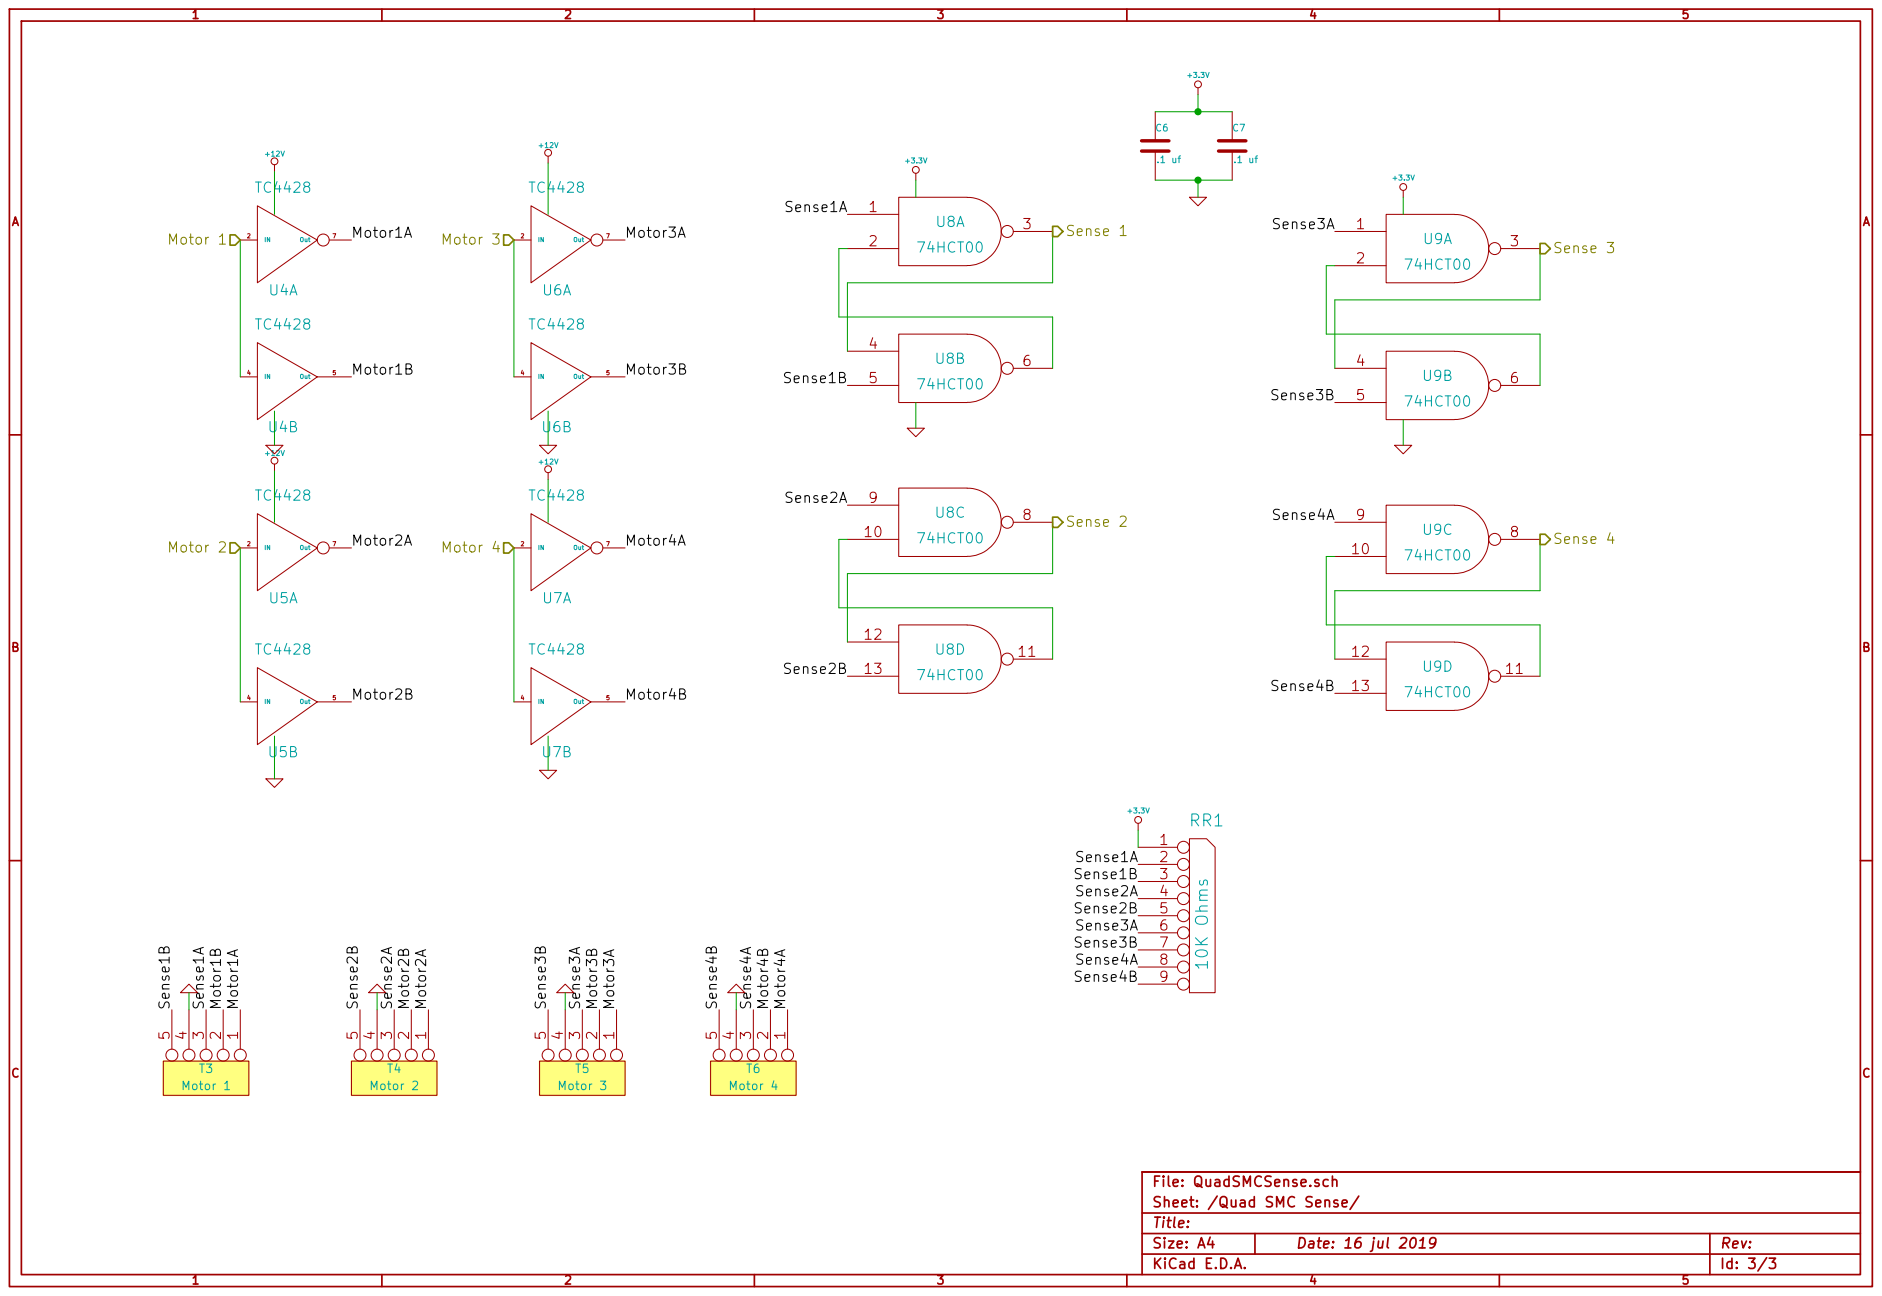
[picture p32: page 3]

Id: 3/3 Title: File: QuadSMCSense.sch
Sheet: /Quad SMC Sense/

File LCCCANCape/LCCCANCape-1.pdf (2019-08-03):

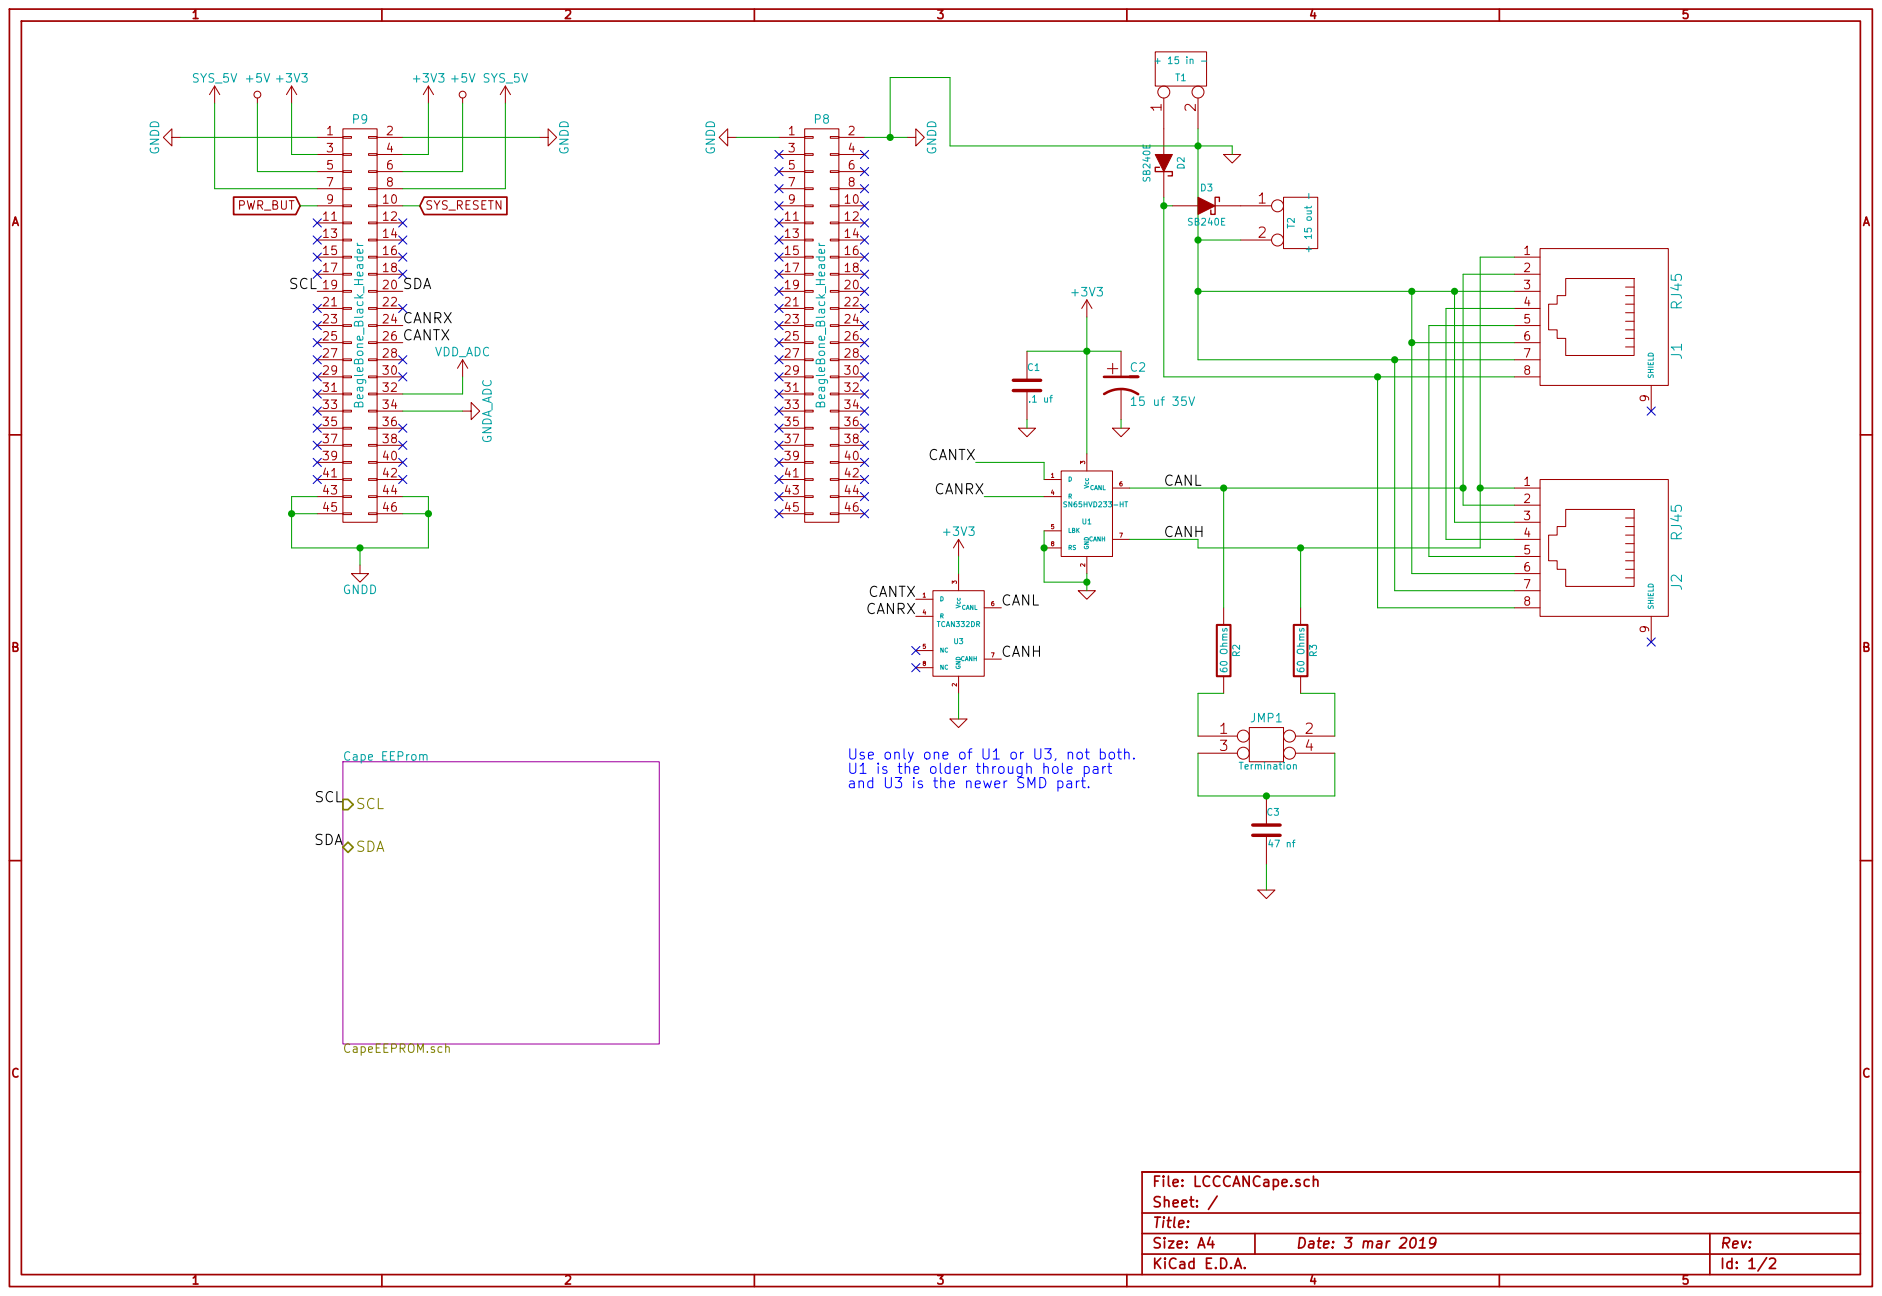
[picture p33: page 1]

Use only one of U1 or U3, not both.
U1 is the older through hole part
and U3 is the newer SMD part.

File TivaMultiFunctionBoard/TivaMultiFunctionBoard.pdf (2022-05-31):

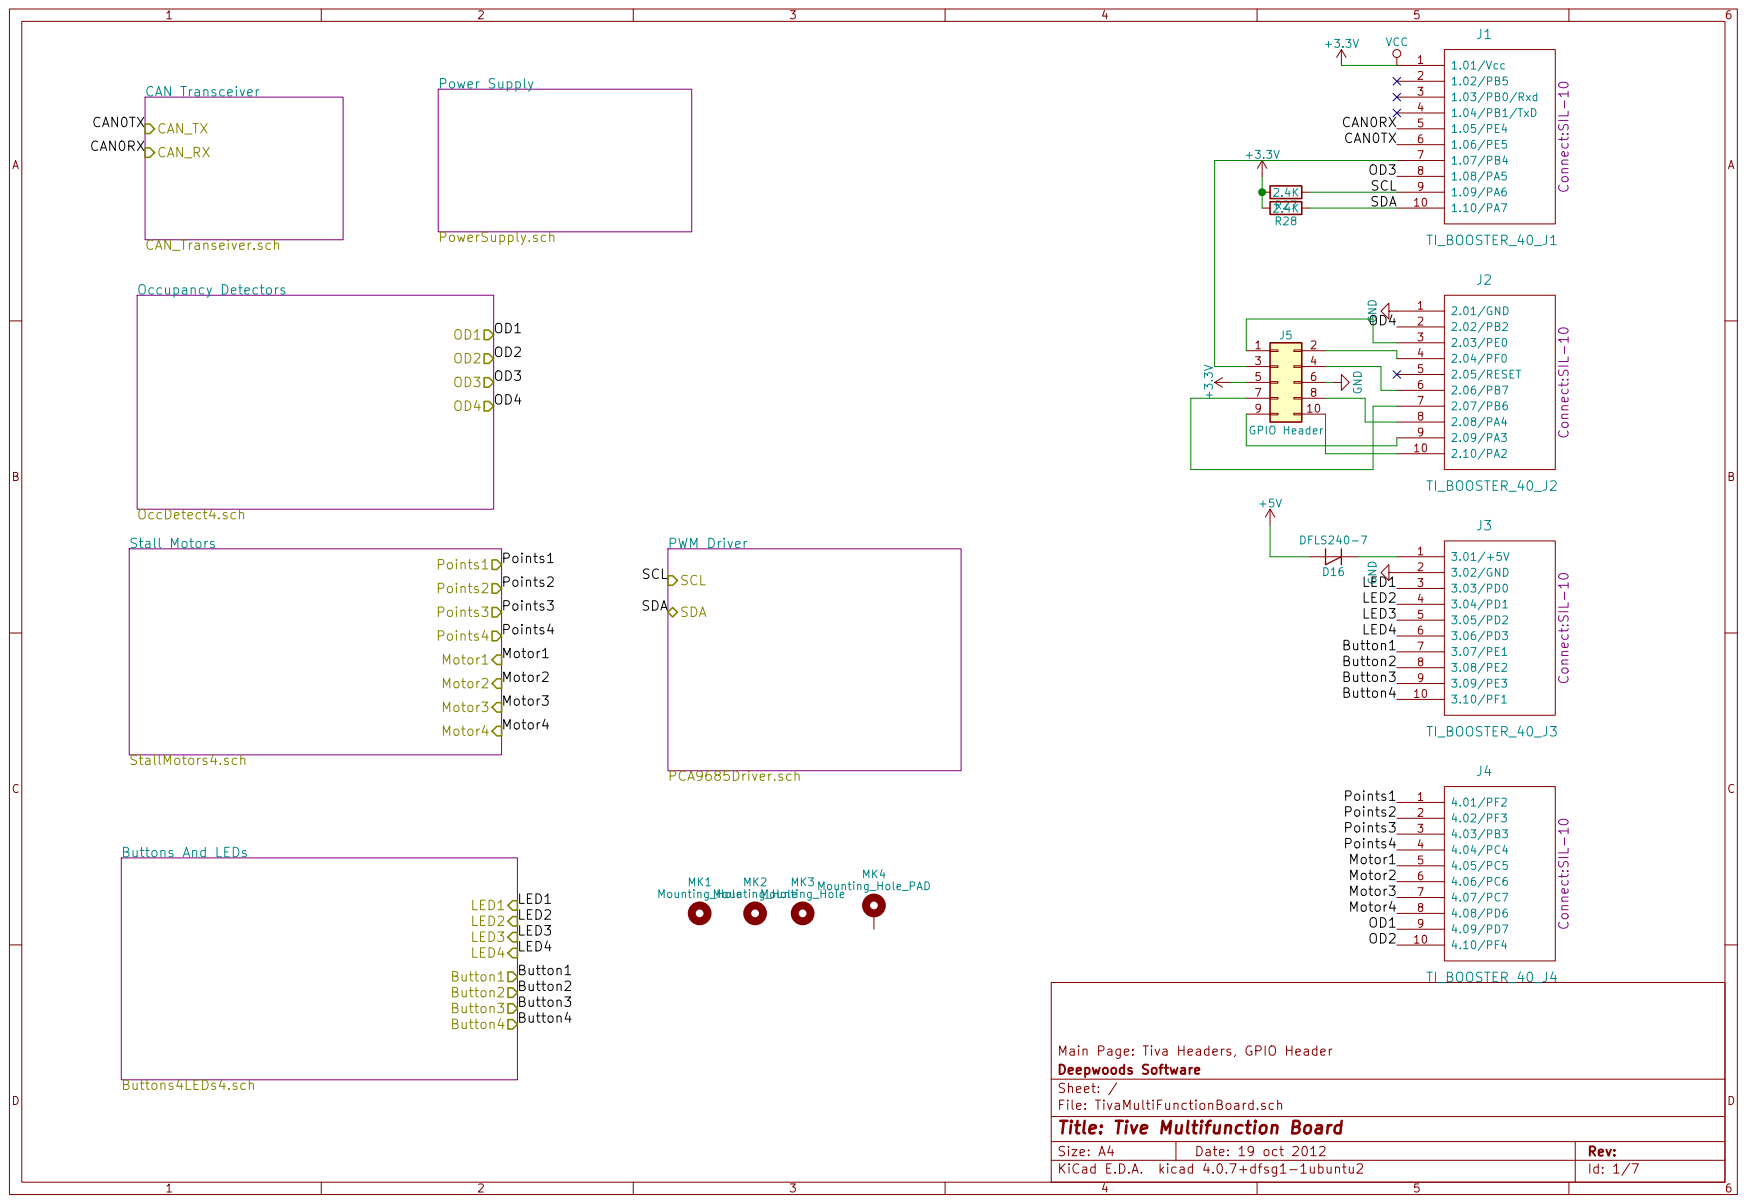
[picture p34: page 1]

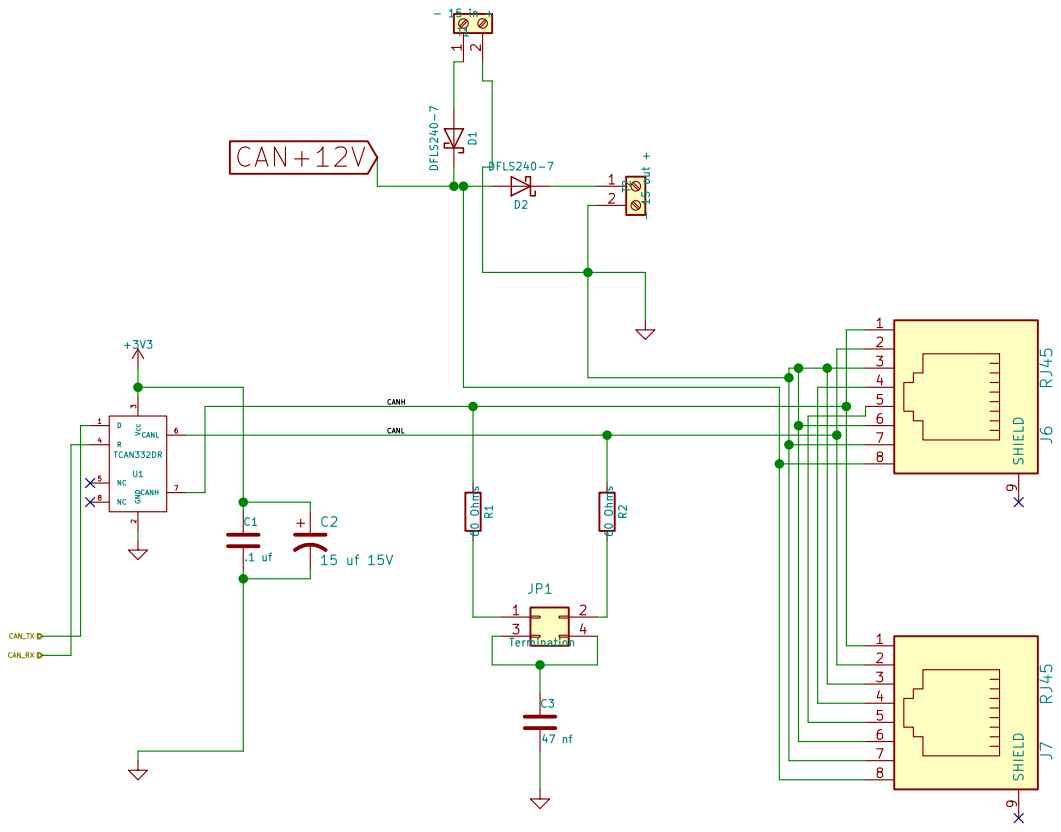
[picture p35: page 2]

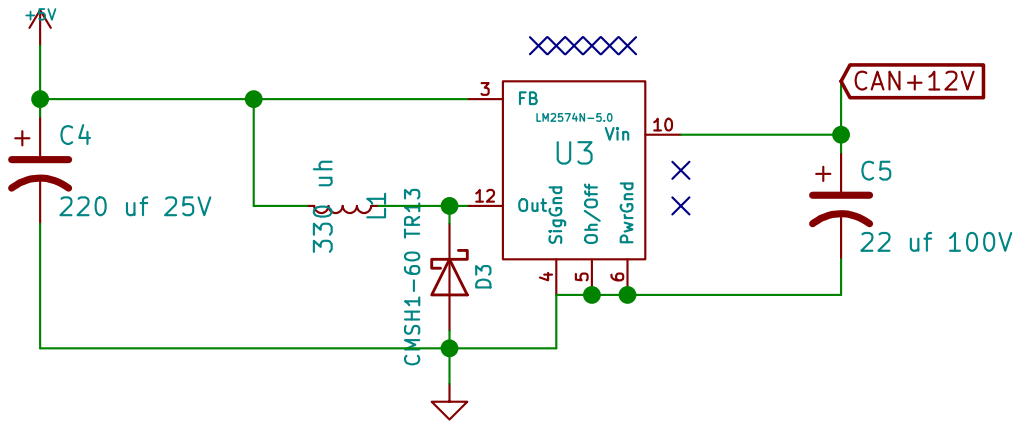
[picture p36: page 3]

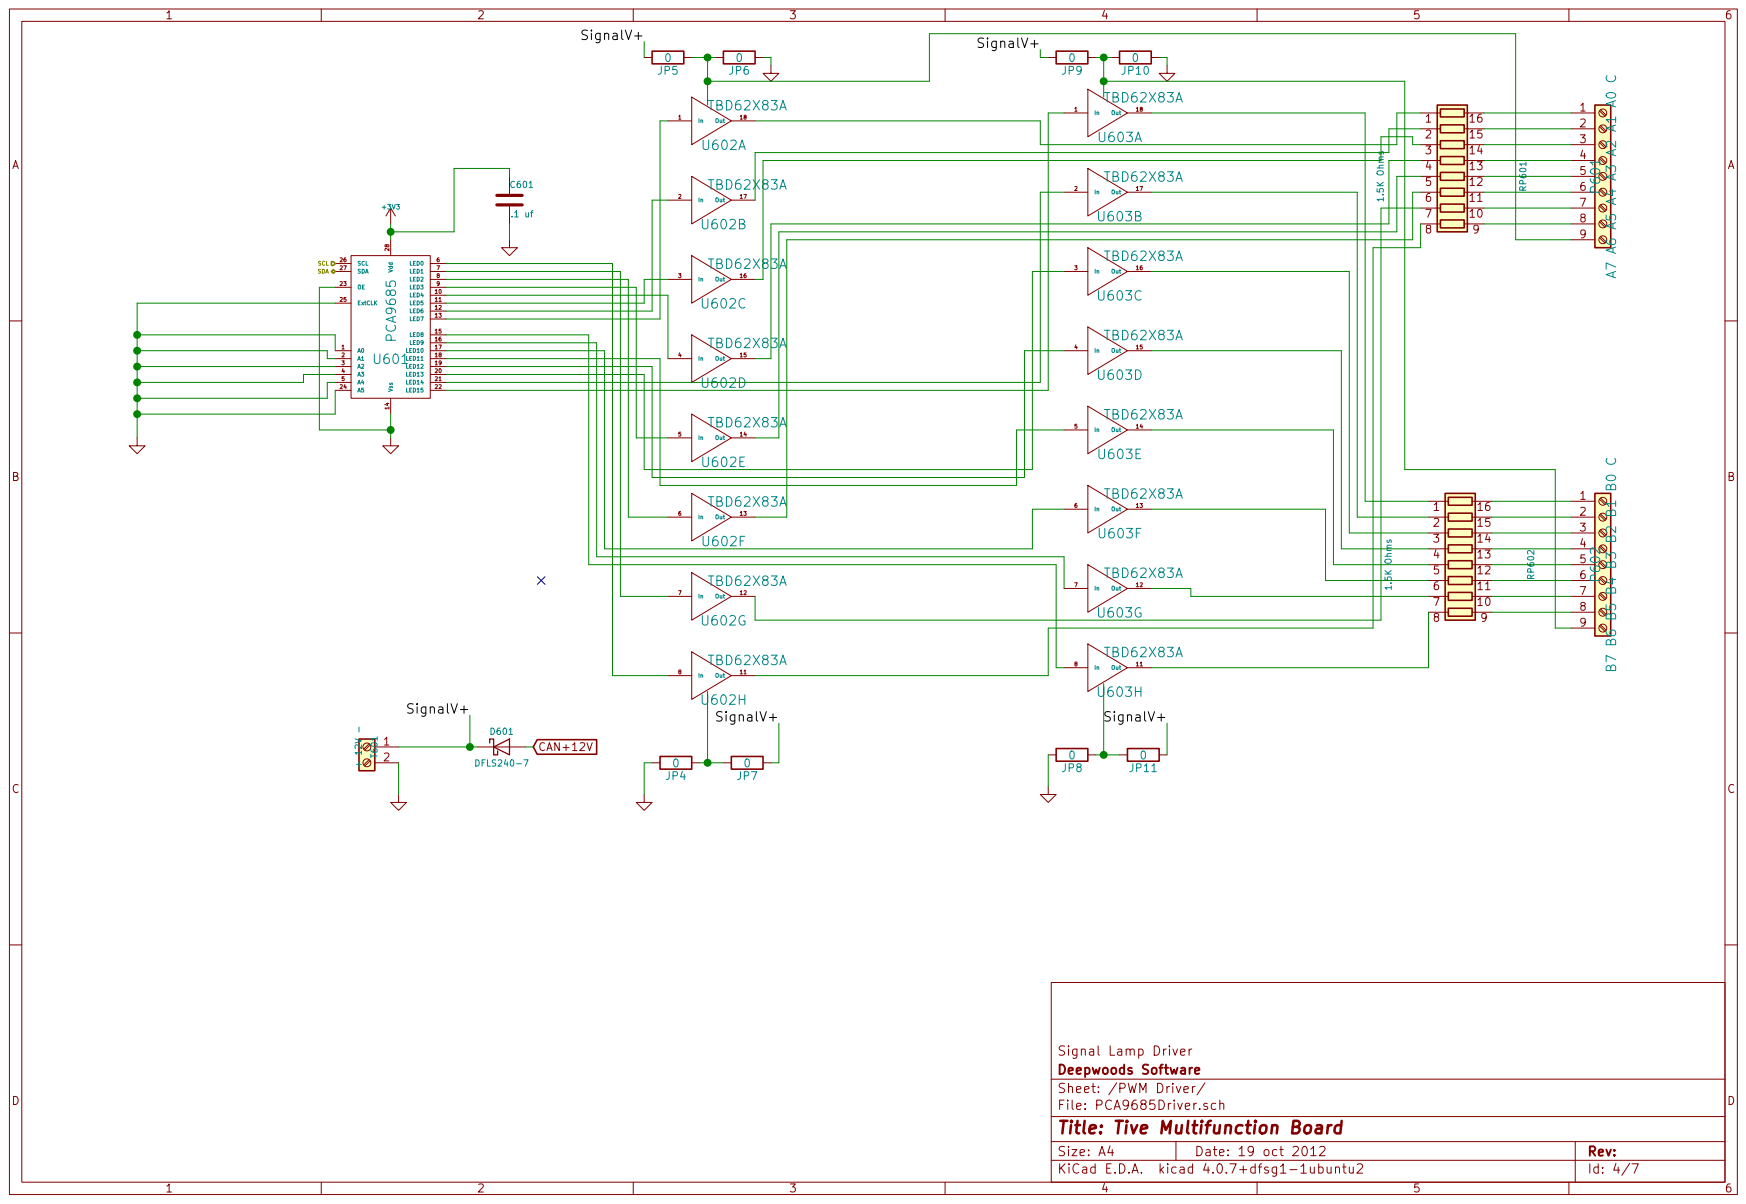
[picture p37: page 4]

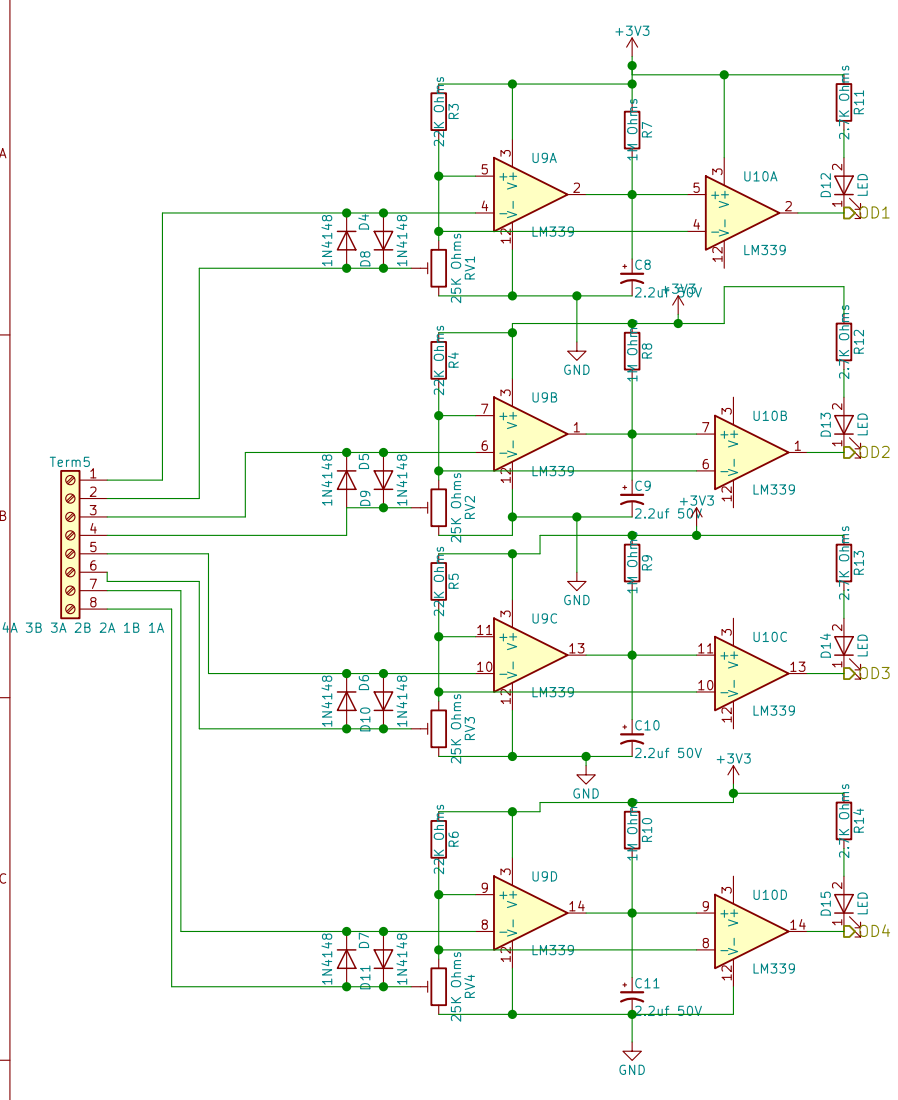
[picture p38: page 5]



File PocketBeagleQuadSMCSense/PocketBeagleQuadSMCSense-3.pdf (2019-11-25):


Id: 3/3 Title: File: QuadSMCSense.sch
Sheet: /Quad SMC Sense/





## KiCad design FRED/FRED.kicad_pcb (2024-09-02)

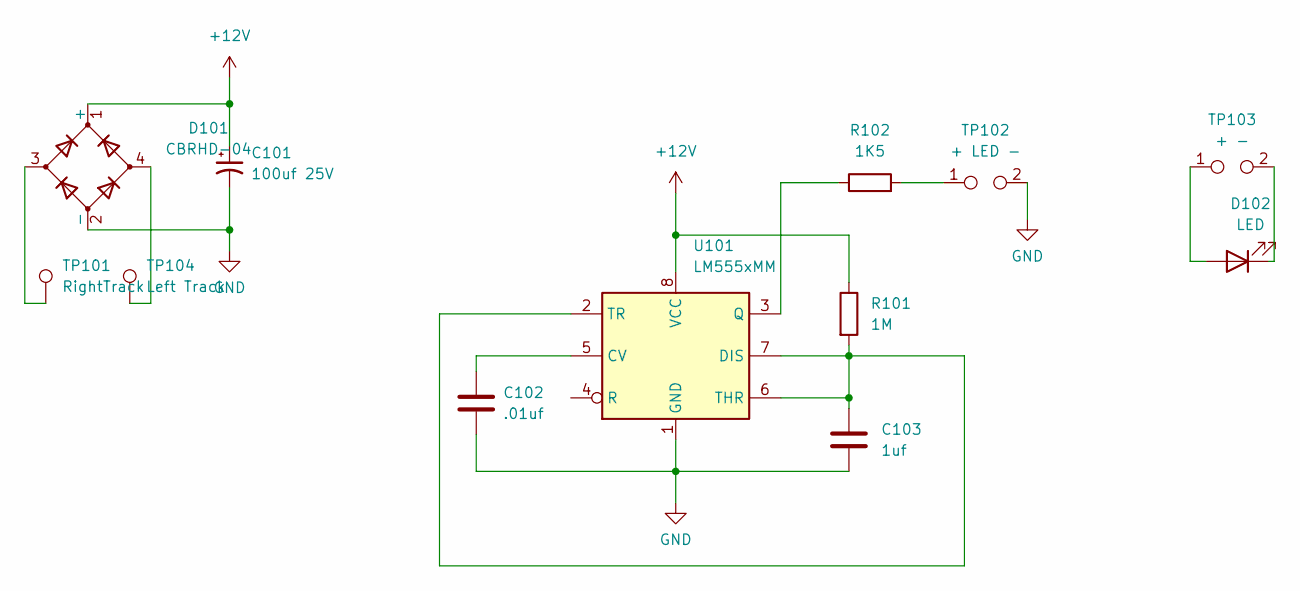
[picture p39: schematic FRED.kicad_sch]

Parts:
C101: 100uf 25V; CP_EIA-7361-438_AVX-U; Mouser Part Number 581-TRJU107K025RRJV
C102: .01uf; C_0402_1005Metric; Mouser Part Number 603-CC402JRX7R8BB103
C103: 1uf; C_0402_1005Metric; Mouser Part Number 603-CC402KRX5R6BB105
D101: CBRHD-04; SOP250P700X290-4N; Mouser Part Number 610-CBRHD04-PB
D102: LED; LED_0201_0603Metric; Mouser Part Number 743-IN-S21AT5R
R101: 1M; R_0402_1005Metric; Mouser Part Number 652-CR0402FX-1003GLF
R102: 1K5; R_0402_1005Metric; Mouser Part Number 652-CR0402FX-1501GLF
TP101: RightTrack; Track Pickup Pad
TP102: + LED -; SolderWire-0.1sqmm_1x02_P3.6mm_D0.4mm_OD1mm
TP103: + -; SolderPads_1x2_1.2mm
TP104: Left Track; Track Pickup Pad
U101: LM555xMM; VSSOP-8_3.0x3.0mm_P0.65mm; Mouser Part Number 926-LM555CMMX/NOPB

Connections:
+12V: C101.1, D101.1 (+), R101.1, U101.8 (VCC)
GND: C101.2, C102.2, C103.2, D101.2 (-), TP102.2, U101.1 (GND)
unnamed: C102.1, U101.5 (CV)
unnamed: C103.1, R101.2, U101.2 (TR), U101.6 (THR), U101.7 (DIS)
unnamed: D101.3, TP101.1
unnamed: D101.4, TP104.1
unnamed: D102.1 (K), TP103.2
unnamed: D102.2 (A), TP103.1
unnamed: R102.1, U101.3 (Q)
unnamed: R102.2, TP102.1

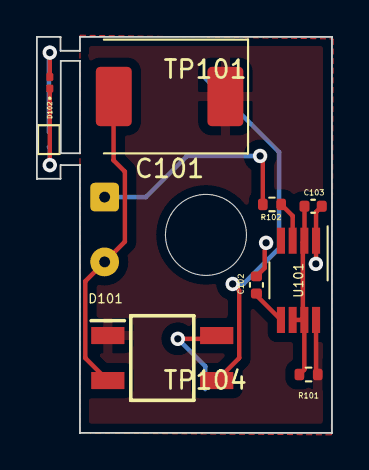
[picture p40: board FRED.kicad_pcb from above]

Board: 2 copper layers, 16.4 x 22.0 mm, 12 parts (0 on the bottom side), 10 nets.

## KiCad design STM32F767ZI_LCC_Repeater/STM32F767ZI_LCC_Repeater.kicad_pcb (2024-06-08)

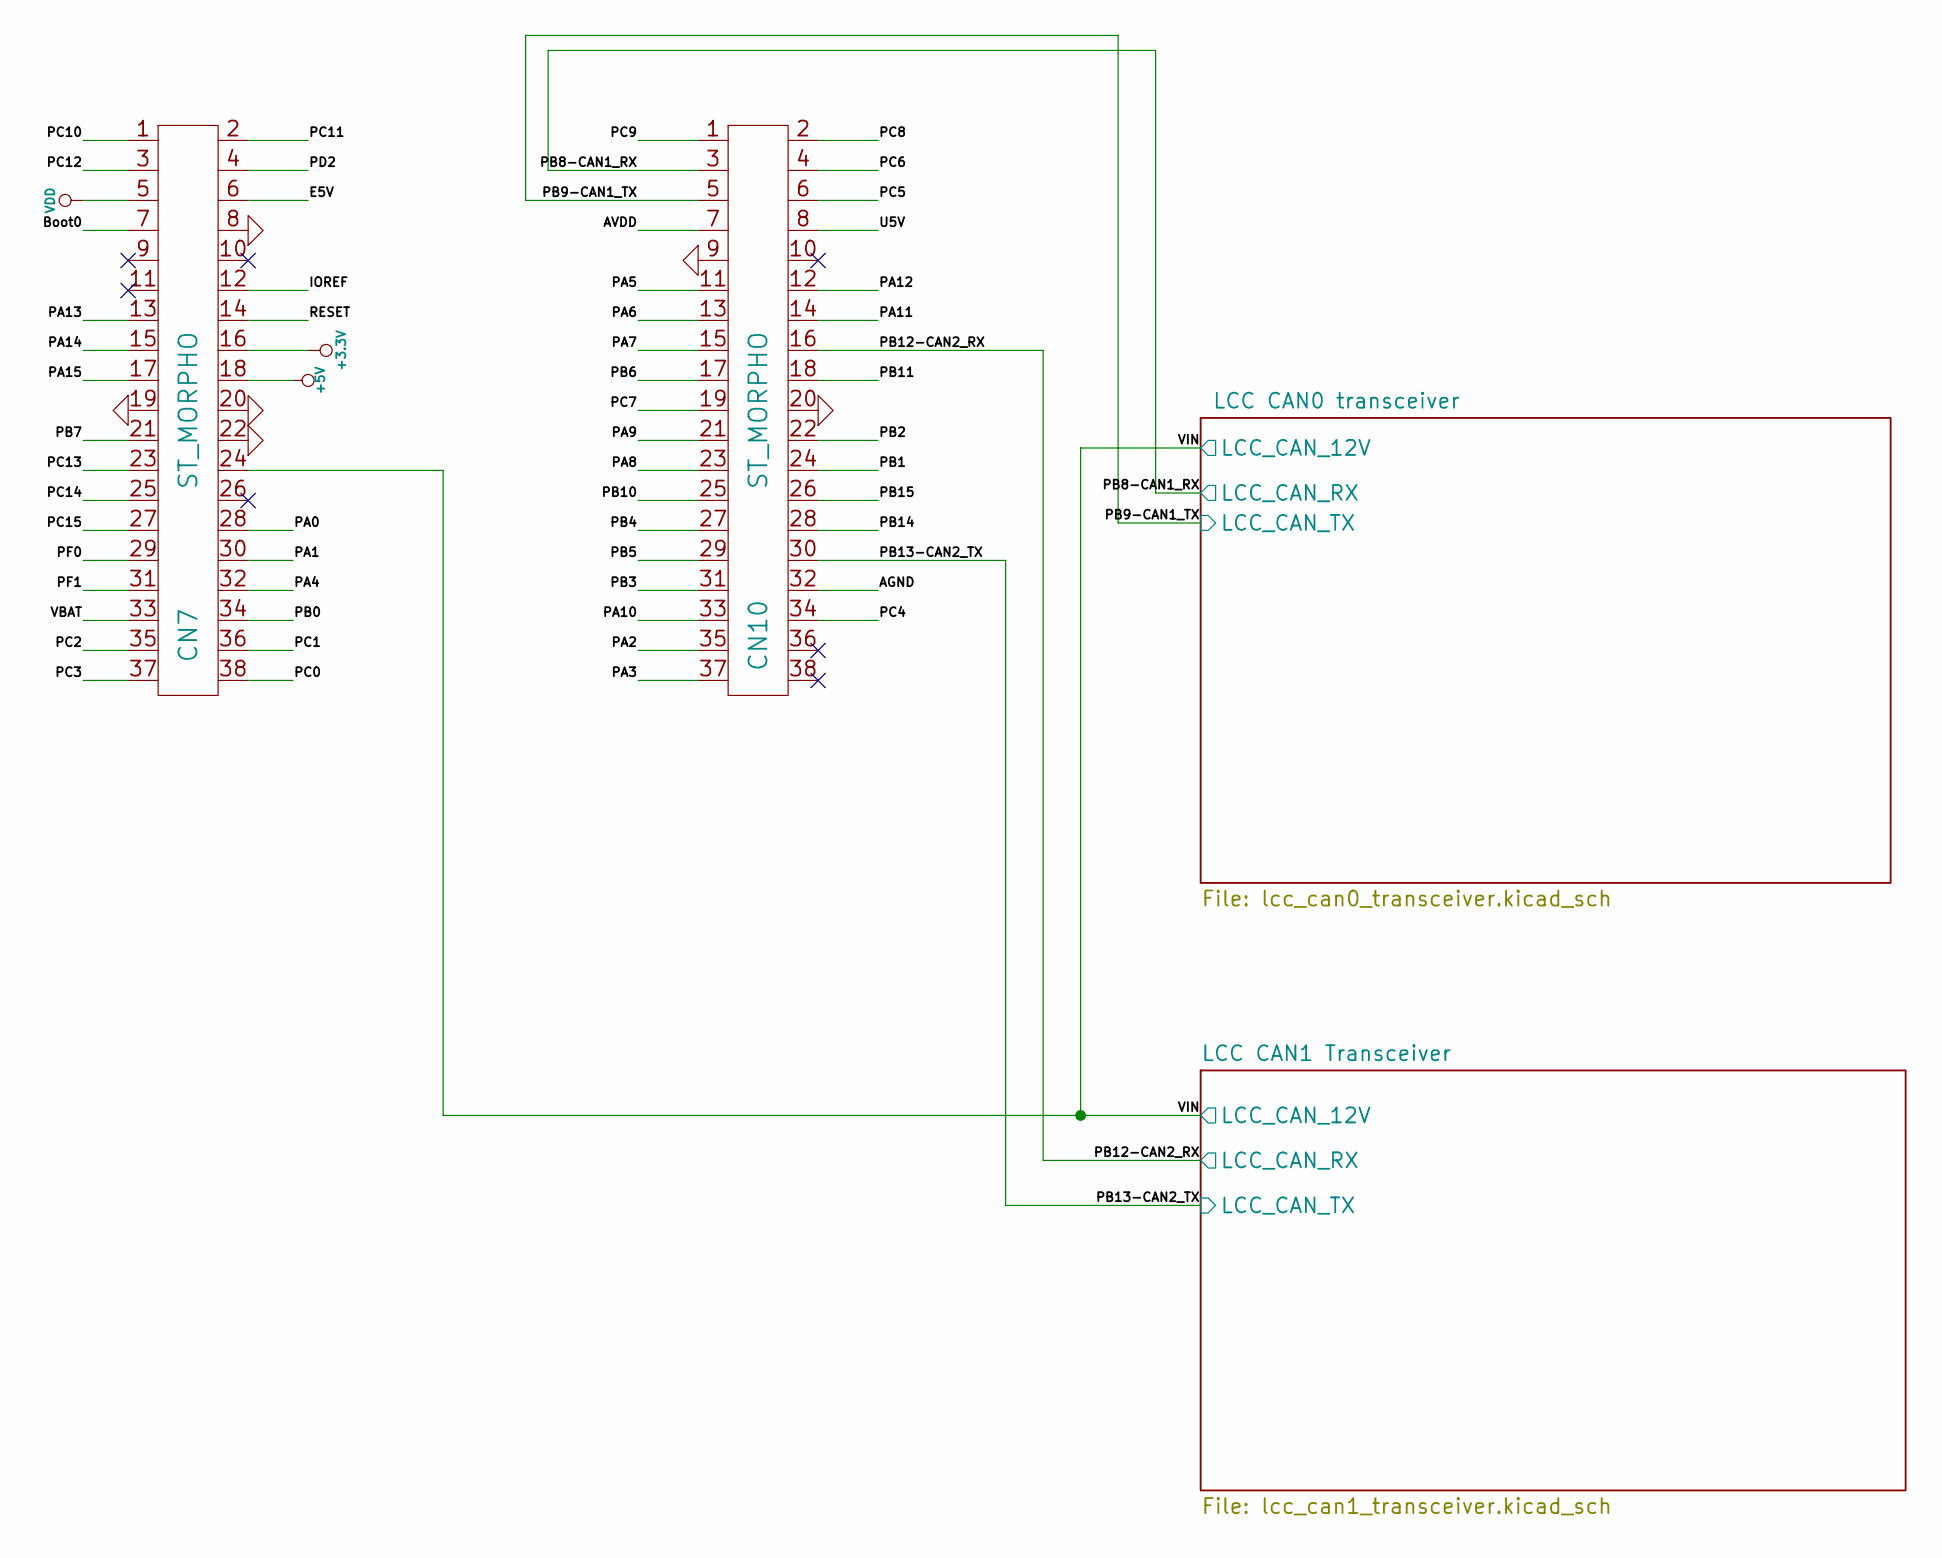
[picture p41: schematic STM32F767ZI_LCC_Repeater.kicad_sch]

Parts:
CN7, CN10: ST_MORPHO; ST_Morpho

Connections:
+3.3V: CN7.16; also elsewhere on the board
+5V: CN7.18
/AGND: CN10.32
/AVDD: CN10.7
/Boot0: CN7.7
/E5V: CN7.6
/IOREF: CN7.12
/PA0: CN7.28
/PA1: CN7.30
/PA2: CN10.35
/PA3: CN10.37
/PA4: CN7.32
/PA5: CN10.11
/PA6: CN10.13
/PA7: CN10.15
/PA8: CN10.23
/PA9: CN10.21
/PA10: CN10.33
/PA11: CN10.14
/PA12: CN10.12
/PA13: CN7.13
/PA14: CN7.15
/PA15: CN7.17
/PB0: CN7.34
/PB1: CN10.24
/PB2: CN10.22
/PB3: CN10.31
/PB4: CN10.27
/PB5: CN10.29
/PB6: CN10.17
/PB7: CN7.21
/PB8-CAN1_RX: CN10.3; also elsewhere on the board
/PB9-CAN1_TX: CN10.5; also elsewhere on the board
/PB10: CN10.25
/PB11: CN10.18
/PB12-CAN2_RX: CN10.16; also elsewhere on the board
/PB13-CAN2_TX: CN10.30; also elsewhere on the board
/PB14: CN10.28
/PB15: CN10.26
/PC0: CN7.38
/PC1: CN7.36
/PC2: CN7.35
/PC3: CN7.37
/PC4: CN10.34
/PC5: CN10.6
/PC6: CN10.4
/PC7: CN10.19
/PC8: CN10.2
/PC9: CN10.1
/PC10: CN7.1
/PC11: CN7.2
/PC12: CN7.3
/PC13: CN7.23
/PC14: CN7.25
/PC15: CN7.27
/PD2: CN7.4
/PF0: CN7.29
/PF1: CN7.31
/RESET: CN7.14
/U5V: CN10.8
/VBAT: CN7.33
/VIN: CN7.24; also elsewhere on the board
GND: CN7.8, CN7.19, CN7.20, CN7.22, CN10.9, CN10.20; also elsewhere on the board
VDD: CN7.5

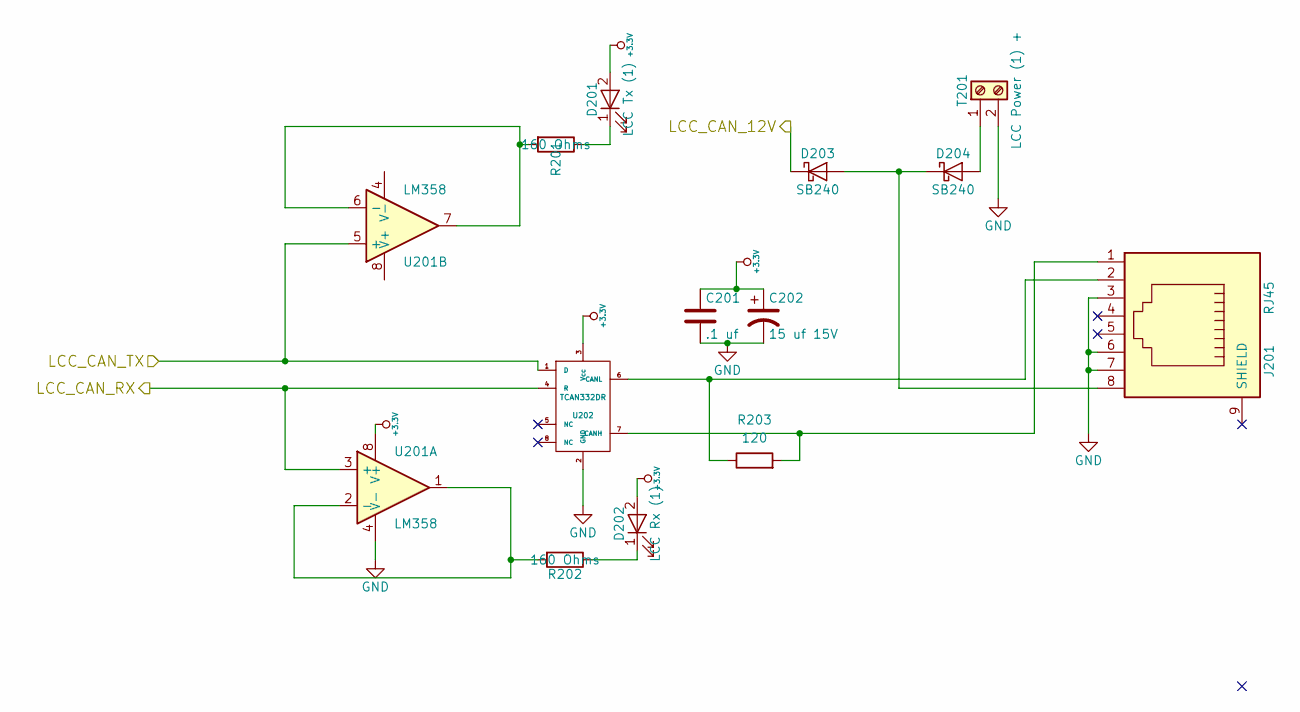
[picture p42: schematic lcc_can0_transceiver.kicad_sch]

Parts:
C201: .1 uf; C_0603_1608Metric; Mouser Part Number 603-CC603KPX7R9BB104
C202: 15 uf 15V; CP_Elec_4x5.8; Mouser Part Number 647-UUD1C150MCL
D201: LCC Tx (1); LED_0603_1608Metric; Mouser Part Number 710-150060SS75000
D202: LCC Rx (1); LED_0603_1608Metric; Mouser Part Number 710-150060YS75000
D203, D204: SB240; D_PowerDI-123; Mouser Part Number 621-DFLS240-7
J201: RJ45; RJ45_8N-S; Mouser Part Number 710-615008144221
R201, R202: 160 Ohms; R_0603_1608Metric; Mouser Part Number 603-AC0603JR-07160RL
R203: 120; R_0603_1608Metric; Mouser Part Number 603-RT0603DRE07120RL
T201: LCC Power (1) +; TerminalBlock_TE_282834-2_1x02_P2.54mm_Horizontal; Mouser Part Number 651-1725656
U201: LM358; SOIC-8_3.9x4.9mm_P1.27mm; Mouser Part Number 595-LM358DR
U202: TCAN332DR; SOIC-8_3.9x4.9mm_P1.27mm; Mouser Part Number 595-TCAN332DR

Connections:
+3.3V: C201.1, C202.1, D201.2 (A), D202.2 (A), U201.8 (V+), U202.3 (Vcc); also elsewhere on the board
/PB8-CAN1_RX: U201.3 (+), U202.4 (R); also elsewhere on the board
/PB9-CAN1_TX: U201.5 (+), U202.1 (D); also elsewhere on the board
/VIN: D203.1 (K); also elsewhere on the board
GND: C201.2, C202.2, J201.3, J201.6, J201.7, T201.2, U201.4 (V-), U202.2 (GND); also elsewhere on the board
unnamed: D201.1 (K), R201.1
unnamed: D202.1 (K), R202.1
unnamed: D203.2 (A), D204.1 (K), J201.8
unnamed: D204.2 (A), T201.1
unnamed: J201.1, R203.2, U202.7 (CANH)
unnamed: J201.2, R203.1, U202.6 (CANL)
unnamed: R201.2, U201.6 (-), U201.7
unnamed: R202.2, U201.1, U201.2 (-)

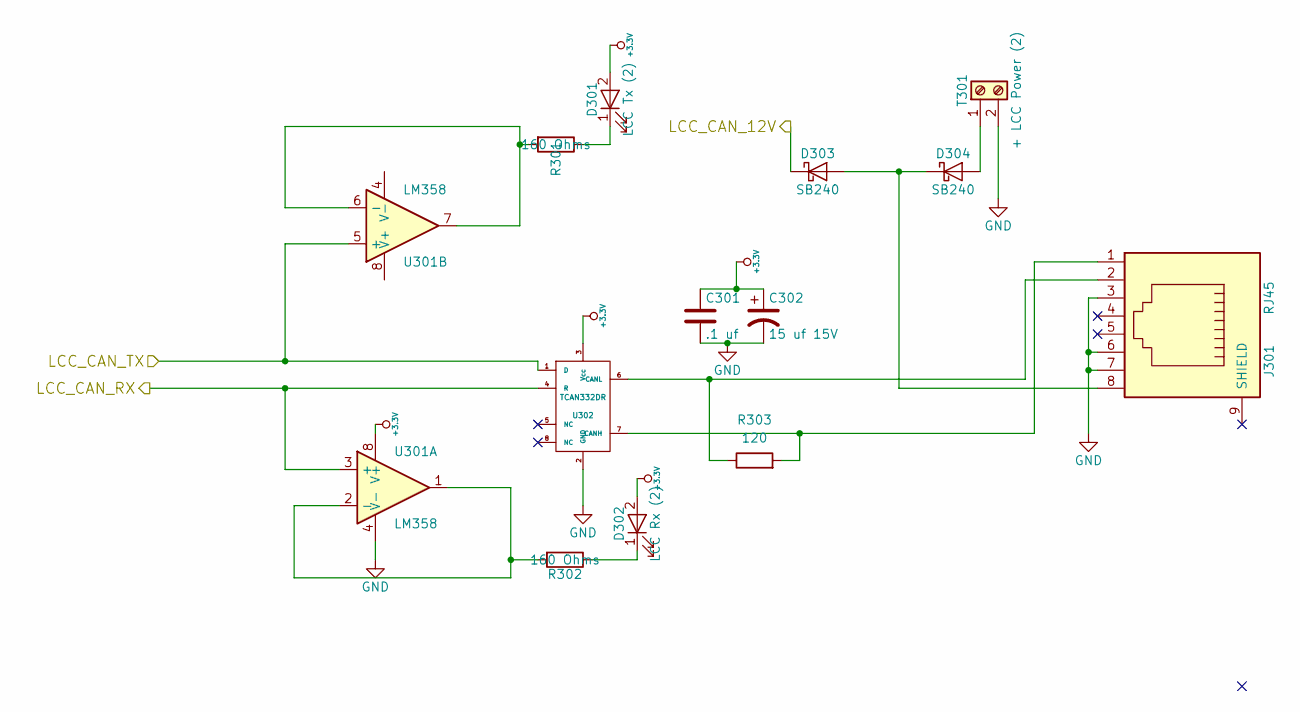
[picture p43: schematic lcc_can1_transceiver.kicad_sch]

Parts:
C301: .1 uf; C_0603_1608Metric; Mouser Part Number 603-CC603KPX7R9BB104
C302: 15 uf 15V; CP_Elec_4x5.8; Mouser Part Number 647-UUD1C150MCL
D301: LCC Tx (2); LED_0603_1608Metric; Mouser Part Number 710-150060SS75000
D302: LCC Rx (2); LED_0603_1608Metric; Mouser Part Number 710-150060YS75000
D303, D304: SB240; D_PowerDI-123; Mouser Part Number 621-DFLS240-7
J301: RJ45; RJ45_8N-S; Mouser Part Number 710-615008144221
R301, R302: 160 Ohms; R_0603_1608Metric; Mouser Part Number 603-AC0603JR-07160RL
R303: 120; R_0603_1608Metric; Mouser Part Number 603-RT0603DRE07120RL
T301: + LCC Power (2); TerminalBlock_TE_282834-2_1x02_P2.54mm_Horizontal; Mouser Part Number 651-1725656
U301: LM358; SOIC-8_3.9x4.9mm_P1.27mm; Mouser Part Number 595-LM358DR
U302: TCAN332DR; SOIC-8_3.9x4.9mm_P1.27mm; Mouser Part Number 595-TCAN332DR

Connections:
+3.3V: C301.1, C302.1, D301.2 (A), D302.2 (A), U301.8 (V+), U302.3 (Vcc); also elsewhere on the board
/PB12-CAN2_RX: U301.3 (+), U302.4 (R); also elsewhere on the board
/PB13-CAN2_TX: U301.5 (+), U302.1 (D); also elsewhere on the board
/VIN: D303.1 (K); also elsewhere on the board
GND: C301.2, C302.2, J301.3, J301.6, J301.7, T301.2, U301.4 (V-), U302.2 (GND); also elsewhere on the board
unnamed: D301.1 (K), R301.1
unnamed: D302.1 (K), R302.1
unnamed: D303.2 (A), D304.1 (K), J301.8
unnamed: D304.2 (A), T301.1
unnamed: J301.1, R303.2, U302.7 (CANH)
unnamed: J301.2, R303.1, U302.6 (CANL)
unnamed: R301.2, U301.6 (-), U301.7
unnamed: R302.2, U301.1, U301.2 (-)

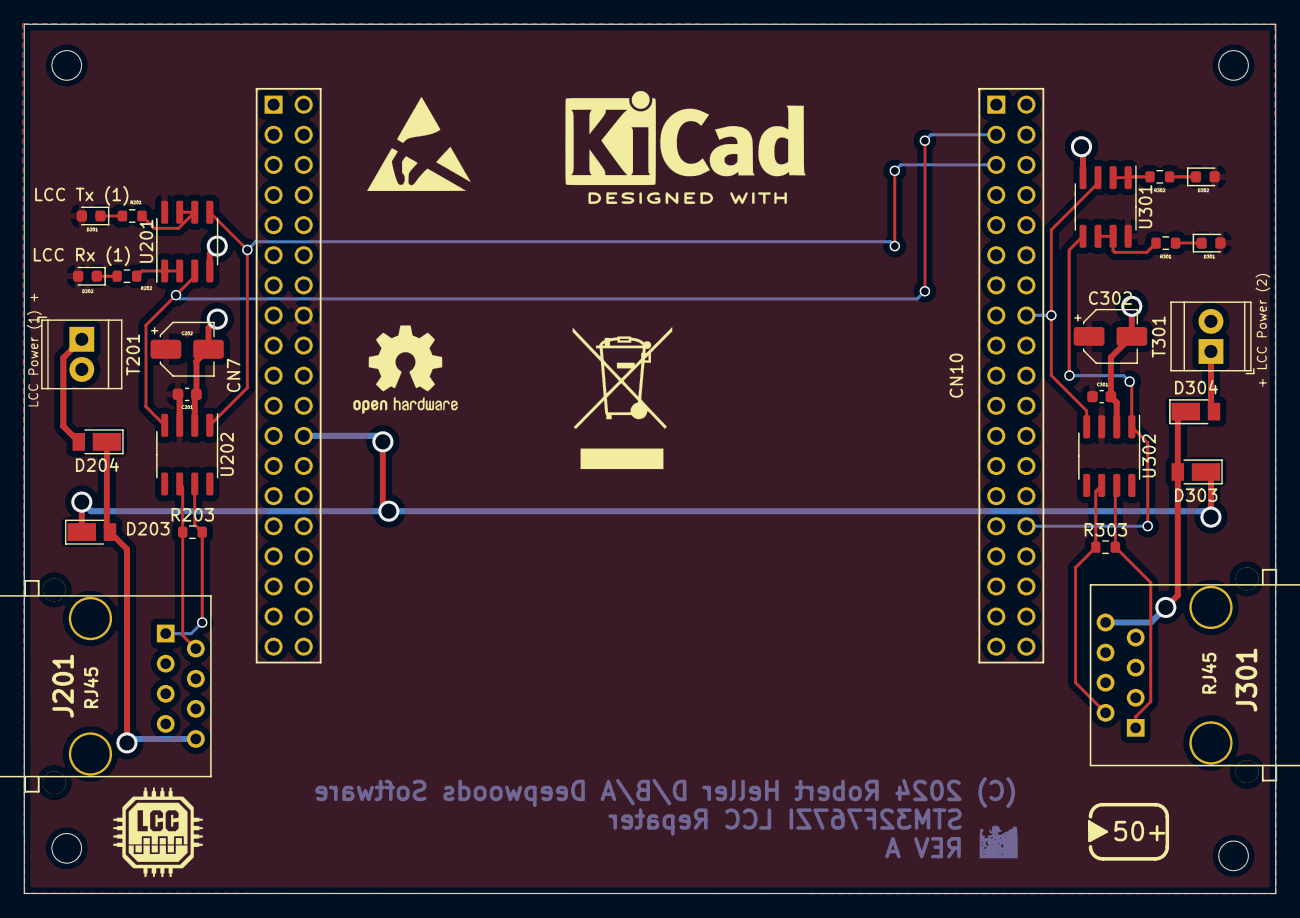
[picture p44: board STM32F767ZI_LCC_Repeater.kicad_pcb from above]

Board: 2 copper layers, 105.6 x 73.3 mm, 32 parts (0 on the bottom side), 23 nets.

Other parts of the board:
MH: MountingHole_2-5mm_RevA_Date21Jun2010
MH#2, MH#3, MH#4: MountingHole_2-5mm_RevA_Date21Jun2010

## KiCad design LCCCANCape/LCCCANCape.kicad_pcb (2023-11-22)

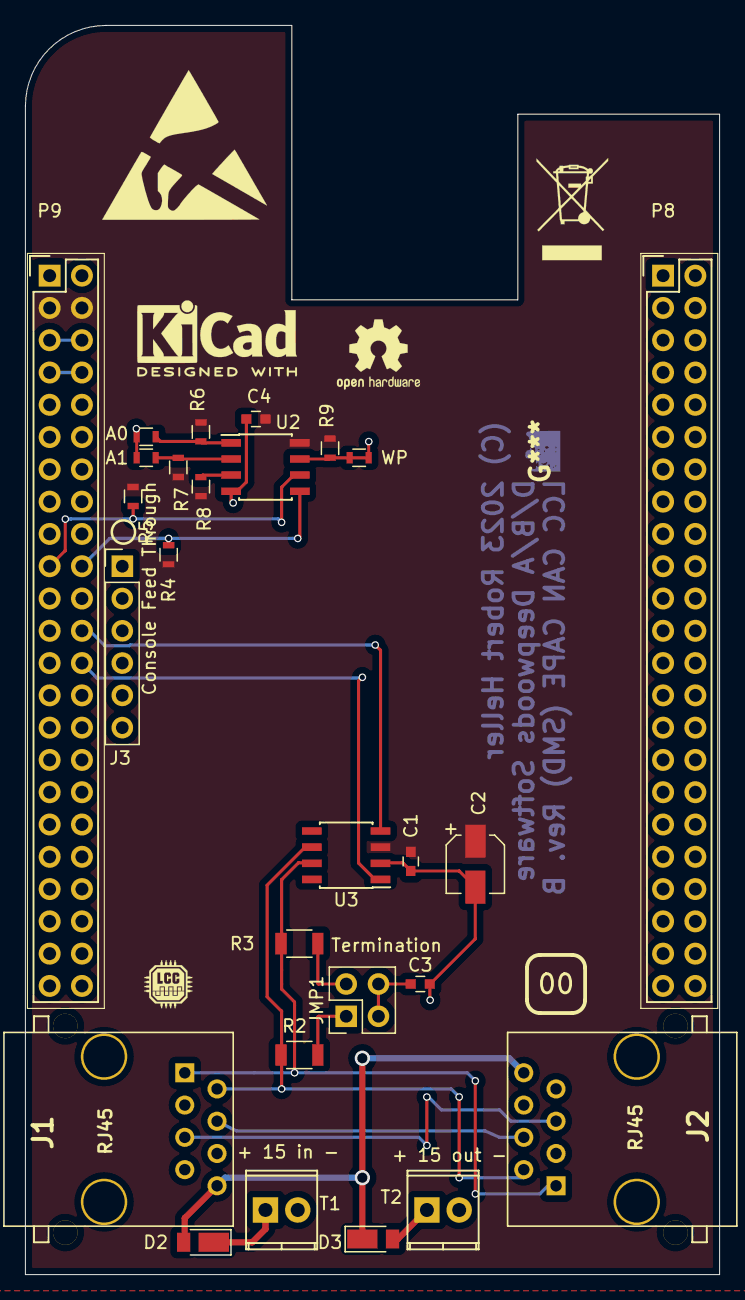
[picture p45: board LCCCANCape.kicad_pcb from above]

Board: 2 copper layers, 54.6 x 98.3 mm, 27 parts (0 on the bottom side), 22 nets.

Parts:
C1, C4: .1 uf; C_0603
C2: 15 uf 35V; CP_Elec_4x5.7
C3: 47 nf; C_0603
D2, D3: DFLS240-7; D_PowerDI-123
J1, J2: RJ45; RJ45_8N-S
J3: Console Feed Through; Pin_Header_Straight_1x06_Pitch2.54mm
JMP1: Termination; Pin_Header_Straight_2x02_Pitch2.54mm
JP1: A0; JP_0603_Open
JP2: A1; JP_0603_Open
JP3: WP; JP_0603_Closed
P8, P9: BeagleBone_Black_Header; Socket_BeagleBone_Black
R2, R3: 60 Ohms; R_1206
R4, R5: 5.6K; R_0603
R6, R7, R8: 4.75K; R_0603
R9: 10K; R_0603
T1: + 15 in -; TerminalBlock_Phoenix_MPT-2.54mm_2pol
T2: + 15 out -; TerminalBlock_Phoenix_MPT-2.54mm_2pol
U2: CAT24C256W; SOIC-8_3.9x4.9mm_Pitch1.27mm
U3: TCAN332DR; SOIC-8_3.9x4.9mm_Pitch1.27mm

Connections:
+3V3: C1.1, C2.1, C4.1, P9.3, P9.4, R4.1, R5.1, R6.1, R7.1, R8.1, R9.1, U2.8, U3.3
+5V: P9.5, P9.6
/CANH: J1.1, J2.1, R3.1, U3.7
/CANL: J1.2, J2.2, R2.1, U3.6
/CANRX: P9.24, U3.4
/CANTX: P9.26, U3.1
/SCL: P9.19, R5.2, U2.6
/SDA: P9.20, R4.2, U2.5
GND: C1.2, C2.2, C3.2, C4.2, J1.3, J1.6, J1.7, J2.3, J2.6, J2.7, JP1.1, JP2.1, JP3.1, P8.1, P8.2, P9.1, P9.2, P9.43, P9.44, P9.45, P9.46, T1.2, T2.2, U2.4, U3.2
unnamed: C3.1, JMP1.3, JMP1.4
unnamed: D2.1, T1.1
unnamed: D2.2, D3.1, J1.8, J2.8
unnamed: D3.2, T2.1
unnamed: J1.4, J2.4
unnamed: J1.5, J2.5
unnamed: JMP1.1, R2.2
unnamed: JMP1.2, R3.2
unnamed: JP1.2, R6.2, U2.1
unnamed: JP2.2, R7.2, U2.2
unnamed: JP3.2, R9.2, U2.7
unnamed: R8.2, U2.3
SYS_5V: P9.7, P9.8

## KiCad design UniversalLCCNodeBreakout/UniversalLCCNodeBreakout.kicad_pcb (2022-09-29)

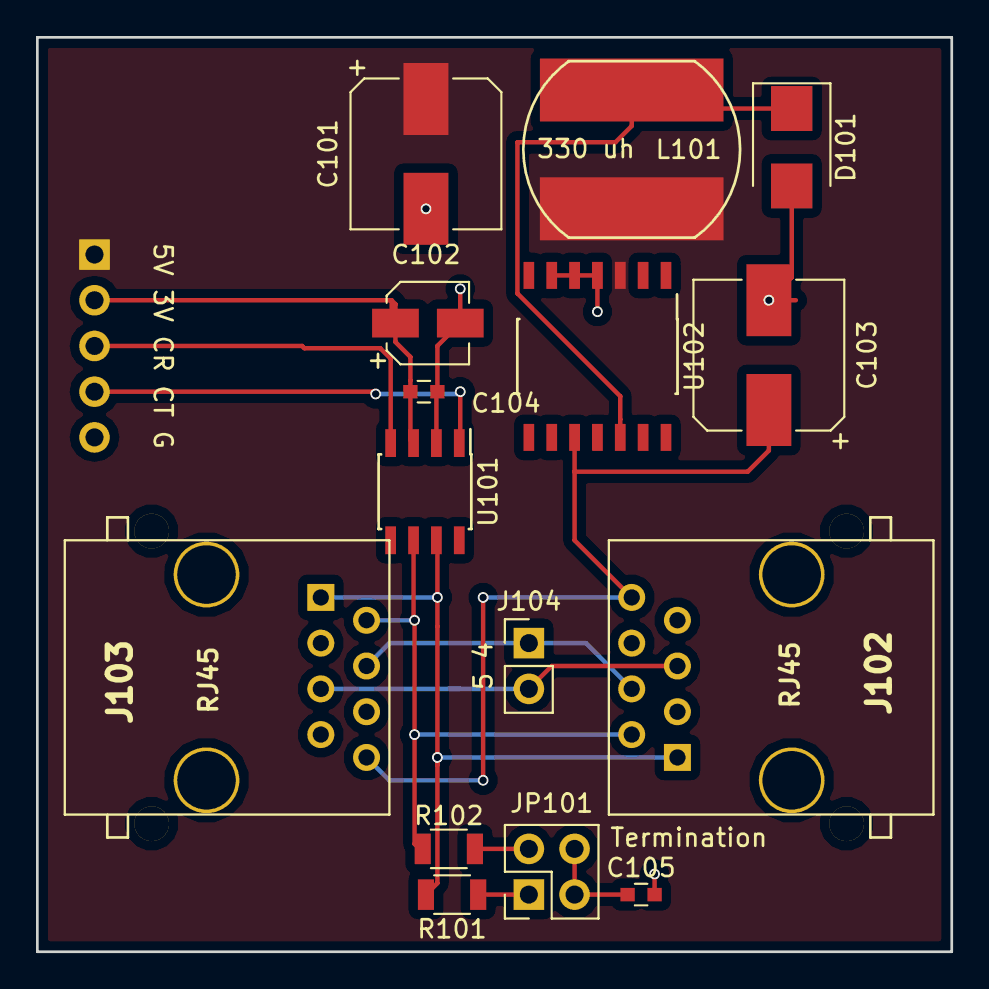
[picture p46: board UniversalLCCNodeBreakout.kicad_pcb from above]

Board: 2 copper layers, 50.8 x 50.8 mm, 16 parts (1 on the bottom side), 14 nets.

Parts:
C101: 220 uf 25V; CP_Elec_8x10
C102: .1 uf; C_0603
C103: 22 uf 100V; CP_Elec_8x10
C104: 15 uf 15V; CP_Elec_4x5.7
C105: 47 nf; C_0603
D101: CMSH1-60 TR13; D_SMB
J101: 5V 3V CR CT G; Pin_Header_Straight_1x05_Pitch2.54mm
J102, J103: RJ45; RJ45_8N-S
J104: 5 4; Socket_Strip_Straight_1x02_Pitch2.54mm
JP101: Termination; Pin_Header_Straight_2x02_Pitch2.54mm
L101: 330 uh; SRN1060
R101, R102: 60 Ohms; R_1206
U101: TCAN332DR; SOIC-8_3.9x4.9mm_Pitch1.27mm
U102: LM2574N-5; SOIC-14_7.4x8.7mm_Pitch1.27mm

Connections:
+3V3: C102.1, C104.1, J101.2, U101.3
+5V: C101.1, J101.1, L101.2, U102.3
/CANH: J102.1, J103.1, R101.1, U101.7
/CANL: J102.2, J103.2, R102.1, U101.6
/CAN_RX: J101.3, U101.4
/CAN_TX: J101.4, U101.1
CAN +12V: C103.1, J102.8, J103.8, U102.10
GND: C101.2, C102.2, C103.2, C104.2, C105.2, D101.2, J101.5, J102.3, J102.6, J102.7, J103.3, J103.6, J103.7, U101.2, U102.4, U102.5, U102.6
unnamed: C105.1, JP101.3, JP101.4
unnamed: D101.1, L101.1, U102.12
unnamed: J102.4, J103.4, J104.1
unnamed: J102.5, J103.5, J104.2
unnamed: JP101.1, R101.2
unnamed: JP101.2, R102.2

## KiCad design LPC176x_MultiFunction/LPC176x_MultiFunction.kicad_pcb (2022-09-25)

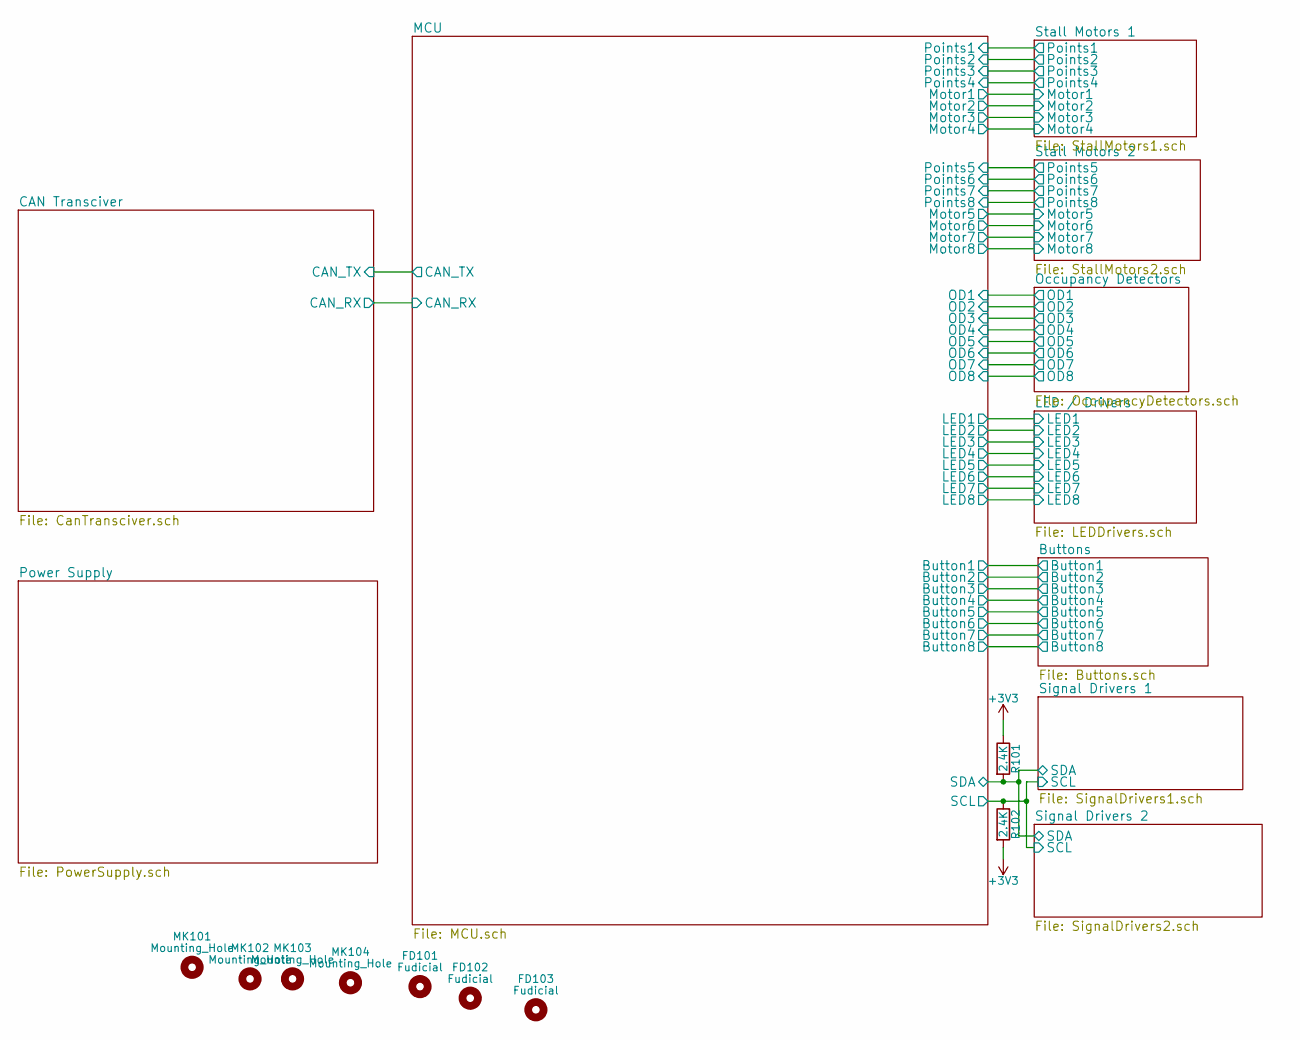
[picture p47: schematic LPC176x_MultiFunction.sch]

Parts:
FD101, FD102, FD103: Fudicial; Fiducial_classic_Small_SilkscreenTop_Type1
MK101, MK102, MK103, MK104: Mounting_Hole; MountingHole_3.2mm_M3
R101, R102: 2.4K; R_0402

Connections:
/MCU/SCL: R102.1; also elsewhere on the board
/MCU/SDA: R101.2; also elsewhere on the board

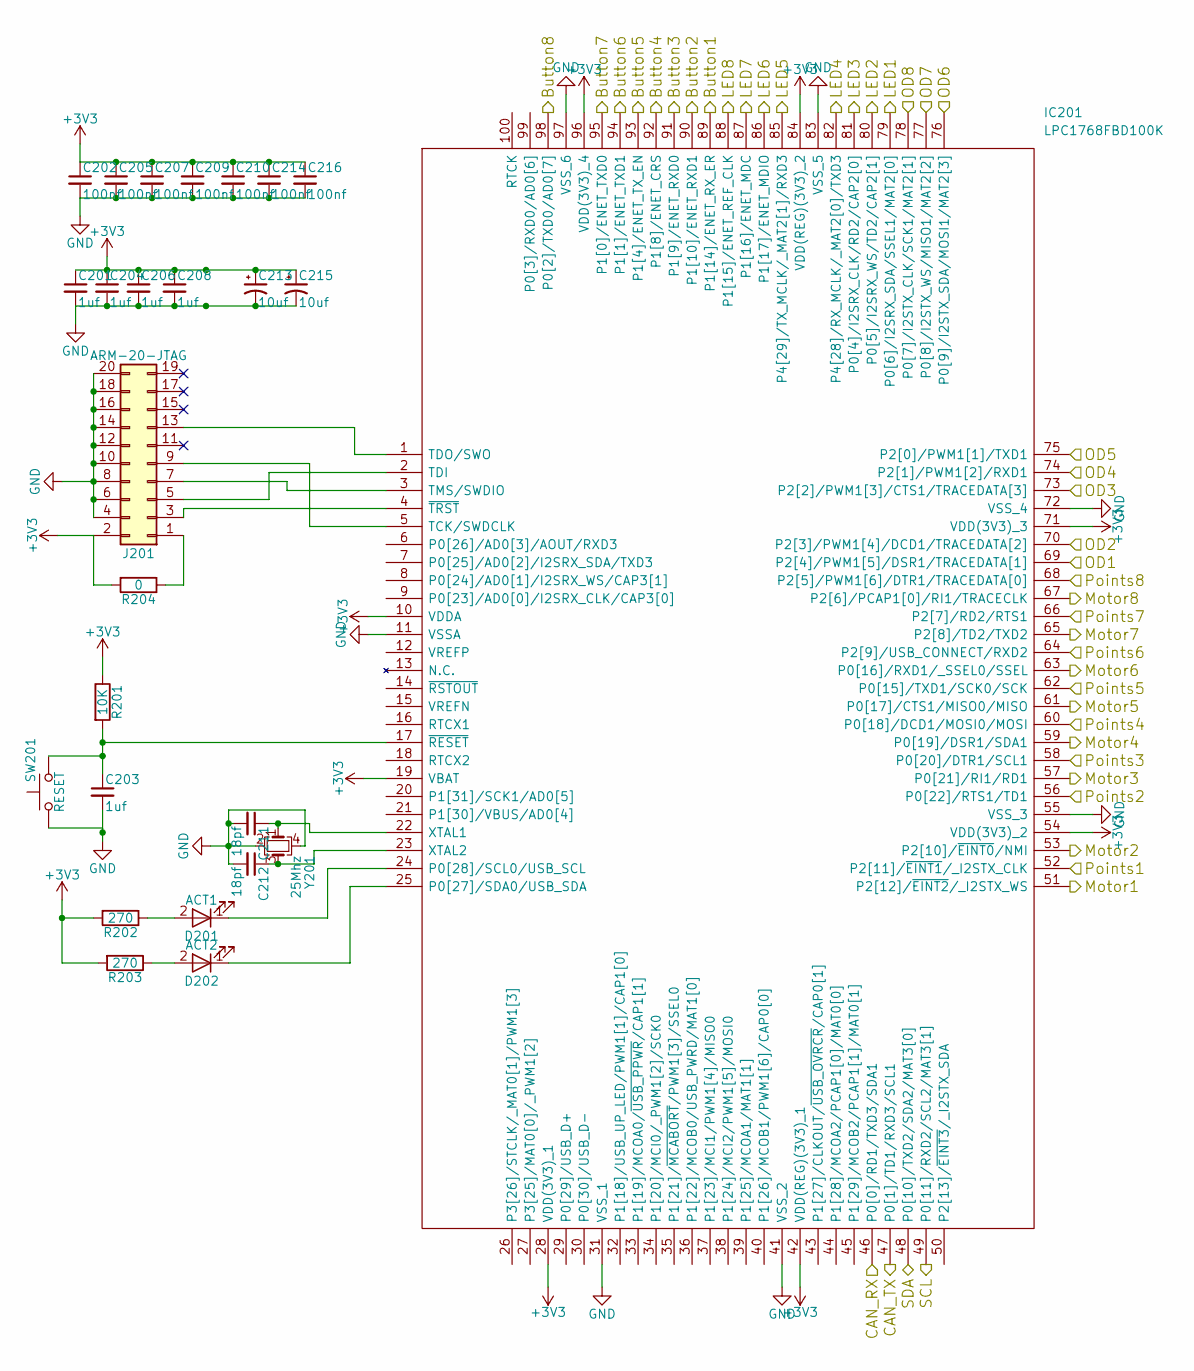
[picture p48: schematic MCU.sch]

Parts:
C201, C203, C204, C206, C208: 1uf; C_0603
C202, C205, C207, C209, C210, C214, C216: 100nf; C_0402
C211, C212: 18pf; C_0402; Mouser Part Number 81-GCM1555C1H180JA6J
C213, C215: 10uf; C_POL_1206
D201: ACT1; LED_0402
D202: ACT2; LED_0402
IC201: LPC1768FBD100K; QFP50P1600X1600X160-100N; Manufacturer_Part_Number LPC1768FBD100K
J201: ARM-20-JTAG; IDC_Header_Straight_20pins
R201: 10K; R_0402
R202, R203: 270; R_0402
R204: 0; R_0402
SW201: RESET; SW_SPST_B3U-1000P-B; Mouser Part Number 653-B3U-1000P-B
Y201: 25Mhz; Crystal_SMD_Abracon_ABM8G-4pin_3.2x2.5mm; Mouser Part Number 815-ABM8G-25-4YT3

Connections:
/Buttons/Button1: IC201.89 (P1[14]/ENET_RX_ER); also elsewhere on the board
/Buttons/Button2: IC201.90 (P1[10]/ENET_RXD1); also elsewhere on the board
/Buttons/Button3: IC201.91 (P1[9]/ENET_RXD0); also elsewhere on the board
/Buttons/Button4: IC201.92 (P1[8]/ENET_CRS); also elsewhere on the board
/Buttons/Button5: IC201.93 (P1[4]/ENET_TX_EN); also elsewhere on the board
/Buttons/Button6: IC201.94 (P1[1]/ENET_TXD1); also elsewhere on the board
/Buttons/Button7: IC201.95 (P1[0]/ENET_TXD0); also elsewhere on the board
/Buttons/Button8: IC201.98 (P0[2]/TXD0/AD0[7]); also elsewhere on the board
/CAN Transciver/CAN_RX: IC201.46 (P0[0]/RD1/TXD3/SDA1); also elsewhere on the board
/CAN Transciver/CAN_TX: IC201.47 (P0[1]/TD1/RXD3/SCL1); also elsewhere on the board
/LED / Drivers/LED1: IC201.79 (P0[6]/I2SRX_SDA/SSEL1/MAT2[0]); also elsewhere on the board
/LED / Drivers/LED2: IC201.80 (P0[5]/I2SRX_WS/TD2/CAP2[1]); also elsewhere on the board
/LED / Drivers/LED3: IC201.81 (P0[4]/I2SRX_CLK/RD2/CAP2[0]); also elsewhere on the board
/LED / Drivers/LED4: IC201.82 (P4[28]/RX_MCLK/_MAT2[0]/TXD3); also elsewhere on the board
/LED / Drivers/LED5: IC201.85 (P4[29]/TX_MCLK/_MAT2[1]/RXD3); also elsewhere on the board
/LED / Drivers/LED6: IC201.86 (P1[17]/ENET_MDIO); also elsewhere on the board
/LED / Drivers/LED7: IC201.87 (P1[16]/ENET_MDC); also elsewhere on the board
/LED / Drivers/LED8: IC201.88 (P1[15]/ENET_REF_CLK); also elsewhere on the board
/MCU/Motor1: IC201.51 (P2[12]/~EINT2~/_I2STX_WS); also elsewhere on the board
/MCU/Motor2: IC201.53 (P2[10]/~EINT0~/NMI); also elsewhere on the board
/MCU/Motor3: IC201.57 (P0[21]/RI1/RD1); also elsewhere on the board
/MCU/Motor4: IC201.59 (P0[19]/DSR1/SDA1); also elsewhere on the board
/MCU/Motor5: IC201.61 (P0[17]/CTS1/MISO0/MISO); also elsewhere on the board
/MCU/Motor6: IC201.63 (P0[16]/RXD1/_SSEL0/SSEL); also elsewhere on the board
/MCU/Motor7: IC201.65 (P2[8]/TD2/TXD2); also elsewhere on the board
/MCU/Motor8: IC201.67 (P2[6]/PCAP1[0]/RI1/TRACECLK); also elsewhere on the board
/MCU/OD1: IC201.69 (P2[4]/PWM1[5]/DSR1/TRACEDATA[1]); also elsewhere on the board
/MCU/OD2: IC201.70 (P2[3]/PWM1[4]/DCD1/TRACEDATA[2]); also elsewhere on the board
/MCU/OD3: IC201.73 (P2[2]/PWM1[3]/CTS1/TRACEDATA[3]); also elsewhere on the board
/MCU/OD4: IC201.74 (P2[1]/PWM1[2]/RXD1); also elsewhere on the board
/MCU/OD5: IC201.75 (P2[0]/PWM1[1]/TXD1); also elsewhere on the board
/MCU/OD6: IC201.76 (P0[9]/I2STX_SDA/MOSI1/MAT2[3]); also elsewhere on the board
/MCU/OD7: IC201.77 (P0[8]/I2STX_WS/MISO1/MAT2[2]); also elsewhere on the board
/MCU/OD8: IC201.78 (P0[7]/I2STX_CLK/SCK1/MAT2[1]); also elsewhere on the board
/MCU/Points1: IC201.52 (P2[11]/~EINT1~/_I2STX_CLK); also elsewhere on the board
/MCU/Points2: IC201.56 (P0[22]/RTS1/TD1); also elsewhere on the board
/MCU/Points3: IC201.58 (P0[20]/DTR1/SCL1); also elsewhere on the board
/MCU/Points4: IC201.60 (P0[18]/DCD1/MOSI0/MOSI); also elsewhere on the board
/MCU/Points5: IC201.62 (P0[15]/TXD1/SCK0/SCK); also elsewhere on the board
/MCU/Points6: IC201.64 (P2[9]/USB_CONNECT/RXD2); also elsewhere on the board
/MCU/Points7: IC201.66 (P2[7]/RD2/RTS1); also elsewhere on the board
/MCU/Points8: IC201.68 (P2[5]/PWM1[6]/DTR1/TRACEDATA[0]); also elsewhere on the board
/MCU/SCL: IC201.49 (P0[11]/RXD2/SCL2/MAT3[1]); also elsewhere on the board
/MCU/SDA: IC201.48 (P0[10]/TXD2/SDA2/MAT3[0]); also elsewhere on the board
GND: C201.2, C202.2, C203.2, C204.2, C205.2, C206.2, C207.2, C208.2, C209.2, C210.2, C211.2, C212.2, C213.2, C214.2, C215.2, C216.2, IC201.11 (VSSA), IC201.31 (VSS_1), IC201.41 (VSS_2), IC201.55 (VSS_3), IC201.72 (VSS_4), IC201.83 (VSS_5), IC201.97 (VSS_6), J201.4, J201.6, J201.8, J201.10, J201.12, J201.14, J201.16, J201.18, J201.20, SW201.1, Y201.2, Y201.4; also elsewhere on the board
unnamed: C203.1, IC201.17 (~RESET), R201.2, SW201.2
unnamed: C211.1, IC201.22 (XTAL1), Y201.1
unnamed: C212.1, IC201.23 (XTAL2), Y201.3
unnamed: D201.1 (K), IC201.24 (P0[28]/SCL0/USB_SCL)
unnamed: D201.2 (A), R202.1
unnamed: D202.1 (K), IC201.25 (P0[27]/SDA0/USB_SDA)
unnamed: D202.2 (A), R203.1
unnamed: IC201.1 (TDO/SWO), J201.13
unnamed: IC201.2 (TDI), J201.5
unnamed: IC201.3 (TMS/SWDIO), J201.7
unnamed: IC201.4 (~TRST), J201.3
unnamed: IC201.5 (TCK/SWDCLK), J201.9
unnamed: J201.1, R204.1

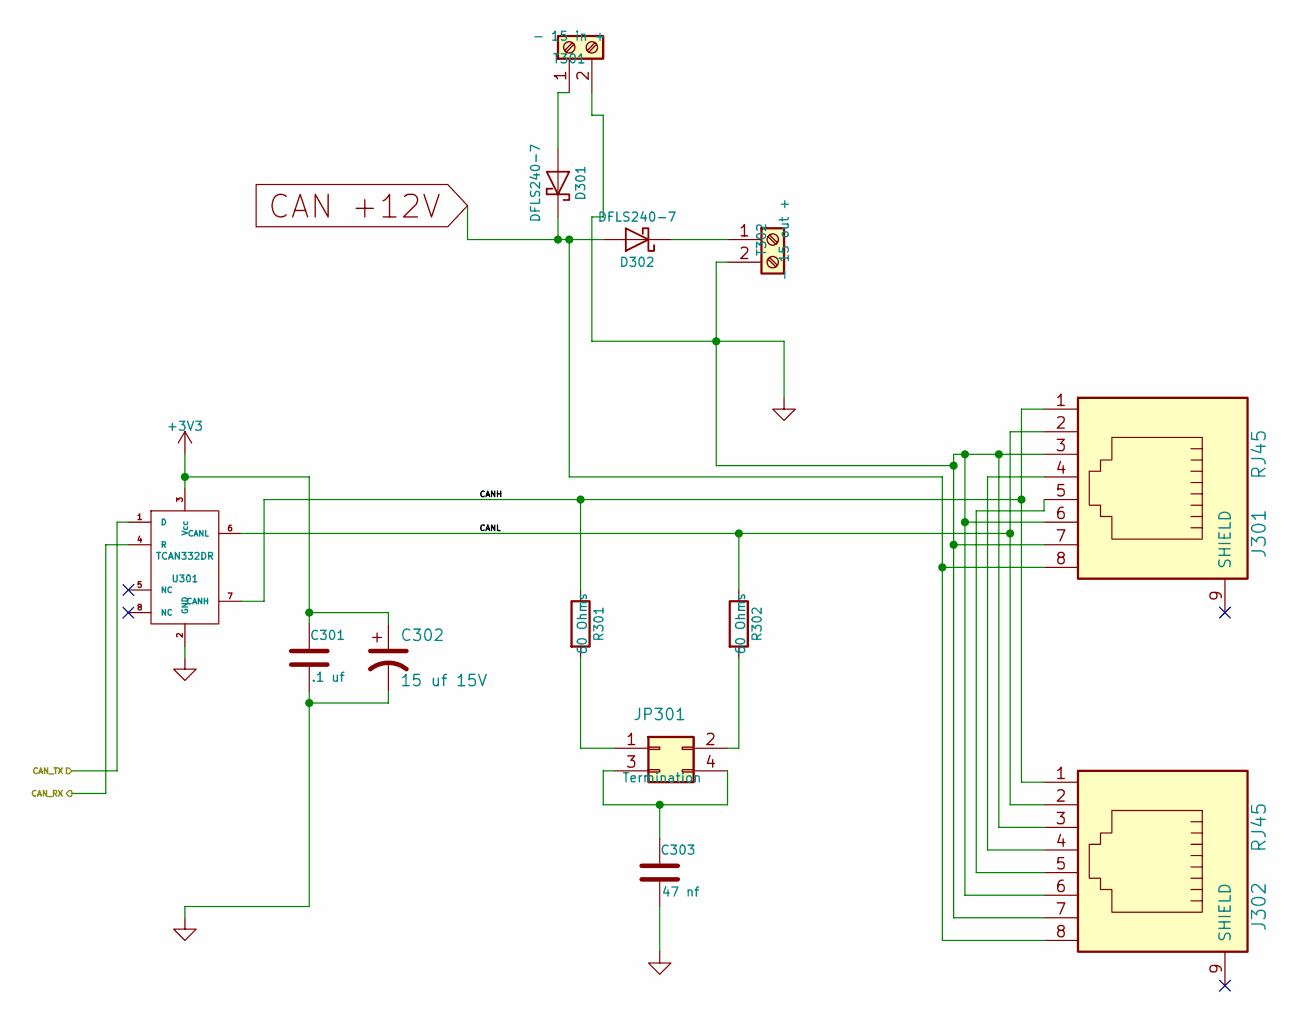
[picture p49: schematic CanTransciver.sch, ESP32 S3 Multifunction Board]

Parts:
C301: .1 uf; C_0603; Mouser Part Number 710-885012206095
C302: 15 uf 15V; CP_Elec_4x5.7; Mouser Part Number 647-UUD1C150MCL
C303: 47 nf; C_0603; Mouser Part Number 710-885012206093
D301, D302: DFLS240-7; D_PowerDI-123; Mouser Part Number 621-DFLS240-7
J301, J302: RJ45; RJ45_8N-S; Mouser Part Number 710-615008144221
JP301: Termination; Pin_Header_Straight_2x02_Pitch2.54mm; Mouser Part Number 649-67997-404HLF
R301, R302: 60 Ohms; R_1206; Mouser Part Number 71-CRCW120660R0KNAIF
T301: - 15 in +; TerminalBlock_Pheonix_MPT-2.54mm_2pol; Mouser Part Number 651-1725656
T302: - 15 out +; TerminalBlock_Pheonix_MPT-2.54mm_2pol; Mouser Part Number 651-1725656
U301: TCAN332DR; SOIC-8_3.9x4.9mm_Pitch1.27mm; Mouser Part Number 595-TCAN332DR

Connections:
/CAN Transciver/CANH: J301.1, J302.1, R301.1, U301.7 (CANH)
/CAN Transciver/CANL: J301.2, J302.2, R302.1, U301.6 (CANL)
/CAN Transciver/CAN_RX: U301.4 (R); also elsewhere on the board
/CAN Transciver/CAN_TX: U301.1 (D); also elsewhere on the board
CAN +12V: D301.1 (K), D302.2 (A), J301.8, J302.8; also elsewhere on the board
GND: C301.2, C302.2, C303.2, J301.3, J301.6, J301.7, J302.3, J302.6, J302.7, T301.2, T302.2, U301.2 (GND); also elsewhere on the board
unnamed: C303.1, JP301.3, JP301.4
unnamed: D301.2 (A), T301.1
unnamed: D302.1 (K), T302.1
unnamed: J301.4, J302.4
unnamed: J301.5, J302.5
unnamed: JP301.1, R301.2
unnamed: JP301.2, R302.2

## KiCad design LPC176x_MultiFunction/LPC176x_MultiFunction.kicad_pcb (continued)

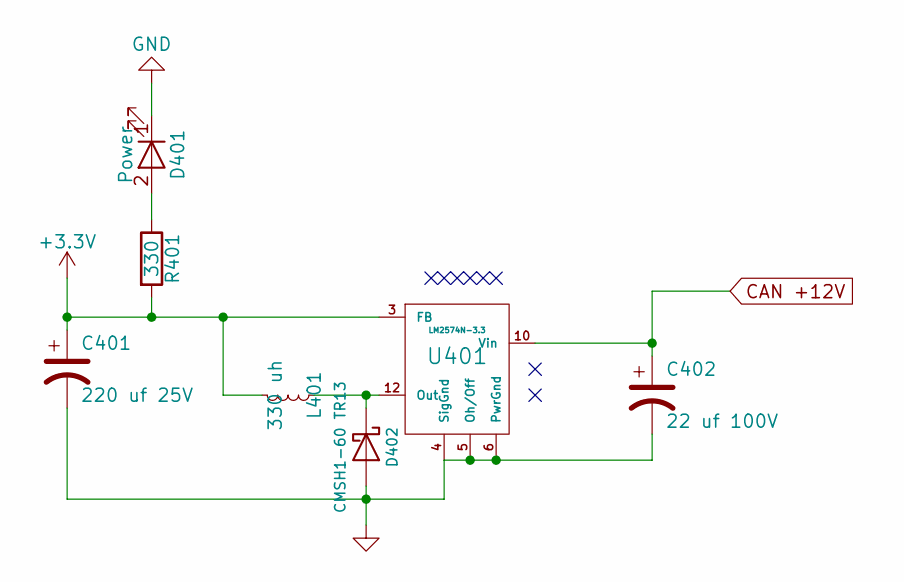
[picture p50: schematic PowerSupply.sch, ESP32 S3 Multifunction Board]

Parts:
C401: 220 uf 25V; CP_Elec_8x10; Mouser Part Number 647-UWT1E221MNL1GS
C402: 22 uf 100V; CP_Elec_8x10; Mouser Part Number 647-UUX2A220MNL6GS
D401: Power; LED_0402
D402: CMSH1-60 TR13; D_SMB; Mouser Part Number 610-CMSH1-60TR13
L401: 330 uh; SRN1060; Mouser Part Number 652-SRN1060-331M
R401: 330; R_0402
U401: LM2574N-3.3; SOIC-14_7.4x8.7mm_Pitch1.27mm; Mouser Part Number 926-LM2574MX33NOPB

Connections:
CAN +12V: C402.1, U401.10 (Vin); also elsewhere on the board
GND: C401.2, C402.2, D401.1 (K), D402.2 (A), U401.4 (SigGnd), U401.5 (Oh/Off), U401.6 (PwrGnd); also elsewhere on the board
unnamed: D401.2 (A), R401.1
unnamed: D402.1 (K), L401.1, U401.12 (Out)


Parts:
C501, C502: .1 uf; C_0603; Mouser Part Number 710-885012206095
D501: DFLS240-7; D_PowerDI-123; Mouser Part Number 621-DFLS240-7
J501: -SM+; TerminalBlock_Pheonix_MPT-2.54mm_2pol; Mouser Part Number 651-172565
J502: Motor 1; 474817; Mouser Part Number 305-474817
J503: Motor 2; 474817; Mouser Part Number 305-474817
J504: Motor 3; 474817; Mouser Part Number 305-474817
J505: Motor 4; 474817; Mouser Part Number 305-474817
RR501: 10K Ohms; 4814P; Mouser Part Number 652-4814P-2LF-10K
U501, U502: 74HCT00; SOIC-14_3.9x8.7mm_Pitch1.27mm; Mouser Part Number 595-SN74AHC00D
U503, U504, U505, U506: TC4428; SOIC-8_3.9x4.9mm_Pitch1.27mm; Mouser Part Number 579-TC4428VOA

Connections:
/MCU/Motor1: U503.2 (IN), U503.4 (IN); also elsewhere on the board
/MCU/Motor2: U504.2 (IN), U504.4 (IN); also elsewhere on the board
/MCU/Motor3: U505.2 (IN), U505.4 (IN); also elsewhere on the board
/MCU/Motor4: U506.2 (IN), U506.4 (IN); also elsewhere on the board
/MCU/Points1: U501.3, U501.4; also elsewhere on the board
/MCU/Points2: U501.8, U501.12; also elsewhere on the board
/MCU/Points3: U502.3, U502.4; also elsewhere on the board
/MCU/Points4: U502.8, U502.12; also elsewhere on the board
/Stall Motors 1/M1A: J502.1, U503.5 (Out)
/Stall Motors 1/M1B: J502.2, U503.7 (Out)
/Stall Motors 1/M2A: J503.1, U504.5 (Out)
/Stall Motors 1/M2B: J503.2, U504.7 (Out)
/Stall Motors 1/M3A: J504.1, U505.5 (Out)
/Stall Motors 1/M3B: J504.2, U505.7 (Out)
/Stall Motors 1/M4A: J505.1, U506.5 (Out)
/Stall Motors 1/M4B: J505.2, U506.7 (Out)
/Stall Motors 1/P1A: J502.3, RR501.6 (R6), U501.1
/Stall Motors 1/P1B: J502.5, RR501.5 (R5), U501.5
/Stall Motors 1/P2A: J503.3, RR501.4 (R4), U501.9
/Stall Motors 1/P2B: J503.5, RR501.3 (R3), U501.13
/Stall Motors 1/P3A: J504.3, RR501.13 (R13), U502.1
/Stall Motors 1/P3B: J504.5, RR501.12 (R12), U502.5
/Stall Motors 1/P4A: J505.3, RR501.11 (R11), U502.9
/Stall Motors 1/P4B: J505.5, RR501.10 (R10), U502.13
CAN +12V: D501.2 (A); also elsewhere on the board
GND: C501.2, C502.2, J501.2, J502.4, J503.4, J504.4, J505.4, U501.7 (GND), U502.7 (GND), U503.3 (GND), U504.3 (GND), U505.3 (GND), U506.3 (GND); also elsewhere on the board
unnamed: U501.2, U501.6
unnamed: U501.10, U501.11
unnamed: U502.2, U502.6
unnamed: U502.10, U502.11
SMPower: D501.1 (K), J501.1, U503.6 (Vdd), U504.6 (Vdd), U505.6 (Vdd), U506.6 (Vdd); also elsewhere on the board


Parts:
C601, C602: .1 uf; C_0603; Mouser Part Number 710-885012206095
J601: Motor 5; 474817; Mouser Part Number 305-474817
J602: Motor 6; 474817; Mouser Part Number 305-474817
J603: Motor 7; 474817; Mouser Part Number 305-474817
J604: Motor 8; 474817; Mouser Part Number 305-474817
RR601: 10K Ohms; 4814P; Mouser Part Number 652-4814P-2LF-10K
U601, U602: 74HCT00; SOIC-14_3.9x8.7mm_Pitch1.27mm; Mouser Part Number 595-SN74AHC00D
U603, U604, U605, U606: TC4428; SOIC-8_3.9x4.9mm_Pitch1.27mm; Mouser Part Number 579-TC4428VOA

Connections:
/MCU/Motor5: U603.2 (IN), U603.4 (IN); also elsewhere on the board
/MCU/Motor6: U604.2 (IN), U604.4 (IN); also elsewhere on the board
/MCU/Motor7: U605.2 (IN), U605.4 (IN); also elsewhere on the board
/MCU/Motor8: U606.2 (IN), U606.4 (IN); also elsewhere on the board
/MCU/Points5: U601.3, U601.4; also elsewhere on the board
/MCU/Points6: U601.8, U601.12; also elsewhere on the board
/MCU/Points7: U602.3, U602.4; also elsewhere on the board
/MCU/Points8: U602.8, U602.12; also elsewhere on the board
/Stall Motors 2/M5A: J601.1, U603.5 (Out)
/Stall Motors 2/M5B: J601.2, U603.7 (Out)
/Stall Motors 2/M6A: J602.1, U604.5 (Out)
/Stall Motors 2/M6B: J602.2, U604.7 (Out)
/Stall Motors 2/M7A: J603.1, U605.5 (Out)
/Stall Motors 2/M7B: J603.2, U605.7 (Out)
/Stall Motors 2/M8A: J604.1, U606.5 (Out)
/Stall Motors 2/M8B: J604.2, U606.7 (Out)
/Stall Motors 2/P5A: J601.3, RR601.6 (R6), U601.1
/Stall Motors 2/P5B: J601.5, RR601.5 (R5), U601.5
/Stall Motors 2/P6A: J602.3, RR601.4 (R4), U601.9
/Stall Motors 2/P6B: J602.5, RR601.3 (R3), U601.13
/Stall Motors 2/P7A: J603.3, RR601.13 (R13), U602.1
/Stall Motors 2/P7B: J603.5, RR601.12 (R12), U602.5
/Stall Motors 2/P8A: J604.3, RR601.11 (R11), U602.9
/Stall Motors 2/P8B: J604.5, RR601.10 (R10), U602.13
GND: C601.2, C602.2, J601.4, J602.4, J603.4, J604.4, U601.7 (GND), U602.7 (GND), U603.3 (GND), U604.3 (GND), U605.3 (GND), U606.3 (GND); also elsewhere on the board
unnamed: U601.2, U601.6
unnamed: U601.10, U601.11
unnamed: U602.2, U602.6
unnamed: U602.10, U602.11
SMPower: U603.6 (Vdd), U604.6 (Vdd), U605.6 (Vdd), U606.6 (Vdd); also elsewhere on the board


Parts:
C701, C702, C703, C704, C705, C706, C707, C708: 2.2uf 50V; CP_Elec_4x5.7; Mouser Part Number 710-865080140002
D701, D702, D703, D704, D705, D706, D707, D708, D713, D714, D715, D716, D717, D718, D719, D720: 1N4148; D_SOD-123; Mouser Part Number 750-1N4148WS-HF
D709, D710, D711, D712, D721, D722, D723, D724: LED; LED_0603; Mouser Part Number 710-150060SS55040
J701: OC 1-4; 474818; Mouser Part Number 305-474818
J702: OC 5-8; 474818; Mouser Part Number 305-474818
R701, R702, R703, R704, R713, R714, R715, R716: 22K Ohms; R_0603; Mouser Part Number 71-RCG060322K0JNEA
R705, R706, R707, R708, R717, R718, R719, R720: 1M Ohms; R_0603; Mouser Part Number 71-CRCW06031M00JNEAC
R709, R710, R711, R712, R721, R722, R723, R724: 2.7K Ohms; R_0603; Mouser Part Number 71-CRCW06032K70JNEAC
RV701, RV702, RV703, RV704, RV705, RV706, RV707, RV708: 25K Ohms; Potentiometer_Trimmer_Bourns_3214J; Mouser Part Number 652-3314J-1-253E
U701, U703: LM339; SOIC-14_3.9x8.7mm_Pitch1.27mm; Mouser Part Number 595-LM339DR
U702, U704: LM339; SOIC-14_3.9x8.7mm_Pitch1.27mm

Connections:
/MCU/OD1: D709.1 (K), U701.1; also elsewhere on the board
/MCU/OD2: D710.1 (K), U701.14; also elsewhere on the board
/MCU/OD3: D711.1 (K), U702.1; also elsewhere on the board
/MCU/OD4: D712.1 (K), U702.14; also elsewhere on the board
/MCU/OD5: D721.1 (K), U703.1; also elsewhere on the board
/MCU/OD6: D722.1 (K), U703.14; also elsewhere on the board
/MCU/OD7: D723.1 (K), U704.1; also elsewhere on the board
/MCU/OD8: D724.1 (K), U704.14; also elsewhere on the board
GND: C701.2, C702.2, C703.2, C704.2, C705.2, C706.2, C707.2, C708.2, RV701.1, RV702.1, RV703.1, RV704.1, RV705.1, RV706.1, RV707.1, RV708.1, U701.12 (V-), U702.12 (V-), U703.12 (V-), U704.12 (V-); also elsewhere on the board
unnamed: C701.1, R705.2, U701.2, U701.7 (+)
unnamed: C702.1, R706.2, U701.9 (+), U701.13
unnamed: C703.1, R707.2, U702.2, U702.7 (+)
unnamed: C704.1, R708.2, U702.9 (+), U702.13
unnamed: C705.1, R717.2, U703.2, U703.7 (+)
unnamed: C706.1, R718.2, U703.9 (+), U703.13
unnamed: C707.1, R719.2, U704.2, U704.7 (+)
unnamed: C708.1, R720.2, U704.9 (+), U704.13
unnamed: D701.1 (K), D705.2 (A), J701.8, U701.4 (-)
unnamed: D701.2 (A), D705.1 (K), J701.7, RV701.2
unnamed: D702.1 (K), D706.2 (A), J701.6, U701.10 (-)
unnamed: D702.2 (A), D706.1 (K), J701.5, RV702.2
unnamed: D703.1 (K), D707.2 (A), J701.4, U702.4 (-)
unnamed: D703.2 (A), D707.1 (K), J701.3, RV703.2
unnamed: D704.1 (K), D708.2 (A), J701.2, U702.10 (-)
unnamed: D704.2 (A), D708.1 (K), J701.1, RV704.2
unnamed: D709.2 (A), R709.2
unnamed: D710.2 (A), R710.2
unnamed: D711.2 (A), R711.2
unnamed: D712.2 (A), R712.2
unnamed: D713.1 (K), D717.2 (A), J702.8, U703.4 (-)
unnamed: D713.2 (A), D717.1 (K), J702.7, RV705.2
unnamed: D714.1 (K), D718.2 (A), J702.6, U703.10 (-)
unnamed: D714.2 (A), D718.1 (K), J702.5, RV706.2
unnamed: D715.1 (K), D719.2 (A), J702.4, U704.4 (-)
unnamed: D715.2 (A), D719.1 (K), J702.3, RV707.2
unnamed: D716.1 (K), D720.2 (A), J702.2, U704.10 (-)
unnamed: D716.2 (A), D720.1 (K), J702.1, RV708.2
unnamed: D721.2 (A), R721.2
unnamed: D722.2 (A), R722.2
unnamed: D723.2 (A), R723.2
unnamed: D724.2 (A), R724.2
unnamed: R701.2, RV701.3, U701.5 (+), U701.6 (-)
unnamed: R702.2, RV702.3, U701.8 (-), U701.11 (+)
unnamed: R703.2, RV703.3, U702.5 (+), U702.6 (-)
unnamed: R704.2, RV704.3, U702.8 (-), U702.11 (+)
unnamed: R713.2, RV705.3, U703.5 (+), U703.6 (-)
unnamed: R714.2, RV706.3, U703.8 (-), U703.11 (+)
unnamed: R715.2, RV707.3, U704.5 (+), U704.6 (-)
unnamed: R716.2, RV708.3, U704.8 (-), U704.11 (+)


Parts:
R801, R803, R805, R807, R809, R811, R813, R815: R; R_Axial_DIN0207_L6.3mm_D2.5mm_P7.62mm_Horizontal
R802, R804, R806, R808, R810, R812, R814, R816: 1.5K Ohms; R_0603; Mouser Part Number 71-CRCW06031K50JNEAC
Term801: GND 8 7 6 5 4 3 2 1 +; TerminalBlock_Pheonix_MPT-2.54mm_10pol; Mouser Part Number 651-1725737
U801, U802, U803, U804: TC4426; SOIC-8_3.9x4.9mm_Pitch1.27mm; Mouser Part Number 579-TC1426COA713

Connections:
/LED / Drivers/LED1: U801.4 (IN); also elsewhere on the board
/LED / Drivers/LED2: U801.2 (IN); also elsewhere on the board
/LED / Drivers/LED3: U802.4 (IN); also elsewhere on the board
/LED / Drivers/LED4: U802.2 (IN); also elsewhere on the board
/LED / Drivers/LED5: U803.4 (IN); also elsewhere on the board
/LED / Drivers/LED6: U803.2 (IN); also elsewhere on the board
/LED / Drivers/LED7: U804.4 (IN); also elsewhere on the board
/LED / Drivers/LED8: U804.2 (IN); also elsewhere on the board
GND: Term801.10, U801.3 (GND), U802.3 (GND), U803.3 (GND), U804.3 (GND); also elsewhere on the board
unnamed: R801.1, R802.1, Term801.2
unnamed: R801.2, R802.2, U801.5 (Out)
unnamed: R803.1, R804.1, Term801.3
unnamed: R803.2, R804.2, U801.7 (Out)
unnamed: R805.1, R806.1, Term801.4
unnamed: R805.2, R806.2, U802.5 (Out)
unnamed: R807.1, R808.1, Term801.5
unnamed: R807.2, R808.2, U802.7 (Out)
unnamed: R809.1, R810.1, Term801.6
unnamed: R809.2, R810.2, U803.5 (Out)
unnamed: R811.1, R812.1, Term801.7
unnamed: R811.2, R812.2, U803.7 (Out)
unnamed: R813.1, R814.1, Term801.8
unnamed: R813.2, R814.2, U804.5 (Out)
unnamed: R815.1, R816.1, Term801.9
unnamed: R815.2, R816.2, U804.7 (Out)
VPower: Term801.1, U801.6 (VPower), U802.6 (VPower), U803.6 (VPower), U804.6 (VPower)

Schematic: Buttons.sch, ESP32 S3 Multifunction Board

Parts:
C901, C906: .1 uf; C_0603; Mouser Part Number 710-885012206095
C902, C903, C904, C905, C907, C908, C909, C910: 10 nf; C_0603; Mouser Part Number 710-885382206002
R901, R902, R903, R904, R905, R906, R907, R908: 10K Ohms; R_0603; Mouser Part Number 71-CRCW060310K0JNEBC
Term901: GND 8 7 6 5 4 3 2 1; TerminalBlock_Pheonix_MPT-2.54mm_9pol; Mouser Part Number 651-1725724
U901: 74HCT14; SOIC-14_3.9x8.7mm_Pitch1.27mm
U902: 74HCT14; SOIC-14_3.9x8.7mm_Pitch1.27mm; Mouser Part Number 595-CD74HC14M

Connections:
/Buttons/Button1: U902.6; also elsewhere on the board
/Buttons/Button2: U902.8; also elsewhere on the board
/Buttons/Button3: U902.10; also elsewhere on the board
/Buttons/Button4: U902.12; also elsewhere on the board
/Buttons/Button5: U901.6; also elsewhere on the board
/Buttons/Button6: U901.8; also elsewhere on the board
/Buttons/Button7: U901.10; also elsewhere on the board
/Buttons/Button8: U901.12; also elsewhere on the board
GND: C901.2, C902.2, C903.2, C904.2, C905.2, C906.2, C907.2, C908.2, C909.2, C910.2, Term901.9, U901.1, U901.3, U901.7 (GND), U902.1, U902.3, U902.7 (GND); also elsewhere on the board
unnamed: C902.1, R901.2, Term901.7, U901.11
unnamed: C903.1, R902.2, Term901.8, U901.13
unnamed: C904.1, R903.2, Term901.5, U901.5
unnamed: C905.1, R904.2, Term901.6, U901.9
unnamed: C907.1, R905.2, Term901.1, U902.5
unnamed: C908.1, R906.2, Term901.2, U902.9
unnamed: C909.1, R907.2, Term901.4, U902.13
unnamed: C910.1, R908.2, Term901.3, U902.11

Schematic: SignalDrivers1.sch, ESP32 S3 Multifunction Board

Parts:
C1001: .1 uf; C_0603; Mouser Part Number 710-885012206095
D1001: DFLS240-7; D_PowerDI-123; Mouser Part Number 621-DFLS240-7
JP1001, JP1002, JP1003, JP1004, JP1005, JP1006, JP1007, JP1008: 0; R_1206; Mouser Part Number 71-CRCW12060000Z0EBC
P1001: A7 A6 A5 A4 A3 A2 A1 A0 C; TerminalBlock_Pheonix_MPT-2.54mm_9pol; Mouser Part Number 651-1725724
P1002: B7 B6 B5 B4 B3 B2 B1 B0 C; TerminalBlock_Pheonix_MPT-2.54mm_9pol; Mouser Part Number 651-1725724
RP1001, RP1002: 1.5K Ohms; 4816P; Mouser Part Number 652-4816P-T1LF-1.5K
T1001: + 12V -; TerminalBlock_Pheonix_MPT-2.54mm_2pol; Mouser Part Number 651-1725656
U1001: PCA9685; TSSOP-28_4.4x9.7mm_Pitch0.65mm; Mouser Part Number 771-PCA9685PW,118
U1002, U1003: TBD62X83A; SOIC-18W_7.5x11.6mm_Pitch1.27mm; Mouser Part Number 757-TBD62083AFG or 757-TBD62783AFG

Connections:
+12V: D1001.1 (K), JP1001.2, JP1004.1, JP1005.2, JP1008.1, T1001.1; also elsewhere on the board
/MCU/SCL: U1001.26 (SCL); also elsewhere on the board
/MCU/SDA: U1001.27 (SDA); also elsewhere on the board
CAN +12V: D1001.2 (A); also elsewhere on the board
GND: C1001.2, JP1002.2, JP1003.1, JP1006.2, JP1007.1, T1001.2, U1001.1 (A0), U1001.2 (A1), U1001.3 (A2), U1001.4 (A3), U1001.5 (A4), U1001.14 (Vss), U1001.23 (OE), U1001.24 (A5), U1001.25 (ExtCLK); also elsewhere on the board
unnamed: JP1001.1, JP1003.2, P1001.9, U1002.10 (OC)
unnamed: JP1002.1, JP1004.2, U1002.9 (IC)
unnamed: JP1005.1, JP1007.2, P1002.9, U1003.10 (OC)
unnamed: JP1006.1, JP1008.2, U1003.9 (IC)
unnamed: P1001.1, RP1001.16 (R1.2)
unnamed: P1001.2, RP1001.15 (R2.2)
unnamed: P1001.3, RP1001.14 (R3.2)
unnamed: P1001.4, RP1001.13 (R4.2)
unnamed: P1001.5, RP1001.12 (R5.2)
unnamed: P1001.6, RP1001.11 (R6.2)
unnamed: P1001.7, RP1001.10 (R7.2)
unnamed: P1001.8, RP1001.9 (R8.2)
unnamed: P1002.1, RP1002.16 (R1.2)
unnamed: P1002.2, RP1002.15 (R2.2)
unnamed: P1002.3, RP1002.14 (R3.2)
unnamed: P1002.4, RP1002.13 (R4.2)
unnamed: P1002.5, RP1002.12 (R5.2)
unnamed: P1002.6, RP1002.11 (R6.2)
unnamed: P1002.7, RP1002.10 (R7.2)
unnamed: P1002.8, RP1002.9 (R8.2)
unnamed: RP1001.1 (R1.1), U1002.18 (Out)
unnamed: RP1001.2 (R2.1), U1002.17 (Out)
unnamed: RP1001.3 (R3.1), U1002.16 (Out)
unnamed: RP1001.4 (R4.1), U1002.15 (Out)
unnamed: RP1001.5 (R5.1), U1002.14 (Out)
unnamed: RP1001.6 (R6.1), U1002.13 (Out)
unnamed: RP1001.7 (R7.1), U1002.12 (Out)
unnamed: RP1001.8 (R8.1), U1002.11 (Out)
unnamed: RP1002.1 (R1.1), U1003.18 (Out)
unnamed: RP1002.2 (R2.1), U1003.17 (Out)
unnamed: RP1002.3 (R3.1), U1003.16 (Out)
unnamed: RP1002.4 (R4.1), U1003.15 (Out)
unnamed: RP1002.5 (R5.1), U1003.14 (Out)
unnamed: RP1002.6 (R6.1), U1003.13 (Out)
unnamed: RP1002.7 (R7.1), U1003.12 (Out)
unnamed: RP1002.8 (R8.1), U1003.11 (Out)
unnamed: U1001.6 (LED0), U1002.8 (In)
unnamed: U1001.7 (LED1), U1002.7 (In)
unnamed: U1001.8 (LED2), U1002.6 (In)
unnamed: U1001.9 (LED3), U1002.5 (In)
unnamed: U1001.10 (LED4), U1002.4 (In)
unnamed: U1001.11 (LED5), U1002.3 (In)
unnamed: U1001.12 (LED6), U1002.2 (In)
unnamed: U1001.13 (LED7), U1002.1 (In)
unnamed: U1001.15 (LED8), U1003.8 (In)
unnamed: U1001.16 (LED9), U1003.7 (In)
unnamed: U1001.17 (LED10), U1003.6 (In)
unnamed: U1001.18 (LED11), U1003.5 (In)
unnamed: U1001.19 (LED12), U1003.4 (In)
unnamed: U1001.20 (LED13), U1003.3 (In)
unnamed: U1001.21 (LED14), U1003.2 (In)
unnamed: U1001.22 (LED15), U1003.1 (In)

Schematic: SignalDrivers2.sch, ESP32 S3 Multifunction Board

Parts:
C1101: .1 uf; C_0603; Mouser Part Number 710-885012206095
JP1101, JP1102, JP1103, JP1104, JP1105, JP1106, JP1107, JP1108: 0; R_1206; Mouser Part Number 71-CRCW12060000Z0EBC
P1101: C7 C6 C5 C4 C3 C2 C1 C0 C; TerminalBlock_Pheonix_MPT-2.54mm_9pol; Mouser Part Number 651-1725724
P1102: D7 D6 D5 D4 D3 D2 D1 D0 C; TerminalBlock_Pheonix_MPT-2.54mm_9pol; Mouser Part Number 651-1725724
R1101: 10K; R_0402
RP1101, RP1102: 1.5K Ohms; 4816P; Mouser Part Number 652-4816P-T1LF-1.5K
U1101: PCA9685; TSSOP-28_4.4x9.7mm_Pitch0.65mm; Mouser Part Number 771-PCA9685PW,118
U1102, U1103: TBD62X83A; SOIC-18W_7.5x11.6mm_Pitch1.27mm; Mouser Part Number 757-TBD62083AFG or 757-TBD62783AFG

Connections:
+12V: JP1101.2, JP1104.1, JP1105.2, JP1108.1; also elsewhere on the board
/MCU/SCL: U1101.26 (SCL); also elsewhere on the board
/MCU/SDA: U1101.27 (SDA); also elsewhere on the board
GND: C1101.2, JP1102.2, JP1103.1, JP1106.2, JP1107.1, U1101.2 (A1), U1101.3 (A2), U1101.4 (A3), U1101.5 (A4), U1101.14 (Vss), U1101.23 (OE), U1101.24 (A5), U1101.25 (ExtCLK); also elsewhere on the board
unnamed: JP1101.1, JP1103.2, P1101.9, U1102.10 (OC)
unnamed: JP1102.1, JP1104.2, U1102.9 (IC)
unnamed: JP1105.1, JP1107.2, P1102.9, U1103.10 (OC)
unnamed: JP1106.1, JP1108.2, U1103.9 (IC)
unnamed: P1101.1, RP1101.16 (R1.2)
unnamed: P1101.2, RP1101.15 (R2.2)
unnamed: P1101.3, RP1101.14 (R3.2)
unnamed: P1101.4, RP1101.13 (R4.2)
unnamed: P1101.5, RP1101.12 (R5.2)
unnamed: P1101.6, RP1101.11 (R6.2)
unnamed: P1101.7, RP1101.10 (R7.2)
unnamed: P1101.8, RP1101.9 (R8.2)
unnamed: P1102.1, RP1102.16 (R1.2)
unnamed: P1102.2, RP1102.15 (R2.2)
unnamed: P1102.3, RP1102.14 (R3.2)
unnamed: P1102.4, RP1102.13 (R4.2)
unnamed: P1102.5, RP1102.12 (R5.2)
unnamed: P1102.6, RP1102.11 (R6.2)
unnamed: P1102.7, RP1102.10 (R7.2)
unnamed: P1102.8, RP1102.9 (R8.2)
unnamed: R1101.1, U1101.1 (A0)
unnamed: RP1101.1 (R1.1), U1102.18 (Out)
unnamed: RP1101.2 (R2.1), U1102.17 (Out)
unnamed: RP1101.3 (R3.1), U1102.16 (Out)
unnamed: RP1101.4 (R4.1), U1102.15 (Out)
unnamed: RP1101.5 (R5.1), U1102.14 (Out)
unnamed: RP1101.6 (R6.1), U1102.13 (Out)
unnamed: RP1101.7 (R7.1), U1102.12 (Out)
unnamed: RP1101.8 (R8.1), U1102.11 (Out)
unnamed: RP1102.1 (R1.1), U1103.18 (Out)
unnamed: RP1102.2 (R2.1), U1103.17 (Out)
unnamed: RP1102.3 (R3.1), U1103.16 (Out)
unnamed: RP1102.4 (R4.1), U1103.15 (Out)
unnamed: RP1102.5 (R5.1), U1103.14 (Out)
unnamed: RP1102.6 (R6.1), U1103.13 (Out)
unnamed: RP1102.7 (R7.1), U1103.12 (Out)
unnamed: RP1102.8 (R8.1), U1103.11 (Out)
unnamed: U1101.6 (LED0), U1102.8 (In)
unnamed: U1101.7 (LED1), U1102.7 (In)
unnamed: U1101.8 (LED2), U1102.6 (In)
unnamed: U1101.9 (LED3), U1102.5 (In)
unnamed: U1101.10 (LED4), U1102.4 (In)
unnamed: U1101.11 (LED5), U1102.3 (In)
unnamed: U1101.12 (LED6), U1102.2 (In)
unnamed: U1101.13 (LED7), U1102.1 (In)
unnamed: U1101.15 (LED8), U1103.8 (In)
unnamed: U1101.16 (LED9), U1103.7 (In)
unnamed: U1101.17 (LED10), U1103.6 (In)
unnamed: U1101.18 (LED11), U1103.5 (In)
unnamed: U1101.19 (LED12), U1103.4 (In)
unnamed: U1101.20 (LED13), U1103.3 (In)
unnamed: U1101.21 (LED14), U1103.2 (In)
unnamed: U1101.22 (LED15), U1103.1 (In)

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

Board: 2 copper layers, 156.2 x 168.9 mm, 230 parts (0 on the bottom side), 283 nets.

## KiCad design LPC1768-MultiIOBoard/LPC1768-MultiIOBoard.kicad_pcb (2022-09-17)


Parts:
FD101, FD102, FD103: Fiduciary Mark; Fiducial_classic_Small_SilkscreenTop_Type1
MK101, MK102, MK103, MK104: Mounting_Hole; MountingHole_3.2mm_M3

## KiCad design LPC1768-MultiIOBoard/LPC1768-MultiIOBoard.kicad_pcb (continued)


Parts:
C201, C203, C205, C207, C209: 1uf; C_0603
C202, C204, C206, C208, C210, C212, C214: 100nf; C_0402
C211, C213: 10uf; C_POL_1206
C215, C216: 18pf; C_0402; Mouser Part Number 81-GCM1555C1H180JA6J
D201: ACT1; LED_0402
D202: ACT2; LED_0402
IC201: LPC1768FBD100K; QFP50P1600X1600X160-100N; Manufacturer_Part_Number LPC1768FBD100K
J201: ARM-20-JTAG; IDC_Header_Straight_20pins
R201: 10K; R_0402
R202, R203: 270; R_0402
R204: 0; R_0402
SW201: RESET; SW_SPST_B3U-1000P-B; Mouser Part Number 653-B3U-1000P-B
Y201: 25Mhz; Crystal_SMD_Abracon_ABM8G-4pin_3.2x2.5mm; Mouser Part Number 815-ABM8G-25-4YT3

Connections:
/CAN Transceiver/CAN_RX: IC201.46 (P0[0]/RD1/TXD3/SDA1); also elsewhere on the board
/CAN Transceiver/CAN_TX: IC201.47 (P0[1]/TD1/RXD3/SCL1); also elsewhere on the board
/Micro Processor Unit/C0P0B0: IC201.26 (P3[26]/STCLK/_MAT0[1]/PWM1[3]); also elsewhere on the board
/Micro Processor Unit/C0P0B1: IC201.27 (P3[25]/MAT0[0]/_PWM1[2]); also elsewhere on the board
/Micro Processor Unit/C0P0B2: IC201.29 (P0[29]/USB_D+); also elsewhere on the board
/Micro Processor Unit/C0P0B3: IC201.30 (P0[30]/USB_D-); also elsewhere on the board
/Micro Processor Unit/C0P0B4: IC201.32 (P1[18]/USB_UP_LED/PWM1[1]/CAP1[0]); also elsewhere on the board
/Micro Processor Unit/C0P0B5: IC201.33 (P1[19]/MCOA0/~USB_PPWR~/CAP1[1]); also elsewhere on the board
/Micro Processor Unit/C0P0B6: IC201.34 (P1[20]/MCI0/_PWM1[2]/SCK0); also elsewhere on the board
/Micro Processor Unit/C0P0B7: IC201.35 (P1[21]/~MCABORT~/PWM1[3]/SSEL0); also elsewhere on the board
/Micro Processor Unit/C0P1B0: IC201.36 (P1[22]/MCOB0/USB_PWRD/MAT1[0]); also elsewhere on the board
/Micro Processor Unit/C0P1B1: IC201.37 (P1[23]/MCI1/PWM1[4]/MISO0); also elsewhere on the board
/Micro Processor Unit/C0P1B2: IC201.38 (P1[24]/MCI2/PWM1[5]/MOSI0); also elsewhere on the board
/Micro Processor Unit/C0P1B3: IC201.39 (P1[25]/MCOA1/MAT1[1]); also elsewhere on the board
/Micro Processor Unit/C0P1B4: IC201.40 (P1[26]/MCOB1/PWM1[6]/CAP0[0]); also elsewhere on the board
/Micro Processor Unit/C0P1B5: IC201.43 (P1[27]/CLKOUT/~USB_OVRCR~/CAP0[1]); also elsewhere on the board
/Micro Processor Unit/C0P1B6: IC201.44 (P1[28]/MCOA2/PCAP1[0]/MAT0[0]); also elsewhere on the board
/Micro Processor Unit/C0P1B7: IC201.45 (P1[29]/MCOB2/PCAP1[1]/MAT0[1]); also elsewhere on the board
/Micro Processor Unit/C0P2B0: IC201.48 (P0[10]/TXD2/SDA2/MAT3[0]); also elsewhere on the board
/Micro Processor Unit/C0P2B1: IC201.49 (P0[11]/RXD2/SCL2/MAT3[1]); also elsewhere on the board
/Micro Processor Unit/C0P2B2: IC201.50 (P2[13]/~EINT3~/_I2STX_SDA); also elsewhere on the board
/Micro Processor Unit/C0P2B3: IC201.51 (P2[12]/~EINT2~/_I2STX_WS); also elsewhere on the board
/Micro Processor Unit/C0P2B4: IC201.52 (P2[11]/~EINT1~/_I2STX_CLK); also elsewhere on the board
/Micro Processor Unit/C0P2B5: IC201.53 (P2[10]/~EINT0~/NMI); also elsewhere on the board
/Micro Processor Unit/C0P2B6: IC201.56 (P0[22]/RTS1/TD1); also elsewhere on the board
/Micro Processor Unit/C0P2B7: IC201.57 (P0[21]/RI1/RD1); also elsewhere on the board
/Micro Processor Unit/C1P0B0: IC201.85 (P4[29]/TX_MCLK/_MAT2[1]/RXD3); also elsewhere on the board
/Micro Processor Unit/C1P0B1: IC201.82 (P4[28]/RX_MCLK/_MAT2[0]/TXD3); also elsewhere on the board
/Micro Processor Unit/C1P0B2: IC201.81 (P0[4]/I2SRX_CLK/RD2/CAP2[0]); also elsewhere on the board
/Micro Processor Unit/C1P0B3: IC201.80 (P0[5]/I2SRX_WS/TD2/CAP2[1]); also elsewhere on the board
/Micro Processor Unit/C1P0B4: IC201.79 (P0[6]/I2SRX_SDA/SSEL1/MAT2[0]); also elsewhere on the board
/Micro Processor Unit/C1P0B5: IC201.78 (P0[7]/I2STX_CLK/SCK1/MAT2[1]); also elsewhere on the board
/Micro Processor Unit/C1P0B6: IC201.77 (P0[8]/I2STX_WS/MISO1/MAT2[2]); also elsewhere on the board
/Micro Processor Unit/C1P0B7: IC201.76 (P0[9]/I2STX_SDA/MOSI1/MAT2[3]); also elsewhere on the board
/Micro Processor Unit/C1P1B0: IC201.75 (P2[0]/PWM1[1]/TXD1); also elsewhere on the board
/Micro Processor Unit/C1P1B1: IC201.74 (P2[1]/PWM1[2]/RXD1); also elsewhere on the board
/Micro Processor Unit/C1P1B2: IC201.73 (P2[2]/PWM1[3]/CTS1/TRACEDATA[3]); also elsewhere on the board
/Micro Processor Unit/C1P1B3: IC201.70 (P2[3]/PWM1[4]/DCD1/TRACEDATA[2]); also elsewhere on the board
/Micro Processor Unit/C1P1B4: IC201.69 (P2[4]/PWM1[5]/DSR1/TRACEDATA[1]); also elsewhere on the board
/Micro Processor Unit/C1P1B5: IC201.68 (P2[5]/PWM1[6]/DTR1/TRACEDATA[0]); also elsewhere on the board
/Micro Processor Unit/C1P1B6: IC201.67 (P2[6]/PCAP1[0]/RI1/TRACECLK); also elsewhere on the board
/Micro Processor Unit/C1P1B7: IC201.66 (P2[7]/RD2/RTS1); also elsewhere on the board
/Micro Processor Unit/C1P2B0: IC201.65 (P2[8]/TD2/TXD2); also elsewhere on the board
/Micro Processor Unit/C1P2B1: IC201.64 (P2[9]/USB_CONNECT/RXD2); also elsewhere on the board
/Micro Processor Unit/C1P2B2: IC201.63 (P0[16]/RXD1/_SSEL0/SSEL); also elsewhere on the board
/Micro Processor Unit/C1P2B3: IC201.62 (P0[15]/TXD1/SCK0/SCK); also elsewhere on the board
/Micro Processor Unit/C1P2B4: IC201.61 (P0[17]/CTS1/MISO0/MISO); also elsewhere on the board
/Micro Processor Unit/C1P2B5: IC201.60 (P0[18]/DCD1/MOSI0/MOSI); also elsewhere on the board
/Micro Processor Unit/C1P2B6: IC201.59 (P0[19]/DSR1/SDA1); also elsewhere on the board
/Micro Processor Unit/C1P2B7: IC201.58 (P0[20]/DTR1/SCL1); also elsewhere on the board
GND: C201.2, C202.2, C203.2, C204.2, C205.2, C206.2, C207.2, C208.2, C209.2, C210.2, C211.2, C212.2, C213.2, C214.2, C215.2, C216.2, IC201.11 (VSSA), IC201.31 (VSS_1), IC201.41 (VSS_2), IC201.55 (VSS_3), IC201.72 (VSS_4), IC201.83 (VSS_5), IC201.97 (VSS_6), J201.4, J201.6, J201.8, J201.10, J201.12, J201.14, J201.16, J201.18, J201.20, SW201.1, Y201.2, Y201.4; also elsewhere on the board
unnamed: C209.1, IC201.17 (~RESET), R201.2, SW201.2
unnamed: C215.1, IC201.22 (XTAL1), Y201.1
unnamed: C216.1, IC201.23 (XTAL2), Y201.3
unnamed: D201.1 (K), IC201.24 (P0[28]/SCL0/USB_SCL)
unnamed: D201.2 (A), R202.1
unnamed: D202.1 (K), IC201.25 (P0[27]/SDA0/USB_SDA)
unnamed: D202.2 (A), R203.1
unnamed: IC201.1 (TDO/SWO), J201.13
unnamed: IC201.2 (TDI), J201.5
unnamed: IC201.3 (TMS/SWDIO), J201.7
unnamed: IC201.4 (~TRST), J201.3
unnamed: IC201.5 (TCK/SWDCLK), J201.9
unnamed: J201.1, R204.1


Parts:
C301: .1 uf; C_0603; Mouser Part Number 710-885012206095
C302: 15 uf 15V; CP_Elec_4x5.7; Mouser Part Number 647-UUD1C150MCL
C303: 47 nf; C_0603; Mouser Part Number 710-885012206093
D301, D302: DFLS240-7; D_PowerDI-123; Mouser Part Number 621-DFLS240-7
J301, J302: RJ45; RJ45_8N-S; Mouser Part Number 710-615008144221
JP301: Termination; Pin_Header_Straight_2x02_Pitch2.54mm; Mouser Part Number 649-67997-404HLF
R301, R302: 60 Ohms; R_1206; Mouser Part Number 71-CRCW120660R0KNAIF
T301: - 15 in +; TerminalBlock_Pheonix_MPT-2.54mm_2pol; Mouser Part Number 651-1725656
T302: - 15 out +; TerminalBlock_Pheonix_MPT-2.54mm_2pol; Mouser Part Number 651-1725656
U301: TCAN332DR; SOIC-8_3.9x4.9mm_Pitch1.27mm; Mouser Part Number 595-TCAN332DR

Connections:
/CAN Transceiver/CANH: J301.1, J302.1, R301.1, U301.7 (CANH)
/CAN Transceiver/CANL: J301.2, J302.2, R302.1, U301.6 (CANL)
/CAN Transceiver/CAN_RX: U301.4 (R); also elsewhere on the board
/CAN Transceiver/CAN_TX: U301.1 (D); also elsewhere on the board
CAN +12V: D301.1 (K), D302.2 (A), J301.8, J302.8; also elsewhere on the board
GND: C301.2, C302.2, C303.2, J301.3, J301.6, J301.7, J302.3, J302.6, J302.7, T301.2, T302.2, U301.2 (GND); also elsewhere on the board
unnamed: C303.1, JP301.3, JP301.4
unnamed: D301.2 (A), T301.1
unnamed: D302.1 (K), T302.1
unnamed: J301.4, J302.4
unnamed: J301.5, J302.5
unnamed: JP301.1, R301.2
unnamed: JP301.2, R302.2


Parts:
C401: 220 uf 25V; CP_Elec_8x10; Mouser Part Number 647-UWT1E221MNL1GS
C402: 22 uf 100V; CP_Elec_8x10; Mouser Part Number 647-UUX2A220MNL6GS
D401: POWER; LED_0402
D402: CMSH1-60 TR13; D_SMB; Mouser Part Number 610-CMSH1-60TR13
L401: 330 uh; SRN1060; Mouser Part Number 652-SRN1060-331M
R401: 330; R_0402
U401: LM2574N-3.3; SOIC-14_7.4x8.7mm_Pitch1.27mm; Mouser Part Number 926-LM2574MX33NOPB

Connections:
CAN +12V: C402.1, U401.10 (Vin); also elsewhere on the board
GND: C401.2, C402.2, D401.1 (K), D402.2 (A), U401.4 (SigGnd), U401.5 (Oh/Off), U401.6 (PwrGnd); also elsewhere on the board
unnamed: D401.2 (A), R401.1
unnamed: D402.1 (K), L401.1, U401.12 (Out)


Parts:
J501: - PWD +; TerminalBlock_Pheonix_MPT-2.54mm_2pol
J502: Outputs; Molex_KK_396_01x24_3.96mm_RightAngle; Mouser Part Number 538-26-48-1242
J503, J504, J505: Sink Source; Pin_Header_Straight_1x03_Pitch2.54mm
J506, J507, J508: Source Sink; Pin_Header_Straight_1x03_Pitch2.54mm
U501, U502, U503: TBD62X8X; DIP-18_W7.62mm; Mouser Part Number 571-1-2199298-5

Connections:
+VDC: J501.1, J503.3, J504.3, J505.3, J506.1, J507.1, J508.1
/Micro Processor Unit/C1P0B0: U501.1 (In); also elsewhere on the board
/Micro Processor Unit/C1P0B1: U501.2 (In); also elsewhere on the board
/Micro Processor Unit/C1P0B2: U501.3 (In); also elsewhere on the board
/Micro Processor Unit/C1P0B3: U501.4 (In); also elsewhere on the board
/Micro Processor Unit/C1P0B4: U501.5 (In); also elsewhere on the board
/Micro Processor Unit/C1P0B5: U501.6 (In); also elsewhere on the board
/Micro Processor Unit/C1P0B6: U501.7 (In); also elsewhere on the board
/Micro Processor Unit/C1P0B7: U501.8 (In); also elsewhere on the board
/Micro Processor Unit/C1P1B0: U502.1 (In); also elsewhere on the board
/Micro Processor Unit/C1P1B1: U502.2 (In); also elsewhere on the board
/Micro Processor Unit/C1P1B2: U502.3 (In); also elsewhere on the board
/Micro Processor Unit/C1P1B3: U502.4 (In); also elsewhere on the board
/Micro Processor Unit/C1P1B4: U502.5 (In); also elsewhere on the board
/Micro Processor Unit/C1P1B5: U502.6 (In); also elsewhere on the board
/Micro Processor Unit/C1P1B6: U502.7 (In); also elsewhere on the board
/Micro Processor Unit/C1P1B7: U502.8 (In); also elsewhere on the board
/Micro Processor Unit/C1P2B0: U503.1 (In); also elsewhere on the board
/Micro Processor Unit/C1P2B1: U503.2 (In); also elsewhere on the board
/Micro Processor Unit/C1P2B2: U503.3 (In); also elsewhere on the board
/Micro Processor Unit/C1P2B3: U503.4 (In); also elsewhere on the board
/Micro Processor Unit/C1P2B4: U503.5 (In); also elsewhere on the board
/Micro Processor Unit/C1P2B5: U503.6 (In); also elsewhere on the board
/Micro Processor Unit/C1P2B6: U503.7 (In); also elsewhere on the board
/Micro Processor Unit/C1P2B7: U503.8 (In); also elsewhere on the board
GND: J501.2, J503.1, J504.1, J505.1, J506.3, J507.3, J508.3; also elsewhere on the board
unnamed: J502.1, U501.18 (Out)
unnamed: J502.2, U501.17 (Out)
unnamed: J502.3, U501.16 (Out)
unnamed: J502.4, U501.15 (Out)
unnamed: J502.5, U501.14 (Out)
unnamed: J502.6, U501.13 (Out)
unnamed: J502.7, U501.12 (Out)
unnamed: J502.8, U501.11 (Out)
unnamed: J502.9, U502.18 (Out)
unnamed: J502.10, U502.17 (Out)
unnamed: J502.11, U502.16 (Out)
unnamed: J502.12, U502.15 (Out)
unnamed: J502.13, U502.14 (Out)
unnamed: J502.14, U502.13 (Out)
unnamed: J502.15, U502.12 (Out)
unnamed: J502.16, U502.11 (Out)
unnamed: J502.17, U503.18 (Out)
unnamed: J502.18, U503.17 (Out)
unnamed: J502.19, U503.16 (Out)
unnamed: J502.20, U503.15 (Out)
unnamed: J502.21, U503.14 (Out)
unnamed: J502.22, U503.13 (Out)
unnamed: J502.23, U503.12 (Out)
unnamed: J502.24, U503.11 (Out)
unnamed: J503.2, U503.10 (OC)
unnamed: J504.2, U502.10 (OC)
unnamed: J505.2, U501.10 (OC)
unnamed: J506.2, U503.9 (IC)
unnamed: J507.2, U501.9 (IC)
unnamed: J508.2, U502.9 (IC)


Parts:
C601, C602, C603, C604, C605, C606, C607, C608, C609, C610, C611, C612, C613, C614, C615, C616, C617, C618, C619, C620, C621, C622, C623, C624: C; C_Disc_D3.8mm_W2.6mm_P2.50mm
J601: Inputs; Molex_KK_396_01x24_3.96mm_RightAngle; Mouser Part Number 538-26-48-1242
R601, R602, R603, R604, R605, R606, R607, R608, R609, R610, R611, R612, R613, R614, R615, R616, R617, R618, R619, R620, R621, R622, R623, R624: 0; R_Axial_DIN0207_L6.3mm_D2.5mm_P10.16mm_Horizontal_WJumper

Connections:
/Micro Processor Unit/C0P0B0: R601.2; also elsewhere on the board
/Micro Processor Unit/C0P0B1: R602.2; also elsewhere on the board
/Micro Processor Unit/C0P0B2: R603.2; also elsewhere on the board
/Micro Processor Unit/C0P0B3: R604.2; also elsewhere on the board
/Micro Processor Unit/C0P0B4: R605.2; also elsewhere on the board
/Micro Processor Unit/C0P0B5: R606.2; also elsewhere on the board
/Micro Processor Unit/C0P0B6: R607.2; also elsewhere on the board
/Micro Processor Unit/C0P0B7: R608.2; also elsewhere on the board
/Micro Processor Unit/C0P1B0: R609.2; also elsewhere on the board
/Micro Processor Unit/C0P1B1: R610.2; also elsewhere on the board
/Micro Processor Unit/C0P1B2: R611.2; also elsewhere on the board
/Micro Processor Unit/C0P1B3: R612.2; also elsewhere on the board
/Micro Processor Unit/C0P1B4: R613.2; also elsewhere on the board
/Micro Processor Unit/C0P1B5: R614.2; also elsewhere on the board
/Micro Processor Unit/C0P1B6: R615.2; also elsewhere on the board
/Micro Processor Unit/C0P1B7: R616.2; also elsewhere on the board
/Micro Processor Unit/C0P2B0: R617.2; also elsewhere on the board
/Micro Processor Unit/C0P2B1: R618.2; also elsewhere on the board
/Micro Processor Unit/C0P2B2: R619.2; also elsewhere on the board
/Micro Processor Unit/C0P2B3: R620.2; also elsewhere on the board
/Micro Processor Unit/C0P2B4: R621.2; also elsewhere on the board
/Micro Processor Unit/C0P2B5: R622.2; also elsewhere on the board
/Micro Processor Unit/C0P2B6: R623.2; also elsewhere on the board
/Micro Processor Unit/C0P2B7: R624.2; also elsewhere on the board
GND: C601.2, C602.2, C603.2, C604.2, C605.2, C606.2, C607.2, C608.2, C609.2, C610.2, C611.2, C612.2, C613.2, C614.2, C615.2, C616.2, C617.2, C618.2, C619.2, C620.2, C621.2, C622.2, C623.2, C624.2; also elsewhere on the board
unnamed: C601.1, J601.20, R620.1
unnamed: C602.1, J601.10, R610.1
unnamed: C603.1, J601.19, R619.1
unnamed: C604.1, J601.9, R609.1
unnamed: C605.1, J601.8, R608.1
unnamed: C606.1, J601.18, R618.1
unnamed: C607.1, J601.7, R607.1
unnamed: C608.1, J601.17, R617.1
unnamed: C609.1, J601.6, R606.1
unnamed: C610.1, J601.16, R616.1
unnamed: C611.1, J601.5, R605.1
unnamed: C612.1, J601.15, R615.1
unnamed: C613.1, J601.4, R604.1
unnamed: C614.1, J601.14, R614.1
unnamed: C615.1, J601.24, R624.1
unnamed: C616.1, J601.3, R603.1
unnamed: C617.1, J601.13, R613.1
unnamed: C618.1, J601.23, R623.1
unnamed: C619.1, J601.2, R602.1
unnamed: C620.1, J601.22, R622.1
unnamed: C621.1, J601.12, R612.1
unnamed: C622.1, J601.1, R601.1
unnamed: C623.1, J601.11, R611.1
unnamed: C624.1, J601.21, R621.1

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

Board: 2 copper layers, 141.0 x 146.0 mm, 113 parts (0 on the bottom side), 132 nets.

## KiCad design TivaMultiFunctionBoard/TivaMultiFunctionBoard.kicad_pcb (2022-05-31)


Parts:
D16: DFLS240-7; D_SMB; Mouser Part Number 621-DFLS240-7
J1: TI_BOOSTER_40_J1; SIL-10
J2: TI_BOOSTER_40_J2; SIL-10
J3: TI_BOOSTER_40_J3; SIL-10
J4: TI_BOOSTER_40_J4; SIL-10
J5: GPIO Header; IDC_Header_Straight_10pins
MK1, MK2, MK3: Mounting_Hole; MountingHole_3.2mm_M3
MK4: Mounting_Hole_PAD; MountingHole_3.2mm_M3_Pad
R27, R28: 2.4K; R_0603; Mouser Part Number 71-CRCW06032K40JN

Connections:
+5V: D16.2 (A); also elsewhere on the board
/Button1: J3.7 (3.07/PE1); also elsewhere on the board
/Button2: J3.8 (3.08/PE2); also elsewhere on the board
/Button3: J3.9 (3.09/PE3); also elsewhere on the board
/Button4: J3.10 (3.10/PF1); also elsewhere on the board
/CAN0RX: J1.5 (1.05/PE4); also elsewhere on the board
/CAN0TX: J1.6 (1.06/PE5); also elsewhere on the board
/LED1: J3.3 (3.03/PD0); also elsewhere on the board
/LED2: J3.4 (3.04/PD1); also elsewhere on the board
/LED3: J3.5 (3.05/PD2); also elsewhere on the board
/LED4: J3.6 (3.06/PD3); also elsewhere on the board
/Motor1: J4.5 (4.05/PC5); also elsewhere on the board
/Motor2: J4.6 (4.06/PC6); also elsewhere on the board
/Motor3: J4.7 (4.07/PC7); also elsewhere on the board
/Motor4: J4.8 (4.08/PD6); also elsewhere on the board
/OD1: J4.9 (4.09/PD7); also elsewhere on the board
/OD2: J4.10 (4.10/PF4); also elsewhere on the board
/OD3: J1.8 (1.08/PA5); also elsewhere on the board
/OD4: J2.2 (2.02/PB2); also elsewhere on the board
/Points1: J4.1 (4.01/PF2); also elsewhere on the board
/Points2: J4.2 (4.02/PF3); also elsewhere on the board
/Points3: J4.3 (4.03/PB3); also elsewhere on the board
/Points4: J4.4 (4.04/PC4); also elsewhere on the board
/SCL: J1.9 (1.09/PA6), R27.1; also elsewhere on the board
/SDA: J1.10 (1.10/PA7), R28.1; also elsewhere on the board
GND: J2.1 (2.01/GND), J3.2 (3.02/GND), J5.6; also elsewhere on the board
unnamed: D16.1 (K), J3.1 (3.01/+5V)
unnamed: J1.7 (1.07/PB4), J5.3
unnamed: J2.3 (2.03/PE0), J5.1
unnamed: J2.4 (2.04/PF0), J5.2
unnamed: J2.6 (2.06/PB7), J5.4
unnamed: J2.7 (2.07/PB6), J5.7
unnamed: J2.8 (2.08/PA4), J5.8
unnamed: J2.9 (2.09/PA3), J5.9
unnamed: J2.10 (2.10/PA2), J5.10

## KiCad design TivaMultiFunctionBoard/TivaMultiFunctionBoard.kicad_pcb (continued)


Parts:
C1: .1 uf; C_0603; Mouser Part Number 710-885012206095
C2: 15 uf 15V; CP_Elec_4x5.7; Mouser Part Number 647-UUD1C150MCL
C3: 47 nf; C_0603; Mouser Part Number 710-885012206093
D1, D2: DFLS240-7; D_SMB; Mouser Part Number 621-DFLS240-7
J6, J7: RJ45; RJ45_8N-S; Mouser Part Number 710-615008144221
JP1: Termination; Pin_Header_Straight_2x02_Pitch2.54mm; Mouser Part Number 649-67997-404HLF
R1, R2: 60 Ohms; R_1206; Mouser Part Number 71-CRCW120660R0KNAIF
T1: - 15 in +; TerminalBlock_Pheonix_MPT-2.54mm_2pol; Mouser Part Number 651-1725656
T2: - 15 out +; TerminalBlock_Pheonix_MPT-2.54mm_2pol; Mouser Part Number 651-1725656
U1: TCAN332DR; SOIC-8_3.9x4.9mm_Pitch1.27mm; Mouser Part Number 595-TCAN332DR

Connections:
/CAN0RX: U1.4 (R); also elsewhere on the board
/CAN0TX: U1.1 (D); also elsewhere on the board
/CAN Transceiver/CANH: J6.1, J7.1, R1.1, U1.7 (CANH)
/CAN Transceiver/CANL: J6.2, J7.2, R2.1, U1.6 (CANL)
GND: C1.2, C2.2, C3.2, J6.3, J6.6, J6.7, J7.3, J7.6, J7.7, T1.2, T2.2, U1.2 (GND); also elsewhere on the board
unnamed: C3.1, JP1.3, JP1.4
unnamed: D1.2 (A), T1.1
unnamed: D2.1 (K), T2.1
unnamed: J6.4, J7.4
unnamed: J6.5, J7.5
unnamed: JP1.1, R1.2
unnamed: JP1.2, R2.2


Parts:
C4: 220 uf 25V; CP_Elec_8x10; Mouser Part Number 647-UWT1E221MNL1GS
C5: 22 uf 100V; CP_Elec_8x10; Mouser Part Number 647-UUX2A220MNL6GS
D3: CMSH1-60 TR13; D_SMB; Mouser Part Number 610-CMSH1-60TR13
L1: 330 uh; SRN1060; Mouser Part Number 652-SRN1060-331M
U3: LM2574N-5.0; SOIC-14_7.4x8.7mm_Pitch1.27mm; Mouser Part Number 926-LM2574N-5.0/NOPB

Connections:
+5V: C4.1, L1.2, U3.3 (FB); also elsewhere on the board
GND: C4.2, C5.2, D3.2 (A), U3.4 (SigGnd), U3.5 (Oh/Off), U3.6 (PwrGnd); also elsewhere on the board
unnamed: D3.1 (K), L1.1, U3.12 (Out)


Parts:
C601: .1 uf; C_0603; Mouser Part Number 710-885012206095
D601: DFLS240-7; D_SMB; Mouser Part Number 621-DFLS240-7
JP4, JP5, JP6, JP7, JP8, JP9, JP10, JP11: 0; R_1206; Mouser Part Number 71-CRCW12060000Z0EBC
P601: A7 A6 A5 A4 A3 A2 A1 A0 C; TerminalBlock_Pheonix_MPT-2.54mm_9pol; Mouser Part Number 651-1725724
P602: B7 B6 B5 B4 B3 B2 B1 B0 C; TerminalBlock_Pheonix_MPT-2.54mm_9pol; Mouser Part Number 651-1725724
RP601, RP602: 1.5K Ohms; 4816P; Mouser Part Number 652-4816P-T1LF-1.5K
T601: + 12V -; TerminalBlock_Pheonix_MPT-2.54mm_2pol; Mouser Part Number 651-1725656
U601: PCA9685; TSSOP-28_4.4x9.7mm_Pitch0.65mm; Mouser Part Number 771-PCA9685PW,118
U602, U603: TBD62X83A; SOIC-18W_7.5x11.6mm_Pitch1.27mm; Mouser Part Number 757-TBD62083AFG or 757-TBD62783AFG

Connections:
/PWM Driver/SignalV+: D601.1 (K), JP5.2, JP7.1, JP9.2, JP11.1, T601.1
/SCL: U601.26 (SCL); also elsewhere on the board
/SDA: U601.27 (SDA); also elsewhere on the board
GND: C601.2, JP4.2, JP6.1, JP8.2, JP10.1, T601.2, U601.1 (A0), U601.2 (A1), U601.3 (A2), U601.4 (A3), U601.5 (A4), U601.14 (Vss), U601.23 (OE), U601.24 (A5), U601.25 (ExtCLK); also elsewhere on the board
unnamed: JP4.1, JP7.2, U602.9 (IC)
unnamed: JP5.1, JP6.2, P601.9, U602.10 (OC)
unnamed: JP9.1, JP10.2, P602.9, U603.10 (OC)
unnamed: JP8.1, JP11.2, U603.9 (IC)
unnamed: P601.1, RP601.16 (R1.2)
unnamed: P601.2, RP601.15 (R2.2)
unnamed: P601.3, RP601.14 (R3.2)
unnamed: P601.4, RP601.13 (R4.2)
unnamed: P601.5, RP601.12 (R5.2)
unnamed: P601.6, RP601.11 (R6.2)
unnamed: P601.7, RP601.10 (R7.2)
unnamed: P601.8, RP601.9 (R8.2)
unnamed: P602.1, RP602.16 (R1.2)
unnamed: P602.2, RP602.15 (R2.2)
unnamed: P602.3, RP602.14 (R3.2)
unnamed: P602.4, RP602.13 (R4.2)
unnamed: P602.5, RP602.12 (R5.2)
unnamed: P602.6, RP602.11 (R6.2)
unnamed: P602.7, RP602.10 (R7.2)
unnamed: P602.8, RP602.9 (R8.2)
unnamed: RP601.1 (R1.1), U602.18 (Out)
unnamed: RP601.2 (R2.1), U602.17 (Out)
unnamed: RP601.3 (R3.1), U602.16 (Out)
unnamed: RP601.4 (R4.1), U602.15 (Out)
unnamed: RP601.5 (R5.1), U602.14 (Out)
unnamed: RP601.6 (R6.1), U602.13 (Out)
unnamed: RP601.7 (R7.1), U602.12 (Out)
unnamed: RP601.8 (R8.1), U602.11 (Out)
unnamed: RP602.1 (R1.1), U603.18 (Out)
unnamed: RP602.2 (R2.1), U603.17 (Out)
unnamed: RP602.3 (R3.1), U603.16 (Out)
unnamed: RP602.4 (R4.1), U603.15 (Out)
unnamed: RP602.5 (R5.1), U603.14 (Out)
unnamed: RP602.6 (R6.1), U603.13 (Out)
unnamed: RP602.7 (R7.1), U603.12 (Out)
unnamed: RP602.8 (R8.1), U603.11 (Out)
unnamed: U601.6 (LED0), U602.8 (In)
unnamed: U601.7 (LED1), U602.7 (In)
unnamed: U601.8 (LED2), U602.6 (In)
unnamed: U601.9 (LED3), U602.5 (In)
unnamed: U601.10 (LED4), U602.4 (In)
unnamed: U601.11 (LED5), U602.3 (In)
unnamed: U601.12 (LED6), U602.2 (In)
unnamed: U601.13 (LED7), U602.1 (In)
unnamed: U601.15 (LED8), U603.8 (In)
unnamed: U601.16 (LED9), U603.7 (In)
unnamed: U601.17 (LED10), U603.6 (In)
unnamed: U601.18 (LED11), U603.5 (In)
unnamed: U601.19 (LED12), U603.4 (In)
unnamed: U601.20 (LED13), U603.3 (In)
unnamed: U601.21 (LED14), U603.2 (In)
unnamed: U601.22 (LED15), U603.1 (In)


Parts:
C8, C9, C10, C11: 2.2uf 50V; CP_Elec_4x5.7; Mouser Part Number 710-865080140002
D4, D5, D6, D7, D8, D9, D10, D11: 1N4148; D_SOD-123; Mouser Part Number 750-1N4148WS-HF
D12, D13, D14, D15: LED; LED_0603; Mouser Part Number 710-150060SS55040
R3, R4, R5, R6: 22K Ohms; R_0603; Mouser Part Number 71-RCG060322K0JNEA
R7, R8, R9, R10: 1M Ohms; R_0603; Mouser Part Number 71-CRCW06031M00JNEAC
R11, R12, R13, R14: 2.7K Ohms; R_0603; Mouser Part Number 71-CRCW06032K70JNEAC
RV1, RV2, RV3, RV4: 25K Ohms; Potentiometer_Trimmer_Bourns_3214J; Mouser Part Number 652-3314J-1-253E
Term5: 4B 4A 3B 3A 2B 2A 1B 1A; TerminalBlock_Pheonix_MPT-2.54mm_8pol; Mouser Part Number 651-1725711
U9, U10: LM339; SOIC-14_3.9x8.7mm_Pitch1.27mm

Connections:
/OD1: D12.1 (K), U10.2; also elsewhere on the board
/OD2: D13.1 (K), U10.1; also elsewhere on the board
/OD3: D14.1 (K), U10.13; also elsewhere on the board
/OD4: D15.1 (K), U10.14; also elsewhere on the board
GND: C8.2, C9.2, C10.2, C11.2, RV1.1, RV2.1, RV3.1, RV4.1, U9.12 (V-), U10.12 (V-); also elsewhere on the board
unnamed: C8.1, R7.2, U9.2, U10.5 (+)
unnamed: C9.1, R8.2, U9.1, U10.7 (+)
unnamed: C10.1, R9.2, U9.13, U10.11 (+)
unnamed: C11.1, R10.2, U9.14, U10.9 (+)
unnamed: D4.1 (K), D8.2 (A), Term5.1, U9.4 (-)
unnamed: D4.2 (A), D8.1 (K), RV1.2, Term5.2
unnamed: D5.1 (K), D9.2 (A), Term5.3, U9.6 (-)
unnamed: D5.2 (A), D9.1 (K), RV2.2, Term5.4
unnamed: D6.2 (A), D10.1 (K), RV3.2, Term5.6
unnamed: D6.1 (K), D10.2 (A), Term5.5, U9.10 (-)
unnamed: D7.2 (A), D11.1 (K), RV4.2, Term5.8
unnamed: D7.1 (K), D11.2 (A), Term5.7, U9.8 (-)
unnamed: D12.2 (A), R11.2
unnamed: D13.2 (A), R12.2
unnamed: D14.2 (A), R13.2
unnamed: D15.2 (A), R14.2
unnamed: R3.2, RV1.3, U9.5 (+), U10.4 (-)
unnamed: R4.2, RV2.3, U9.7 (+), U10.6 (-)
unnamed: R5.2, RV3.3, U9.11 (+), U10.10 (-)
unnamed: R6.2, RV4.3, U9.9 (+), U10.8 (-)


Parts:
C6, C7: .1 uf; C_0603; Mouser Part Number 710-885012206095
RR1: 10K Ohms; 4814P; Mouser Part Number 652-4814P-2LF-10K
Term1: Motor 1; TerminalBlock_Pheonix_MPT-2.54mm_5pol; Mouser Part Number 651-1725685
Term2: Motor 2; TerminalBlock_Pheonix_MPT-2.54mm_5pol; Mouser Part Number 651-1725685
Term3: Motor 3; TerminalBlock_Pheonix_MPT-2.54mm_5pol; Mouser Part Number 651-1725685
Term4: Motor 4; TerminalBlock_Pheonix_MPT-2.54mm_5pol; Mouser Part Number 651-1725685
U2: 74HCT00; SOIC-14_3.9x8.7mm_Pitch1.27mm
U4: 74HCT00; SOIC-14_3.9x8.7mm_Pitch1.27mm; Mouser Part Number 595-SN74AHC00D
U5, U6, U7, U8: TC4428; SOIC-8_3.9x4.9mm_Pitch1.27mm; Mouser Part Number 579-TC4428VOA

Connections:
/Motor1: U5.2 (IN), U5.4 (IN); also elsewhere on the board
/Motor2: U6.2 (IN), U6.4 (IN); also elsewhere on the board
/Motor3: U7.2 (IN), U7.4 (IN); also elsewhere on the board
/Motor4: U8.2 (IN), U8.4 (IN); also elsewhere on the board
/Points1: U2.3, U2.4; also elsewhere on the board
/Points2: U2.8, U2.12; also elsewhere on the board
/Points3: U4.3, U4.4; also elsewhere on the board
/Points4: U4.8, U4.12; also elsewhere on the board
/Stall Motors/M1A: Term1.1, U5.5 (Out)
/Stall Motors/M1B: Term1.2, U5.7 (Out)
/Stall Motors/M2A: Term2.1, U6.5 (Out)
/Stall Motors/M2B: Term2.2, U6.7 (Out)
/Stall Motors/M3A: Term3.1, U7.5 (Out)
/Stall Motors/M3B: Term3.2, U7.7 (Out)
/Stall Motors/M4A: Term4.1, U8.5 (Out)
/Stall Motors/M4B: Term4.2, U8.7 (Out)
/Stall Motors/P1A: RR1.6 (R6), Term1.3, U2.1
/Stall Motors/P1B: RR1.5 (R5), Term1.5, U2.5
/Stall Motors/P2A: RR1.4 (R4), Term2.3, U2.9
/Stall Motors/P2B: RR1.3 (R3), Term2.5, U2.13
/Stall Motors/P3A: RR1.13 (R13), Term3.3, U4.1
/Stall Motors/P3B: RR1.12 (R12), Term3.5, U4.5
/Stall Motors/P4A: RR1.11 (R11), Term4.3, U4.9
/Stall Motors/P4B: RR1.10 (R10), Term4.5, U4.13
GND: C6.2, C7.2, Term1.4, Term2.4, Term3.4, Term4.4, U2.7 (GND), U4.7 (GND), U5.3 (GND), U6.3 (GND), U7.3 (GND), U8.3 (GND); also elsewhere on the board
unnamed: U2.2, U2.6
unnamed: U2.10, U2.11
unnamed: U4.2, U4.6
unnamed: U4.10, U4.11


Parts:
C12: .1 uf; C_0603
C13, C14, C15, C16: 10 nf; C_0603; Mouser Part Number 710-885382206002
R15, R17, R19, R21: R; R_Axial_DIN0207_L6.3mm_D2.5mm_P7.62mm_Horizontal
R16, R18, R20, R22: 1.5K Ohms; R_0603; Mouser Part Number 71-CRCW06031K50JNEAC
R23, R24, R25, R26: 10K Ohms; R_0603; Mouser Part Number 71-CRCW060310K0JNEBC
Term6: +V 1 2 3 4 GND; TerminalBlock_Pheonix_MPT-2.54mm_6pol; Mouser Part Number 651-1725698
Term7: 1 2 3 4 GND; TerminalBlock_Pheonix_MPT-2.54mm_5pol; Mouser Part Number 651-1725685
U11, U12: TC4426; SOIC-8_3.9x4.9mm_Pitch1.27mm
U13: 74HCT14; SOIC-14_3.9x8.7mm_Pitch1.27mm; Mouser Part Number 595-CD74HC14M
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

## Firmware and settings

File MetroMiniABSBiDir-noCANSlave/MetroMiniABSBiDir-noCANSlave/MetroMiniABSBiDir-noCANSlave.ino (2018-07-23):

// -!- C++ -!- //////////////////////////////////////////////////////////////
//
//  System        : 
//  Module        : 
//  Object Name   : $RCSfile$
//  Revision      : $Revision$
//  Date          : $Date$
//  Author        : $Author$
//  Created By    : Robert Heller
//  Created       : Tue Jun 12 22:08:01 2018
//  Last Modified : <180723.1341>
//
//  Description	
//
//  Notes
//
//  History
//	
/////////////////////////////////////////////////////////////////////////////
//
//    Copyright (C) 2018  Robert Heller D/B/A Deepwoods Software
//			51 Locke Hill Road
//			Wendell, MA 01379-9728
//
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
// 
//
//////////////////////////////////////////////////////////////////////////////

static const char rcsid[] = "@(#) : $Id$";

/**
 * MetroMiniABS.ino -- An OpenLCB node that implements a single Automatic Block
 * Signal.  This node presumes the hardware detailed at 
 * https://github.com/RobertPHeller/RPi-RRCircuits/tree/master/MetroMiniABS
 * This board uses an Adafruit Metro Mini, which is a Arduino Uno R3 clone on 
 * a mini form factor: 1.7"x.7", with 28 pins as two rows of 14 .6" with a .1" 
 * pitch (same footprint as a wide DIL-28).
 *
 * I/O pin usage:
 *
 * D0 (Rx)
 * D1 (Tx) ABS Slave Bus
 * D2 Common (low=Cathode, high=Anode) [DIP switch]
 * D3 (PWM) East Green
 * D4 Next West (Active Low)
 * D5 (PWM) East Yellow
 * D6 (PWM) East Red
 * D7 Next East (Active Low)
 * D8 Current Block (Active Low)
 * D9 (PWM) West Green
 * D10 (PWM) West Yellow
 * D11 (PWM) West Red
 * D12 BiColor Red/Green searchlight (low=descrete LEDS, high=BiColoer) [DIP switch]
 *
 * A0-A5 -- Dip Switch address bits [DIP switch]
 *
 * User onfiguration Options:
 * 
 * Compile Time Constants:
 * 
 * STOP_BRITE     -- Stop (red) brightness (0-255)
 * APPROACH_BRITE -- Approach (yellow) brightness (0-255)
 * CLEAR_BRITE    -- Clear (green) brightness (0-255)
 * YELLOW_HUE     -- Yellow Hue (ratio of red to green): 0-255
 *
 * Dip Switches:
 * 
 * Blockid        -- Block Id (0-63)
 * Common_Anode   -- Common Anode
 * BiColor_Search -- use BiColor Searchlight (Red/Green)
 * 
 */

#define STOP_BRITE 255     //  Stop (red) brightness (0-255)
#define APPROACH_BRITE 255 //  Approach (yellow) brightness (0-255)
#define CLEAR_BRITE 255    //  Clear (green) brightness (0-255)
#define YELLOW_HUE 128     //  Yellow Hue (ratio of red to green): 0-255

#include <Arduino.h>

#include <ctype.h>
#include <stdarg.h>
#include <stdio.h>
//#include <avr/pgmspace.h>

// The following lines are needed because the Arduino environment 
// won't search a library directory unless the library is included 
// from the top level file (this file)
//#include <EEPROM.h>
#include "GPIOState.h"
#include "Mast.h"
#include "ABSSlaveBus.h"

// init for serial communications if used
#define         BAUD_RATE       115200

// Define pins

// Dip Switch:

#define LEDCOMMONMODE  2
#define BICOLORSEARCH 12
#define BLOCKID0      A0
#define BLOCKID1      A1
#define BLOCKID2      A2
#define BLOCKID3      A3
#define BLOCKID4      A4
#define BLOCKID5      A5

uint8_t Blockid = 0;
uint8_t Common_Anode = 1;
uint8_t Bicolor_Search = 0;

// PWM Signal Leds
#define ESIGNALGREEN   3
#define ESIGNALYELLOW  5
#define ESIGNALRED     6
#define WSIGNALGREEN   9
#define WSIGNALYELLOW 10
#define WSIGNALRED    11

// Block Occupancy
#define BLOCKOCC       8 // Current block
#define NEXTEAST       7 // Next block east (via daisy chain)
#define NEXTWEST       4 // Next block west (via daisy chain)

// GPIO Pin Wrappers

// Block Occupancy
GPIOStateIn blockOcc(BLOCKOCC,LOW);
GPIOStateIn nextEast(NEXTEAST,LOW);
GPIOStateIn nextWest(NEXTWEST,LOW);

// Signal LEDS
GPIOStatePWMOut eastGreen(ESIGNALGREEN);
GPIOStatePWMOut eastYellow(ESIGNALYELLOW);
GPIOStatePWMOut eastRed(ESIGNALRED);
GPIOStatePWMOut westGreen(WSIGNALGREEN);
GPIOStatePWMOut westYellow(WSIGNALYELLOW);
GPIOStatePWMOut westRed(WSIGNALRED);

// Signal Masts 
Mast mastE(&blockOcc,&nextEast,&eastRed,&eastYellow,&eastGreen,
           STOP_BRITE,APPROACH_BRITE,CLEAR_BRITE,
           YELLOW_HUE);
Mast mastW(&blockOcc,&nextWest,&westRed,&westYellow,&westGreen,
           STOP_BRITE,APPROACH_BRITE,CLEAR_BRITE,
           YELLOW_HUE);

// ABS Slave Bus
ABSSlaveBus slaveBus(&blockOcc,
                     &eastGreen,&eastYellow,&eastRed,
                     &westGreen,&westYellow,&westRed);

/**
 * Setup does initial configuration
 */
void setup()
{
    // Set up the serial port
    Serial.begin(BAUD_RATE);
    // Read the DIP Switches
    pinMode(LEDCOMMONMODE,INPUT_PULLUP);
    pinMode(BICOLORSEARCH,INPUT_PULLUP);
    pinMode(BLOCKID0,INPUT_PULLUP);
    pinMode(BLOCKID1,INPUT_PULLUP);
    pinMode(BLOCKID2,INPUT_PULLUP);
    pinMode(BLOCKID3,INPUT_PULLUP);
    pinMode(BLOCKID4,INPUT_PULLUP);
    pinMode(BLOCKID5,INPUT_PULLUP);
    Common_Anode = digitalRead(LEDCOMMONMODE);
    Bicolor_Search = digitalRead(BICOLORSEARCH);
    //Serial.print("*** setup(): Common_Anode = "); Serial.println((int)Common_Anode);
    //Serial.print("*** setup(): Bicolor_Search = "); Serial.println((int)Bicolor_Search);
    Blockid = digitalRead(BLOCKID0) + 
          (digitalRead(BLOCKID1) << 1) +
          (digitalRead(BLOCKID2) << 2) +
          (digitalRead(BLOCKID3) << 3) +
          (digitalRead(BLOCKID4) << 4) +
          (digitalRead(BLOCKID5) << 5);
    // Initialize the masts
    mastE.init(Common_Anode,Bicolor_Search);
    mastW.init(Common_Anode,Bicolor_Search);
    Serial.print("MetroMiniABSBiDir-noCANSlave #");
    Serial.print(Blockid);
    Serial.println(" Starting");
    // Initialize the slave bus
    slaveBus.init(Blockid);
          
    // Set initial state.
    blockOcc.process();
    nextEast.process();
    nextWest.process();
    mastE.eval();
    mastW.eval();
}

/**
 * Loop runs the operation
 */
void loop()
{
    eastGreen.process();
    eastYellow.process();
    eastRed.process();
    westGreen.process();
    westYellow.process();
    westRed.process();
    blockOcc.process();
    nextEast.process();
    nextWest.process();
    mastE.eval();
    mastW.eval();
    
    slaveBus.process();
    delay(10); // give up time for the serial I/O code to get cycles
}

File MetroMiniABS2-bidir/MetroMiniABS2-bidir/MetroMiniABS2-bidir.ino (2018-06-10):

/**
 * MetroMiniABS.ino -- An OpenLCB node that implements a single Automatic Block
 * Signal.  This node presumes the hardware detailed at 
 * https://github.com/RobertPHeller/RPi-RRCircuits/tree/master/MetroMiniABS
 * This board uses an Adafruit Metro Mini, which is a Arduino Uno R3 clone on 
 * a mini form factor: 1.7"x.7", with 28 pins as two rows of 14 .6" with a .1" 
 * pitch (same footprint as a wide DIL-28).
 *
 * I/O pin usage:
 *
 * D4 Blue Button/Led
 * D7 Gold Button/Led
 * D8 Occupancy Detector
 * A4 SDA
 * A5 SCL
 *
 * Events used:
 *
 * Consumed:
 *   Next Block East Occupied
 *   Next Block East Clear
 *   Next Block West Occupied
 *   Next Block West Clear
 * Produced:
 *   Block Occupied
 *   Block Clear
 *   East Stop Aspect Triggered
 *   East Stop Aspect Released
 *   East Approach Aspect Triggered
 *   East Approach Aspect Released
 *   East Clear Aspect Triggered
 *   East Clear Aspect Released
 *   West Stop Aspect Triggered
 *   West Stop Aspect Released
 *   West Approach Aspect Triggered
 *   West Approach Aspect Released
 *   West Clear Aspect Triggered
 *   West Clear Aspect Released
 *
 * Additional configuration:
 *
 * BiPolar Searchlight: Yes/No
 * Stop (red) Brightness: 0-255
 * Approach (yellow) Brightness: 0-255
 * Clear (green) Brightness: 0-255
 * Yellow Hue (ratio of red to green): 0-255
 *
 */
// OlcbBasicNode
//   A prototype of a basic 4-channel OpenLCB board
// 
//   setup() determines which are consumers and
//   which are producers
//
//   Bob Jacobsen 2010, 2012
//      based on examples by Alex Shepherd and David Harris
//==============================================================

// next line for stand-alone compile
#include <Arduino.h>

#include <ctype.h>
#include <stdarg.h>
#include <stdio.h>
#include <avr/pgmspace.h>
#include "logging.h"

// The following lines are needed because the Arduino environment 
// won't search a library directory unless the library is included 
// from the top level file (this file)
#include <EEPROM.h>
#include <can.h>
#include <ButtonLed.h>
#include <Wire.h>
#include "TLC59208F.h"
#include "ButtonLed_nobutton.h"
#include "ButtonLed_nc.h"
#include "ButtonLed_noled.h"
#include "SignalOptions.h"
#include "Mast.h"


#include "OlcbCommonVersion.h"
#include "NodeID.h"

// init for serial communications if used
#define         BAUD_RATE       57600

NodeID nodeid(0x05,0x01,0x01,0x01,0x22,0x80);    // This node's default ID; must be valid 

// Define pins
#define BLUE 4
#define GOLD 7

#define BLOCKOCC 8 // No led!
#define ESIGNALGREEN 0 // No button 
#define ESIGNALYELLOW 1 // No button
#define ESIGNALRED 2 // No button
#define WSIGNALGREEN 3 // No button 
#define WSIGNALYELLOW 4 // No button
#define WSIGNALRED 5 // No button

TLC59208F tlc59208f;


ButtonLed_noled blockocc(BLOCKOCC,LOW); // No LED (sense only)
ButtonLed_nc nextblockE(0); // No actual pin (state set by event)
ButtonLed_nc nextblockW(0); // No actual pin (state set by event)
ButtonLed_nobutton signalgreenE(ESIGNALGREEN,&tlc59208f); // No button, LED only
ButtonLed_nobutton signalyellowE(ESIGNALYELLOW,&tlc59208f); // No button, LED only
ButtonLed_nobutton signalredE(ESIGNALRED,&tlc59208f); // No button, LED only
ButtonLed_nobutton signalgreenW(WSIGNALGREEN,&tlc59208f); // No button, LED only
ButtonLed_nobutton signalyellowW(WSIGNALYELLOW,&tlc59208f); // No button, LED only
ButtonLed_nobutton signalredW(WSIGNALRED,&tlc59208f); // No button, LED only

struct {
    char nodename[20];
    char nodedescr[24];
    SignalOptions signalOptions;
} configOptions;

Mast mastE(&blockocc,&nextblockE,
          &signalgreenE,&signalyellowE,&signalredE,
          &(configOptions.signalOptions));
Mast mastW(&blockocc,&nextblockW,
          &signalgreenW,&signalyellowW,&signalredW,
          &(configOptions.signalOptions));

#define NUM_EVENT 18
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

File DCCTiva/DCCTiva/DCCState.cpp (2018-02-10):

// -!- C++ -!- //////////////////////////////////////////////////////////////
//
//  System        : 
//  Module        : 
//  Object Name   : $RCSfile$
//  Revision      : $Revision$
//  Date          : $Date$
//  Author        : $Author$
//  Created By    : Robert Heller
//  Created       : Thu Feb 1 09:51:00 2018
//  Last Modified : <180210.1505>
//
//  Description	
//
//  Notes
//
//  History
//	
/////////////////////////////////////////////////////////////////////////////
//
//    Copyright (C) 2018  Robert Heller D/B/A Deepwoods Software
//			51 Locke Hill Road
//			Wendell, MA 01379-9728
//
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
// 
//
//////////////////////////////////////////////////////////////////////////////
#define DCCLIB
#include "DCCState.h"

static const char rcsid[] = "@(#) : $Id$";

uint8_t MUList::mucount = 0;
MUList MUList::mus[MULIST_MAXMUS];
uint8_t MUList::currentPointer = 0;
uint8_t MUList::insertPointer = 0;

MUList::MUList(uint8_t muaddr) {
    unitcount = 0;
    currentSpeed = 0;
    currentSteps = 0;
    this->muaddress = muaddr;
    uint8_t p;
    for (p = currentPointer;p < mucount;p++) {
        if (mus[p].muaddress == muaddr) {
            mus[p] = *this;
            currentPointer = p;
            return;
        }
    }
    for (p = 0; p < currentPointer; p++) {
        if (mus[p].muaddress == muaddr) {
            mus[p] = *this;
            currentPointer = p;
            return;
        }
    }
    if (mucount < MULIST_MAXMUS) {
        mus[mucount] = *this;
        currentPointer = mucount++;
        return;
    }
    for (p = 0; p < mucount; p++) {
        if (mus[p].muaddress == 0) {
            mus[p] = *this;
            currentPointer = p;
            return;
        }
    }
    if (insertPointer < mucount) {
        mus[insertPointer] = *this;
        currentPointer = insertPointer++;
        return;
    }
    insertPointer = 0;
    mus[insertPointer] = *this;
    currentPointer = insertPointer++;
}

MUList *MUList::muFromMuAddr(uint8_t muaddr)
{
    uint8_t p;
    for (p = currentPointer; p < mucount; p++) {
        if (mus[p].muaddress == muaddr) {
            currentPointer = p;
            return &(mus[p]);
        }
    }
    for (p = 0; p < currentPointer; p++) {
        if (mus[p].muaddress == muaddr) {
            currentPointer = p;
            return &(mus[p]);
        }
    }
    MUList newmu(muaddr);
    return &(mus[currentPointer]);
}

bool     MUList::addUnitToConsist(uint8_t muaddress, uint16_t unitaddress,bool forward)
{
    if (isMemberOfConsist(muaddress,unitaddress)) return true;
    if (DCCState::isMuOrDh(unitaddress)) return false;
    MUList *mu = muFromMuAddr(muaddress);
    
    if (mu->unitcount < MULIST_MAXUNITS) {
        mu->units[mu->unitcount] = unitaddress;
        if (forward) {
            DCCState::setSpeed(unitaddress,mu->currentSpeed,mu->currentSteps);
        } else {
            mu->units[mu->unitcount] |= DIRECTIONFLAG;
            DCCState::setSpeed(unitaddress,-(mu->currentSpeed),mu->currentSteps);
        }
        DCCState::setMu(unitaddress,mu->unitcount);
        mu->unitcount++;
    }
}

bool     MUList::deleteUnitFromConsist(uint8_t muaddress, uint16_t unitaddress)
{
    if (!isMemberOfConsist(muaddress,unitaddress)) return true;
    if (DCCState::isMuOrDh(unitaddress)) return false;
    MUList *mu = muFromMuAddr(muaddress);
    uint8_t ui, uj;
    for (ui = 0; ui < mu->unitcount; ui++) {
        if ((mu->units[ui] & ADDRMASK) == unitaddress) {
            for (uj = ui+1; uj < mu->unitcount; uj++) {
                mu->units[uj-1] = mu->units[uj];
            }
            mu->unitcount--;
            DCCState::clearMu(unitaddress);
            if (mu->unitcount == 0) {
                mu->muaddress = 0;
            }
            return true;
        }
    }
}

bool     MUList::isMemberOfConsist(uint8_t muaddress, uint16_t unitaddress)
{
    MUList *mu = muFromMuAddr(muaddress);
    uint8_t ui;
    for (ui = 0; ui < mu->unitcount; ui++) {
        if ((mu->units[ui] & ADDRMASK) == unitaddress) {
            return true;
        }
    }
    return false;
}

bool     MUList::eStop()
{
    bool result = true;
    uint8_t ui;
    for (ui = 0; ui < unitcount; ui++) {
        DCCState *loco = DCCState::LookupDecoder(units[ui] & ADDRMASK);
        result |= loco->_eStop();
    }
    return result;
}

bool     MUList::setSpeed(int8_t new_speed, uint8_t steps)
{
    bool result = true;
    uint8_t ui;
    for (ui = 0; ui < unitcount; ui++) {
        DCCState *loco = DCCState::LookupDecoder(units[ui] & ADDRMASK);
        result |= loco->_setSpeed(new_speed,steps);
    }
    return result;
}

uint16_t MUList::nextUnit(uint8_t muaddress, uint16_t unitaddress)
{
    uint8_t ui;
    MUList *mu = muFromMuAddr(muaddress);
    if (unitaddress == 0) {
        return (mu->units[0]) & ADDRMASK;
    } else {
        for (ui = 0; ui < mu->unitcount; ui++) {
            if ((mu->units[ui] & ADDRMASK) == unitaddress) {
                if (ui+1 == mu->unitcount) {
                    return 0;
                } else {
                    return (mu->units[ui+1] & ADDRMASK);
                }
            }
        }
        return 0;
    }
}

uint16_t MUList::prevUnit(uint8_t muaddress, uint16_t unitaddress)
{
    uint8_t ui;
    MUList *mu = muFromMuAddr(muaddress);
    if (unitaddress == 0) {
        return (mu->units[mu->unitcount-1]) & ADDRMASK;
    } else {
        for (ui = mu->unitcount-1; ui >= 0; ui--) {
            if ((mu->units[ui] & ADDRMASK) == unitaddress) {
                if (ui == 0) {
                    return 0;
                } else {
                    return (mu->units[ui-1] & ADDRMASK);
                }
            }
        }
        return 0;
    }
}

bool MUList::initState()
{
    mucount = 0;
    currentPointer = 0;
    insertPointer = 0;
    return true;
}

bool MUList::saveState(int &eaddr)
{
    uint8_t p,u;
    EEPROM.write(eaddr,mucount);
    EEPROM.write(eaddr+1,currentPointer);
    eaddr += 2;
    for (p = 0; p < mucount; p++) {
        EEPROM.write(eaddr,mus[p].unitcount);
        eaddr++;
        for (u = 0; u < mus[p].unitcount; u++) {
            EEPROM.write(eaddr,(mus[p].units[u]&0x0FF));
            EEPROM.write(eaddr+1,((mus[p].units[u]>>8)&0x0FF));
            eaddr+=2;
        }
        EEPROM.write(eaddr,mus[p].currentSpeed);
        EEPROM.write(eaddr+1,mus[p].currentSteps);
        EEPROM.write(eaddr+2,mus[p].muaddress);
        eaddr+=3;
    }
    return true;
}
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

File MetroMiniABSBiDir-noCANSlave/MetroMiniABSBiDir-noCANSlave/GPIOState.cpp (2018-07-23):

// -!- C++ -!- //////////////////////////////////////////////////////////////
//
//  System        : 
//  Module        : 
//  Object Name   : $RCSfile$
//  Revision      : $Revision$
//  Date          : $Date$
//  Author        : $Author$
//  Created By    : Robert Heller
//  Created       : Tue Jun 12 23:07:31 2018
//  Last Modified : <180723.1340>
//
//  Description	
//
//  Notes
//
//  History
//	
/////////////////////////////////////////////////////////////////////////////
//
//    Copyright (C) 2018  Robert Heller D/B/A Deepwoods Software
//			51 Locke Hill Road
//			Wendell, MA 01379-9728
//
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
// 
//
//////////////////////////////////////////////////////////////////////////////

static const char rcsid[] = "@(#) : $Id$";

#include "GPIOState.h"


GPIOState::GPIOState(const uint8_t p,uint8_t s) : sense(s), pin(p) {      // define Button with pin and sense, 
//                                        // Arduino pin the button/LED is attached
//                                        // sense: HIGH=active high, LOW=active low. 
  init(s);
}

GPIOState::GPIOState(uint8_t p) : pin(p) {            // default to sense=HIGH
  init(HIGH);
}

GPIOState::GPIOState() {
}

void GPIOState::setPinSense(uint8_t p, uint8_t s) {
    pin = p;
    init(s);
}

void GPIOState::init(uint8_t s)
{
    sense = s;
    pinMode(pin,INPUT_PULLUP);
    lastState=false;
    duration=lastDuration=0;
    state=false;
}

//     state: F T T F
// lastState: F T T F
//   returns: F T F F 

void GPIOStateIn::process()
{
  long now = millis();
  int period = now & 0xFFE0;                    // each period is 32 ms
  if(period != lastButtonPeriod) {              // If we are in a new period
    lastButtonPeriod = period;                  // .. remember it
    newState = (sense == digitalRead(pin));     // .. and read it, is the button up or down
      //Serial.print("*** GPIOStateIn::process(): newState = ");
      //Serial.println(newState);
    if(newState != lastState) {                 // ..if button changed then..
      lastState = newState;                     // ....remember the button state
    } else {                                    // ..else its position is stable and so debounced
      if(state != newState) {                   // ....But is it a new state?..
        state = newState;                       // .....yes, so update
          //Serial.print("*** GPIOStateIn::process(): state = ");
          //Serial.println(state);
        lastDuration = duration + 32;           //       and remember the duration of the last state
        timeOfLastChange = now;                 //       so we can calc duration
        duration = 0;                           //       start timing new state
      } else {                                  // .....no, the same state is continuing, so
        duration = millis() - timeOfLastChange; // ......calculate its duration
      } 
    }
  }
  return;
}

void GPIOStatePWMOut::process() {
    //Serial.print("*** GPIOStatePWMOut::process(): pin = ");
    //Serial.println(pin);
    //Serial.print("*** GPIOStatePWMOut::process(): brightness = ");
    //Serial.println(brightness);
    analogWrite(pin, brightness);
    return;
}

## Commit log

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2017-02-01 fix conflict
    [QuadSSSQuadIn.sch]
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2017-04-18 Change QuadSSSQuadIn to have buffered 5V inputs, with +5V and ground available
    [QuadSSSQuadIn.kicad_pcb, QuadSSSQuadIn.sch]
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2017-04-20 Small typo error fixed
    [CANHat.sch]
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2017-04-20 Updated part number for the crystal (correct load cap.).
    [CANHat.csv, CANHat.sch]
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2017-04-23 Update partnumbers (fix incorrect ones)
    [SMCSenseHAT.sch, SMCSenseHAT1.sch]
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2017-04-28 Add power injection and CAN shield and CAN ground connections to the CAN connectors.
    [CANHat.sch]
2017-04-28 Add footprints for power injection and update PCB to include power injection and CAN ground and shield.
    [CANHat.csv, CANHat.kicad_pcb, CANHat.sch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]
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2017-04-29 Fix comma in cap values (C3 C4).
    [DualUncouplerHAT.csv, DualUncouplerHAT.sch, DualUncouplerHAT_mouser.csv]
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2017-05-07 Use Molex Shrouded, keyed headers (update schematic, parts list, and 3D objects on the PCB), adjust the PCB to allow clearance for these headers.
    [SignalHAT.csv, SignalHAT.kicad_pcb, SignalHAT.sch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]
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2017-05-10 Fix incorrect pin (13) number and add missing track (fourth output).
    [QuadSSSQuadIn.kicad_pcb, QuadSSSQuadIn.sch]
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2017-05-17 Revert "Add MCP23008 Hat."
    This reverts commit cbf024b8f239d1533153b32dd6cb0396abe32c16.
    [MCP23008Hat.kicad_pcb, MCP23008Hat.sch]
2017-05-17 Revert "Revert "Add MCP23008 Hat.""
    This reverts commit 006b9f55e91b76036943d268fc65fa69f3c18311.
    [MCP23008Hat.kicad_pcb, MCP23008Hat.sch]
2017-05-18 Add missing 3d shape.
    [QuadSSSQuadIn.kicad_pcb]
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2017-06-04 Update modules on Boards (replace SILs with pin_arrays/screw terms. Add missing rsil-5 3D shape.
    [QuadSSSQuadIn.kicad_pcb, SMCSenseHAT.kicad_pcb, SMCSenseHAT1.kicad_pcb]
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2017-06-10 Minor tweaks to OctalLEDDriver: adjusr board size to integreal mm size, make resistor values visible, adjust LED load resistor values.
    [OctalLEDDriver.kicad_pcb, OctalLEDDriver.sch]
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2017-06-24 Remove probably wrong header version of 16LEDDriver23017SMD
    [16LEDDriver23017SMD.kicad_pcb, 16LEDDriver23017SMD.sch, drivers.sch]
2017-06-24 Replace with through hole header (allows for stacking header).
    [16LEDDriver23017SMD.kicad_pcb, 16LEDDriver23017SMD.sch, drivers.sch]
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2017-06-25 Shorten resistor values (remove " Ohms") to better fit the silk screen.
    [16LEDDriver23017SMD.kicad_pcb, 16LEDDriver23017SMD.sch, drivers.sch]
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2017-06-26 Added SMD Quad Stall Motor driver/sense hat.
    [Motors.sch, QuadSMCSenseHatSMD.kicad_pcb, QuadSMCSenseHatSMD.sch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]
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2017-07-09 Move terminal markings to be more visible once the terminal blocks have been installed.
    [MCP23017.kicad_pcb, OctalLEDDriver.kicad_pcb]
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2017-10-05 Update GPIO Hats: make all 17 GPIO pins available on a socket header strip.
    [ButtonHat.kicad_pcb, ButtonHat.sch, LEDDriverHat.kicad_pcb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]
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2017-10-19 QuadSignalDriverCA added (4 heads w/4 LEDs/head, using a MCP23017 and 4 MPQ2222As).
    [QuadSignalDriverCA.kicad_pcb, QuadSignalDriverCA.sch]
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2017-10-21 Create a common cathode version of a Quad Signal Driver (4 heads, 4 LEDs/head).
    [QuadSignalDriverCK.kicad_pcb, QuadSignalDriverCK.sch]
2017-10-21 Add missing 3d shapes (ele. caps.).
    [QuadSignalDriverCA.kicad_pcb, QuadSignalDriverCK.kicad_pcb]
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2018-02-03 Move to using the Arduino IDE (problems with the Arduino Makefile tool).
    [DCCControler.ino, DCCShield.ino, DCCState.cpp]
2018-02-05 Added get information command, fixed auto save state logic
    [DCCShield.ino, DCCState.cpp]
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2018-03-01 Update (original) CANHat to include powering the tranciever from the LCC and to add on-board termination.
    [CANHat.kicad_pcb, CANHat.sch]
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2018-03-10 Finished circuit pattern for TivaInterchangeSMD, update schematic (renumbered transistors to facilitate circuit pattern).
    [QuadSignalHead.sch, SMCSense.sch, TivaInterchangeSMD.kicad_pcb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]
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2018-03-12 Fix headers to use circular/square pads!
    [TivaInterchangeSMD.kicad_pcb]
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2018-03-13 Revert "Minor update: update sheet page settings."
    This reverts commit bf3084cbe6caf5b1f3efbe765da62b66a3d1dd48.
    [CANTranceiver.sch]
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2018-03-15 Minor updates to WS2811_SignalHead: adjust terminal points on the signal head board.
    [WS2811_SignalHead.kicad_pcb]
2018-03-15 Updated WS2811_SignalHead: Signal Head board matches Oregon Rail signal heads. Updated driver board to be 25.4 mm x 31.8 mm, using 3.7mm mounting holes.
    [WS2811_SignalHead.kicad_pcb]
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2018-05-16 Redo the tracks for FullInterlockingPlantCANPower, using fatter tracks for the power traces and with a full ground plane.
    [FullInterlockingPlantCANPower.kicad_pcb]
2018-05-17 Fix two wrong sized vias.
    [FullInterlockingPlantCANPower.kicad_pcb]
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2018-05-24 Regenerate the PDF, Postscript, and Gerber files (added Blue and Gold buttons).
    [MetroMiniABS-B_Cu.gbl, MetroMiniABS-B_SilkS.gbo, MetroMiniABS-Cmts_User.gbr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]
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2018-05-26 Update XML to *correctly* map the event struct. Add ButtonLed_noled class, minor updates to other ButtonLed subclasses.
    [ButtonLed_noled.cpp]
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2018-06-12 MetroMiniABSBiDir-noCANSlave: MetroMini ABS, Bidirectional, no CAN/LCC bus -- instead will have a (simple) RS422 style slave bus, and daisy-chained detector.
    [MetroMiniABSBiDir-noCANSlave.kicad_pcb, MetroMiniABSBiDir-noCANSlave.sch]
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2018-06-16 Changed slave serial pins from PA2/3 (USART2) to PB6/7 (USART1) -- avoid conflicts with other uses.
    [STM32ShieldForMetroMiniSlaves-B_Cu.gbl, STM32ShieldForMetroMiniSlaves-B_Mask.gbs, STM32ShieldForMetroMiniSlaves-B_SilkS.gbo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]
2018-06-17 Start to convert ABSSlaveBus to run as a separate thread. Small fix to main.cxx: add refresh loop for the turnouts.
2018-06-17 Change pins and UART (again): Block occ pins on PortA of DevIO Board, UART on PA9 and PA10.
    [STM32ShieldForMetroMiniSlaves-B_Cu.gbl, STM32ShieldForMetroMiniSlaves-B_Mask.gbs, STM32ShieldForMetroMiniSlaves-B_SilkS.gbo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]
2018-06-17 Updated: correct swapped pins (opps!).
    [STM32ShieldForMetroMiniSlaves-B_Cu.gbl, STM32ShieldForMetroMiniSlaves-B_Mask.gbs, STM32ShieldForMetroMiniSlaves-B_SilkS.gbo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]
2018-06-18 Minor event related updates to StallMotorWithSense.cxx: add in producer events to the registry, etc.
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2018-07-22 Updated board to use a screw term for power as well as DC Power jack.
    [MetroMiniABSBiDir-noCANSlave.kicad_pcb, MetroMiniABSBiDir-noCANSlave.sch]
2018-07-22 Initial static debugging fixes
    [ABSSlaveBus.cpp, GPIOState.cpp, Mast.cpp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]
2018-07-23 Breadboard static debugging fixes
    [GPIOState.cpp, Mast.cpp, MetroMiniABSBiDir-noCANSlave.ino]
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2018-08-21 Fixes to MetroMiniABSBiDir-noCANSlave board: fix signal terminal label
    [MetroMiniABSBiDir-noCANSlave.kicad_pcb, MetroMiniABSBiDir-noCANSlave.sch]
2018-08-29 Refactor StallMotorWithPointSense into two classes: PointSense and StallMotor. Update Mast* classes to us the PointSense objects.
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2018-10-20 Add missing bypass caps.
    [BBBHalfSiding.kicad_pcb, CANBUSDriver.sch, Sensors.sch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]
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2019-02-23 Remove CAN bus driver from QuadSMCSenseCape (delegate that to a dedicated Cape).
    [CANBUSDriver.sch, CapeEEPROM.sch, QuadSMCSenseCape.kicad_pcb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]
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2019-02-24 Add missing sheet.
    [CapeEEPROM.sch]
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2019-02-26 Add second Schockity diode to protect LCC/CAN power injection on the LCCCANCape.
    [CapeEEPROM.sch, LCCCANCape.kicad_pcb, LCCCANCape.sch]
2019-03-02 Swapped the mcp2551 CAN transceiver (5V) out and a SN65HVD233-HT CAN transceiver (3.3V) in.
    [CapeEEPROM.sch, LCCCANCape.kicad_pcb, LCCCANCape.sch]
2019-03-03 Updated LCCCANCape to use a TCAN332 (SMD) transceiver). The Through Hole version is available still in the -TH.* files.
    [LCCCANCape-TH.kicad_pcb, LCCCANCape-TH.sch, LCCCANCape.kicad_pcb]
2019-03-03 LCCCANCape updated to use either a Through Hol transceiver (SN65HVD233-HT) *OR* a SMD transceiver (TCAN332DR).
    [CapeEEPROM.sch, LCCCANCape-TH.kicad_pcb, LCCCANCape-TH.sch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]
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2019-03-03 Create a base mounting board for a PocketBeagle that also contains a CAN transciver with a pair of RJ45s.
    [PocketBeagleBaseBoard.kicad_pcb, PocketBeagleBaseBoard.sch]
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2019-03-10 Fix jumper options for OE.
    [16PWMLedDriverCape.kicad_pcb, 16PWMLedDriverHat.kicad_pcb, PCA9685Driver.sch]
2019-03-10 *Finally* fix jumper options for OE.
    [16PWMLedDriverCape.kicad_pcb, 16PWMLedDriverHat.kicad_pcb]
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2019-03-11 Fix pad size for DIP-28__700: allow for pin headers, rather than actual dip leads.
    [16PWMLedDriverCape.kicad_pcb, 16PWMLedDriverHat.kicad_pcb, 16PWMLedDriverPocketBeagle.kicad_pcb]
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2019-03-16 Fix up silk on ESP32QuadSMCSense.
    [ESP32QuadSMCSense.kicad_pcb]
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2019-03-16 Minor fixes to LCCCANCape: cap and eeprom footprint fixes.
    [LCCCANCape.kicad_pcb]
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2019-03-28 Update 16DriverOutputHAT to user a 12V supply for the LEDs, adding a screw terminal for the 12 supply and changing the load resistors to 1.5K.
    [16DriverOutputHAT.kicad_pcb, 16DriverOutputHAT.sch]
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2019-04-09 Fix I2C connections to match software settings.
    [CAN_Transeiver.sch, ESP32-16LedDriver.kicad_pcb, ESP32-16LedDriver.sch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]
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2019-04-25 Move terminal labels on QuadSMCSenseCape -- make them visible even after assembly.
    [QuadSMCSenseCape.kicad_pcb]
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2019-07-01 Update QuadOCDectCape to correct GPIO conflict with QuadSMCSenseCape
    [CapeEEPROM.sch, OD1.sch, OD2.sch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]
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2019-07-04 Add serial pass-through header to 16DriverOutputCape. Also fix swapped I2C lines.
    [16DriverOutputCape.kicad_pcb, 16DriverOutputCape.sch, CapeEEPROM.sch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]
2019-07-04 Also fix swapped I2C lines in 16PWMLedDriverCape.
    [16PWMLedDriverCape.kicad_pcb, 16PWMLedDriverCape.sch, CapeEEPROM.sch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]
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2019-07-05 Move Pocket Beagle SDA usage from I2C2 to I2C1 (reserved I2C for eeprom?).
    [16PWMLedDriverPocketBeagle.kicad_pcb, 16PWMLedDriverPocketBeagle.sch, CAN_Transeiver.sch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]
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2019-07-14 Fix GPIO number error on PocketBeagleQuadSMCSense.
    [PocketBeagleQuadSMCSense.sch]
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2019-08-31 Fix modules for diodes on ESP32QuadSMCSense.
    [ESP32QuadSMCSense.kicad_pcb]
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2019-10-23 Add temporature sensor, fan control, and adjust the DCC signals to match PRU I/O lines.
    [BBBCommandStation.kicad_pcb, BBBCommandStation.sch, CANTransceiver.sch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]
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2020-02-09 Add missing schematics for ESP32-PWMHalfSiding.
    [CAN_Transeiver.sch, ESP32-PWMHalfSiding.sch, OD1.sch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]
2020-02-09 Remove unneeded address jumpers from ESP32-PWMHalfSiding and fixup board part labels.
    [CAN_Transeiver.sch, ESP32-PWMHalfSiding.kicad_pcb, ESP32-PWMHalfSiding.sch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]
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2020-11-23 Revert BufferBoard-2.fzz
    [BufferBoard-2.fzz]
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2021-03-03 Completed schematic and footprint bindings
    [CANTransceiver.sch, FanControl.sch, OpsDriver.sch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]
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2021-04-06 Add missing include file fir RailcomPrintfFlow.
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2021-04-11 Fix small circuit error with PocketBeagleCommandStation.
    [PocketBeagleCommandStation.kicad_pcb, PowerSupply.sch]
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2021-04-15 Minor fixes (cleaning up extra fields in the schematic).
    [OpsDriver.sch, PocketBeagleCommandStation_SMD.sch, ProgAltDriver.sch]
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2021-04-16 Assorted minor typo errors fixed, missing Mouser part numbers (and one part replaced due to stocking issues).
    [CANTransceiver.sch, FANControl.sch, PocketBeagleCommandStation_SMD.sch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]
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2021-04-22 Minor fixes to ESP32-PWMHalfSidingSMD PCB.
    [ESP32-PWMHalfSidingSMD.kicad_pcb]
2021-04-22 Cosmetic fixes to PocketBeagleCommandStation (SMD version).
    [PocketBeagleCommandStation_SMD.kicad_pcb]
2021-04-24 Add railcom_hub.reset() and a no-ThermFault PB target.
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2021-05-11 Cosmetic fixes to PocketBeagleCommandStation_SMD.
    [PocketBeagleCommandStation_SMD.kicad_pcb]
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2021-05-26 Add 3D files for the through hole parts and update documenation for ESP32-PWMHalfSidingSMD.
    [CAN_Transeiver.sch, ESP32-PWMHalfSidingSMD.kicad_pcb, ESP32-PWMHalfSidingSMD.sch]
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2021-10-12 Final bug fixes for ESP32-PWMHalfSiding.ino
    [Mast.cpp]
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2021-10-22 Isolate buffer outputs from +12 supply. on the Pocket Beagle Multifunction Board.
    [Buttons4LEDs4.sch, PocketBeagleMultifuntion.kicad_pcb]
2021-10-24 Fixes to MegaIOOpenMRN 64 Line Hardware.hxx.
    [Buttons4LEDs4.sch, CAN_Transeiver.sch, ESP32-MultiFunction.sch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]
2021-10-24 Restore broken files.
    [Buttons4LEDs4.sch, CAN_Transeiver.sch, ESP32-MultiFunction.sch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]
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2022-02-26 Added ESP32 Octal Stall Motor
    [CAN_Transeiver.sch, ESP32-TTGO-T7-OctalStallMotor.kicad_pcb, ESP32-TTGO-T7-OctalStallMotor.sch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]
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2022-03-01 Revert ESP32-PWMHalfSiding Turnout.h
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2022-06-23 Fix incorrect I/O pin assignments.
    [ESP32-D0WD-V3-MultiFunction.kicad_pcb, ESP32-D0WD-V3-MultiFunction.sch, ESP32-MCU.sch]
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2022-06-25 Fixed all compilation errors (I think).
    [Mast.cpp]
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2022-07-29 Fixed footprints for DFLS240-7s.
    [CAN_Transceiver.sch, ESP32-D0WD-V3-MultiFunction.kicad_pcb, PCA9685Driver.sch]
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2022-08-24 Clean up silk, minor adjustments, and add missing 3d shapes to PB Command Station.
    [PocketBeagleCommandStation_SMD.kicad_pcb]
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2022-08-25 Fix DWS Logo orientation.
    [ESP32-S3-MultiFunction.kicad_pcb]
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2022-08-27 Fix minor part number and footprint error.
    [ESP32-MCU.sch, PCA9685Driver.sch]
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2022-08-28 Replace D_Shockley with D_Schottky.
    [CANTransceiver.sch, CAN_Transceiver.sch, ESP32-C3-Booster.sch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]
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2022-08-31 Adjust power labeling and change the LCC logo to a larger version.
    [ESP32-S3-MultiFunction.kicad_pcb]
2022-09-01 Add a terminal block to provide external stall motor power.
    [CAN_Transceiver.sch, ESP32-S3-MultiFunction.kicad_pcb, OccDetect4.sch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]
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2022-09-01 Minor (cosmetic) fixes.
    [ESP32-S3-MultiFunction.kicad_pcb]
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2022-09-11 Assorted cosmetic fixes (symbols, logo, copyright, etc.)
    [LPC1754-MultiIOBoard.kicad_pcb]
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2022-10-07 Start on ESP32-S3/LCC SMINI replacement.
    [CanTransciver.sch, ESP32-S3-MultiIO.kicad_pcb, ESP32-S3-MultiIO.sch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]
2022-10-08 Completed ESP32-S3-MultiIO (LCC SMINI replacement).
    [CanTransciver.sch, Card0.sch, Card1.sch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]
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2022-10-10 Completed Stall Motors.
    [ESP32-S3-MegaMultiFunction.kicad_pcb]
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2022-10-14 Working on BOM, corrected some transistor footprints, etc.
    [OpsDriver.sch, PocketBeagleCommandStation.kicad_pcb, ProgAndLCCAltHL.sch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]
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2022-10-24 Fix footprint for OC Diodes.
    [ESP32-S3-MultiFunction.kicad_pcb, OccDetect4.sch]
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2022-11-16 Add missing resistors on the bases of Q3 and Q4.
    [PocketBeagleCommandStation.kicad_pcb, ProgAndLCCAltHL.sch]
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2023-10-27 Add Missing upgrade files.
    [CapeEEPROM.kicad_sch, LCCCANCape.kicad_sch]
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2024-04-29 Minor PCB adjustments. Firmware fixes.
    [STM32F767ZI_LCC_PNET_Router.kicad_pcb]
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2024-04-30 Add missing 3D shapes. Update documentation.
    [STM32F767ZI_LCC_PNET_Router.kicad_pcb]
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2024-05-02 Add logo symbols and copyright. Fixed power supply connection.
    [STM32F767ZI_LCC_PNET_Router.kicad_pcb, STM32F767ZI_LCC_PNET_Router.kicad_sch]
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2024-05-05 Completed drift of the kit booklet.
    [FRED.kicad_pcb]
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

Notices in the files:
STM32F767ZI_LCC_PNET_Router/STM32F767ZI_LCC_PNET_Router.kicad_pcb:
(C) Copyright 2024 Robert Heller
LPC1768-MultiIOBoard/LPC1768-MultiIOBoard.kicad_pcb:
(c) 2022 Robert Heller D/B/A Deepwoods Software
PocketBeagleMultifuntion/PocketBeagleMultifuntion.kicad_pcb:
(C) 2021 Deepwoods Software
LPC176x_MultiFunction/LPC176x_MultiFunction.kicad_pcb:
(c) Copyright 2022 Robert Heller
